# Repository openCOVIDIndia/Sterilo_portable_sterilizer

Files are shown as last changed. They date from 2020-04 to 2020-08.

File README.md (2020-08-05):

# Sterilo - Portable UV-C Steriliser
## Version 2 is here 
### Prototyping and Validation Stage





# Version 1 
## Fully developed and documented

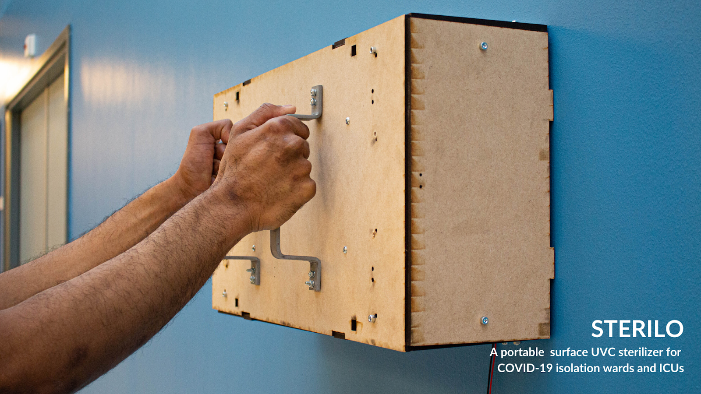
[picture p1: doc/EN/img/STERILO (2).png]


Sterilo is an open-source, low-cost portable UV-C sterilizer for decontaminating common surface touchpoints in isolation wards and ICUs. It is designed to be DIY-friendly, allowing the possibility of decentralised manufacturing using locally  available materials.

## [For more information on UV research and contributors, read our wiki](https://github.com/openCOVIDIndia/Sterilo_portable_sterilizer/wiki)

## Background 

Amidst the raging coronavirus pandemic, sterilization of surfaces and common touch points is the key to prevent cross contamination between patients and healthcare workers and to enhance treatment, within isolation wards and Intensive care units (ICU).

Current surface disinfection methods involve spraying Sodium Hypochlorite solution (NaClO) [1] and alcohol wipes, and rinsing after a waiting time of 30 minutes, repeated 3 times a day. These methods are however not effective [2] against many microbes like bacterial spores [3] and in surfaces with high viral loads. Hence, sterilization is preferred over just disinfection. Even high level disinfectants like 2% glutaraldehyde [4] are ineffective unless exposed for 12 hours. Besides, when the healthcare workers directly come in contact (touch) with these infected surfaces while treating patients, they become carriers of infection, leading to a higher risk of COVID-19 transmission [5] within the isolation ward /ICU.

On the other hand, autoclaves are the gold standard in sterilizing smaller instruments used in ICUs and Isolation wards. Each autoclave cycle takes 30 minutes while the drying process takes an hour to remove steam residue on the instruments.  However, a surge in coronavirus patients in a given hospital might lead to exceeding the capacity of autoclaves.  

There are other disinfection methods such as Fumigation, which uses high level disinfectants like Formaldehyde [7] and Glutaraldehyde [8,9]. This method requires 10 hours of exposure time [10] and another 24 hours for the fumes to be ventilated, after fumigation is carried out in a room. However, currently in many of the Indian government hospitals, the operations resume 30 minutes, that too in poorly ventilated rooms after the fumigation which renders healthcare workers exposed to its harmful fumes. Harmful effects [11,12] include mucous membrane irritation, pulmonary symptoms, Epistaxis, allergic contact dermatitis, asthma.

Ultraviolet radiation is an effective sterilization method, commonly found in Biosafety cabinets. The spectrum between 254nm to 265nm usually called UV-C has the maximum germicidal effect.[13] However, this method is currently not used in hospitals due to its harmful effects to human beings on exposure like skin cancer and eye damage [14].

Existing UVC Sterilizer robots [15] and trolley models [16] that are being introduced in the market to sterilize isolation wards require the people in the ward to vacate the ward while it sterilizes, since it places patients at risk of exposure to UVC radiation. But vacating is not logistically feasible, especially in Indian government hospitals. Hence the main need is to effectively sterilize frequently touched surfaces without causing harmful effects to patients and healthcare workers.

<p float="left">
    
  
   
</p>

## Need
- ### Surfaces:
Effective sterilization methods for fixed touch points (surfaces) within isolation wards and ICUs.

- ### Complement autoclaves
Supplementary sterilization for instruments, in addition to autoclaves, to reduce their overuse.

- ### Need for reuse of Personal protective equipment
Reuse of N-95 respirators for non-medical staff so that it is available to medical staff working in high viral loads like in isolation wards and ICUs.

# Solution

Sterilo, a portable surface sterilizer that uses UV-C radiation to sterilize common touch points within ICUs and isolation wards, even while the patient is present in its proximity and no special shielding is required. Safety features have been incorporated to avoid accidental exposure to UVC radiation, such that only when it's clamped onto the surface, the UV lamps turn ON.

Sterilo can be used in two configurations:
## A) Clamped onto surfaces
It features suction cups that clamp onto any surface. (See picture below). Once turned ON, the sterilization process runs for 20 minutes and turns off automatically with a beep, so that the user can unclamp it and place it on the next surface.

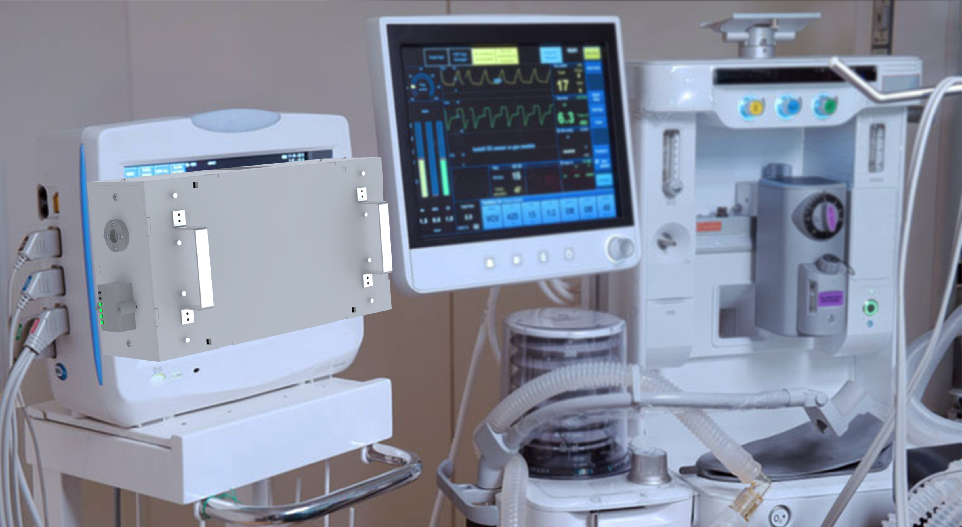
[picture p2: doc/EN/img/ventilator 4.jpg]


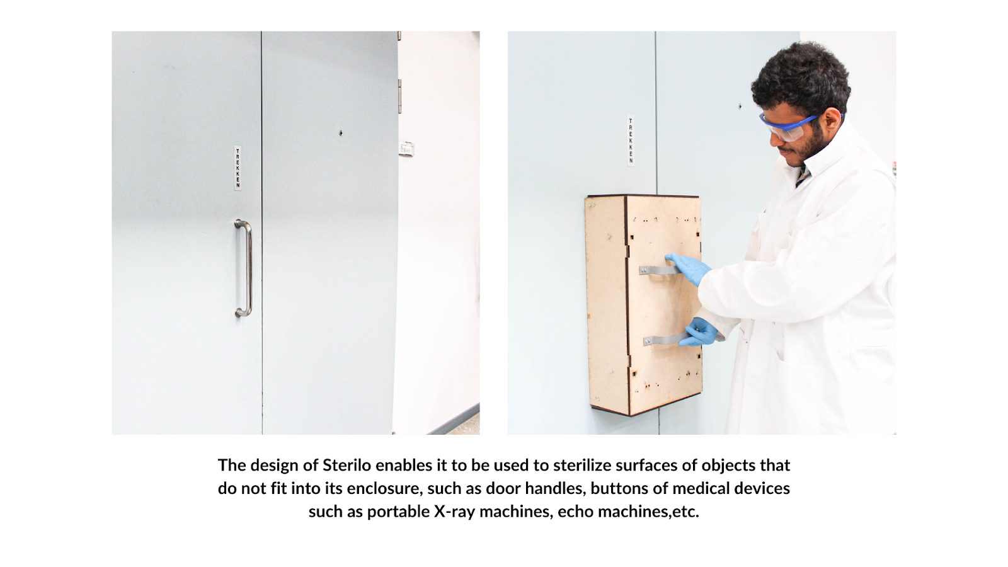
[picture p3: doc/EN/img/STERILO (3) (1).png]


## B) Box type
where a lid with an additional UV-C lamp is placed over configuration A. It is designed to hold most small instruments (for compatibility list see below). A removable mesh holds the instruments in place, while two UV-C lamps below ensures all surfaces of an object are completely exposed.

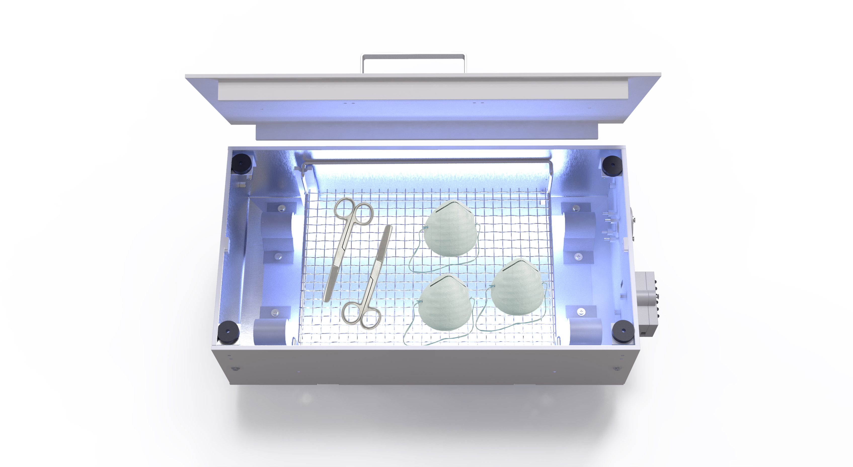
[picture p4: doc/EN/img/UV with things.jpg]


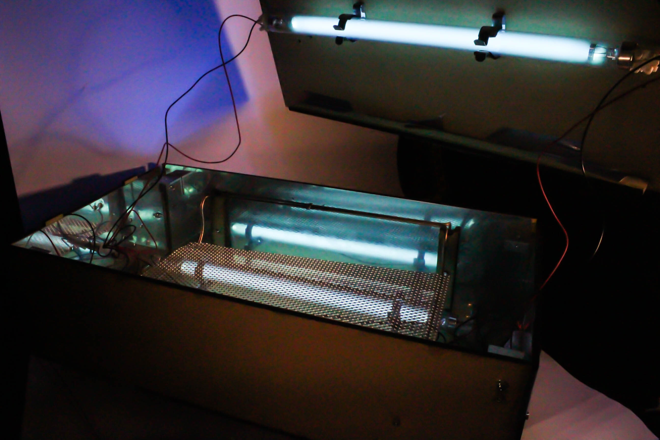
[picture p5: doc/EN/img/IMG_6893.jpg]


It is designed to sterilise most of the common touch points within isolation wards and ICUs in hospitals which includes buttons of vital monitors, ventilators, breathing units, pulse oximeters, contact thermometers, N95 masks, other touchpoints such as door handles, plugs, sockets, buttons of control units such as portable X-ray machines, echo machine controls for cardiac patients etc and even surgical equipments such as scissors, shears and tongs. The product is aimed at hospitals, makeshift wards and testing labs.

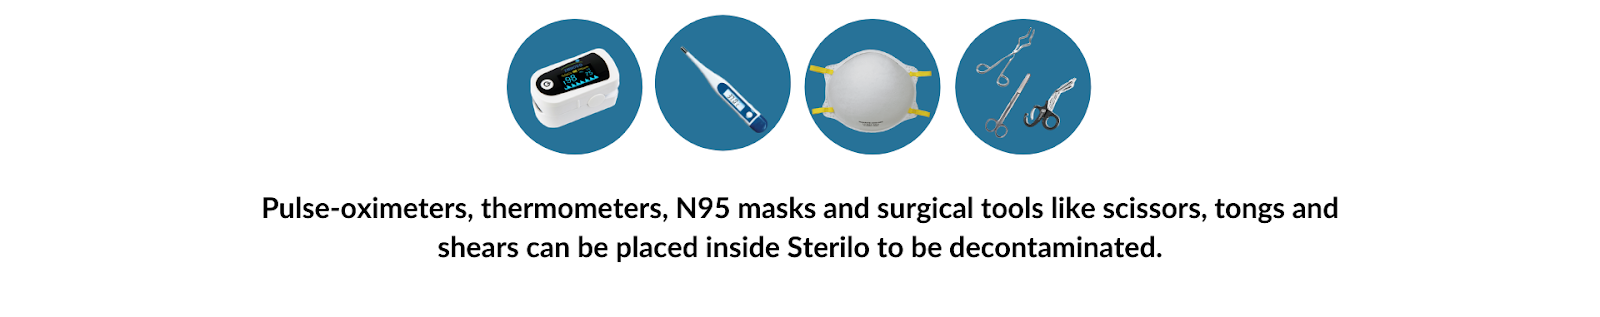
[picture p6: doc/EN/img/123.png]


Helps sterilise the following categories of objects:

- Oximeters: In isolation wards, for severe cases of patients with heart ailments, who also belong to the high risk category of COVID-19, they are monitored with oximeters
- Thermometers: At present, most of the hospitals avoid contactless thermometers because of its inaccuracy, and still rely on normal thermometers which might have more chances of being exposed to a viral load owing to it coming to contact with the COVID-19 patients.
-  N95 Masks: Flow rates drop 1.2 percent every time it is sterilised. However, when there is a shortage of N95 masks, it could be recommended to use the N95 masks after sterilisation. However the life cycle of the N95 masks have to be taken into consideration. (Currently in the hospitals, the doctors go through 6 hour shifts four times a day i.e after every six hour shift, they would need to either reuse the N95 mask or get a new one)
-  Door handles, plugs, sockets (which normally dont fit into an autoclave), surgical equipments such as scissors, clamps, tongs etc
- Buttons of commonly used control units such as portable X-ray machines, breathing unit controls, echo-machine control for cardiac patients and so on.

## Main Features

- DIY- like construction, designed for easy assembly 
- Uses extremely low cost, "off-the-shelf" parts
- Easily replicable using only laser cutting and 3D printing
- Unit mountable onto any surface to sterilize fixed objects
- Unit convertible to an enclosed box: for handheld medical tools
- Innovative design based on adopting UV-C technology in a safe and user-friendly way in a medically accepted standard.
- Shadow elimination- overall illumination by UV-C lamps
- Limit switches avoid UV exposure even in case of mishandling/unintended use cases.
- Durable and Robust Polycarbonate encasing, with sheet metal shielding
- Passive cooling system: avoids fire in case of too much heating
- Miniature Circuit Breaker at power source: to avoid short circuiting, with a 8A fuse next to it, for extra protection
- We invite anyone who is interested to follow this work.

## Experts

Interviews conducted with the following experts during the design process

- Dr. Amar, Field Doctor, Corona Ward, Pune
- Dr. Pravin Deokate, MS Ortho, Sassoon Hospital, Pune
- Dr. Abhiraj Matre, MS Ortho, Sion Hospital, Mumbai
- Dr. Abhinav Gupta, Associate Professor, Jammu University of Internal Medicine
- Dr. Atul Dhakne
- Dr. Mohammed Azhar, Apollo Hospitals, Chennai
- Dr. Sowmya Lakshminarayanan, Post Doctoral Researcher in Microbiology from Padova University, Italy
- Dr. Ram, Manila Hospital
- Dr. Gopalakrishnan.D.R.

## Status of Development

The device is currently under development, a first metal prototype is being realised.

| Date | Event |
| --- | --- |
| 23/03/2020  | Start of the project  |
| 05/04/2020  | Research and Need Assessment  |
| 27/03/2020  | Product Development (First iteration)  |
| 30/03/2020  | Concept Development (Second Iteration) |
| 12/04/2020  | First CAD Release Online |
| 13/04/2020  | Prototyping second iteration |
| 18/04/2020  | Expected Date of Completion of the second iteration |

## How to replicate 
See [Assembly Instructions](doc/EN/assembly_instructions.md)

# References
References:
- [1] Weber, D. J., Barbee, S. L., Sobsey, M. D., & Rutala, W. A. (1999). The effect of blood on the antiviral activity of sodium hypochlorite, a phenolic, and a quaternary ammonium compound. Infection Control & Hospital Epidemiology, 20(12), 821-827.
- [2] Koo, D., Bouvier, B., Wesley, M., Courtright, P., & Reingold, A. (1989). Epidemic keratoconjunctivitis in a university medical center ophthalmology clinic; need for re-evaluation of the design and disinfection of instruments. Infection Control & Hospital Epidemiology, 10(12), 547-552
- [3, 4] Rutala, W. A., & Weber, D. J. (2008). Guideline for disinfection and sterilization in healthcare facilities, 2008.
- [5] Rheinbaben, F. V., Schünemann, S., Gross, T., & Wolff, M. H. (2000). Transmission of viruses via contact in ahousehold setting: experiments using bacteriophage φX174 as a model virus. Journal of Hospital Infection, 46(1), 61-66.
- [7] Klein, M. (1963). The inavtivation of viruses by germicides. Proc Annu Meet Chem Spec Manuf Assoc, 116-118.
- [8] Gorman, S. P., SCOTT, E. M., & Russell, A. D. (1980). Antimicrobial activity, uses and mechanism of action of glutaraldehyde. Journal of Applied Bacteriology, 48(2), 161-190.
- [9] Scott EM, Gorman SP. Glutaraldehyde. In: Block SS, ed. Disinfection, sterilization, and preservation. Philadelphia: Lippincott Williams & Wilkins, 2001:361-81.
- [10] Zaidi, M., Angulo, M., & Sifuentes-Osornio, J. (1995). Disinfection and sterilization practices in Mexico. Journal of hospital infection, 31(1), 25-32.
- [11] Schnuch, A., Uter, W., Geier, J., Frosch, P. J., & Rustemeyer, T. H. (1998). Contact allergies in healthcare workers. Results from the IVDK. Acta dermato-venereologica, 78(5).
- [12] Wiggins, P., McCurdy, S. A., & Zeidenberg, W. (1989). Epistaxis due to glutaraldehyde exposure. Journal of occupational medicine.: official publication of the Industrial Medical Association, 31(10), 854-856.
- [13] Russell AD. Ultraviolet radiation. In: Russell AD, Hugo WB, Ayliffe GAJ, eds. Principles and practices of disinfection, preservation and sterilization. Oxford: Blackwell Science, 1999:688-702.
- [14] Sensakovic, J. W., & Smith, L. G. (1982). Nosocomial ultraviolet keratoconjunctivitis. Infection Control & Hospital Epidemiology, 3(6), 475-477.
- [15] “Autonomous Robots Are Helping Kill Coronavirus in Hospitals” IEEE Spectrum: Technology, Engineering, and Science News, spectrum.ieee.org/automaton/robotics/medical-robots/autonomous-robots-are-helping-kill-coronavirus-in-hospitals
- [16] “Flight of the GermFalcon: How a Potential Coronavirus-Killing Airplane Sterilizer Was Born,” IEEE Spectrum: Technology, Engineering, and Science News. [Online]. Available: https://spectrum.ieee.org/tech-talk/aerospace/aviation/germfalcon-coronavirus-airplane-ultraviolet-sterilizer-news.

<!-- # Steps to start documenting the equipment/design you found and chose 
[See this documentation example](https://github.com/CombatCovid/medical-shields-for-3d-printing). You can also download it to see the final result.
1. Download or clone this template to start documenting easily
2. Fill in the source files like STLS, CAD, etc inside

3. Use this one template to create new designs documentation
- Inside docs write down a simple README in language of choice.
- Put in the README.md the reference whre you got the source from to follow up.
- Write down steps to replicate if necessesary as well as guides in sequence.
If this part becomes difficult ask for help here in the [`#how-to-document-designs` channel ]()
 -->

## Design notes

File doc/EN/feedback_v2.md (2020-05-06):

# Feedback for prototype V2.0

| Reference | Feedback | How are we addressing?  |
| --- |:---| :-----|
| Mrs. Deepa | UV-C has the potential to cause cancer. Has her team addressed it? Can she elaborate on that in the Github write up? She says no shields are required | See [FAQ](https://github.com/openCOVIDIndia/Sterilo_portable_sterilizer/blob/master/doc/EN/FAQ.md)|
| Keshav Swarup | Plastics-not to be used in UVC sterilizer.  | See [material_research](https://github.com/openCOVIDIndia/Sterilo_portable_sterilizer/blob/master/doc/EN/material_research.md) |
| Dr.Balachandran | Good idea. There is some discussion of UV sterilisation of FFP2 / FFP3 masks throughout the world but still not yet established. Was there any test done on mask pre and post UV radiations? |  To be looked into |
| Dr.Maria | So firstly. This comes across as a machine to decontaminate things that are touched or used on or by the patient. My point of view is any decontamination is good at this point. However, objects that may have body fluids such as thongs, scissors etc would need the main type of  surgical cleaning. IMO. This is good for pulse oximeter,  blood pressure cuff, pens, stethoscope, clipboards...stationery items etc  |  FIXME|

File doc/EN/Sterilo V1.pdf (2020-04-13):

## github: opencovidindia

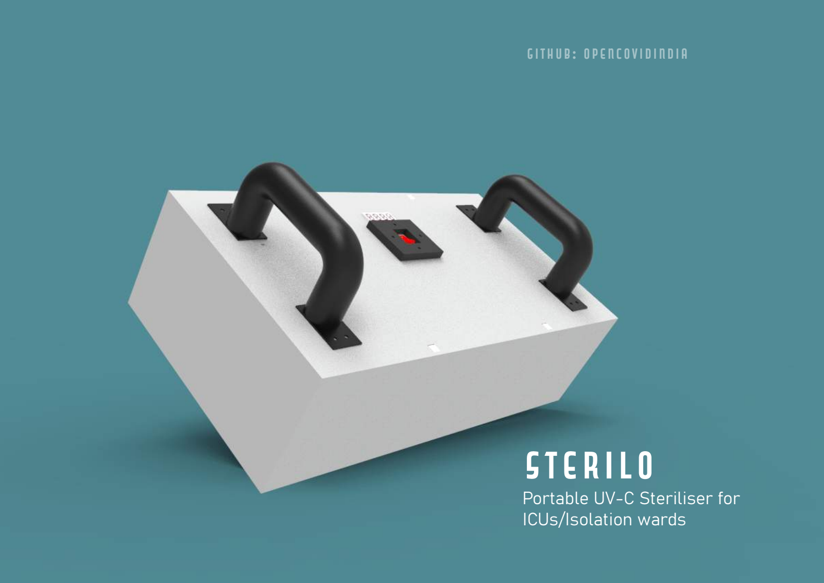
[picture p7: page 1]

# Sterilo

## Portable UV-C Steriliser for ICUs/Isolation wards

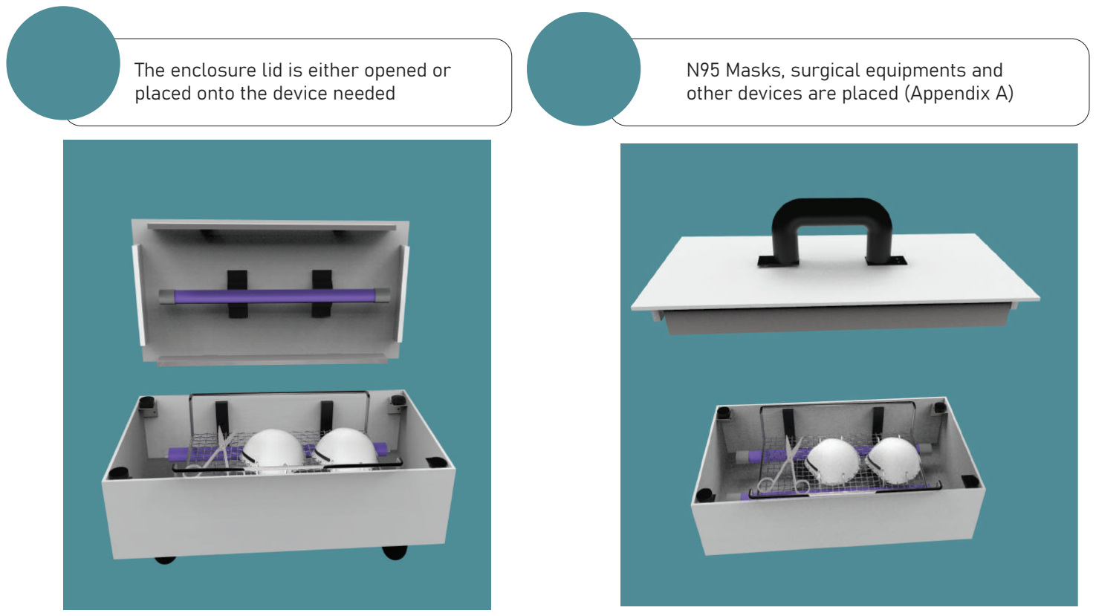
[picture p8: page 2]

The enclosure lid is either opened or placed onto the device needed

N95 Masks, surgical equipments and other devices are placed (Appendix A)

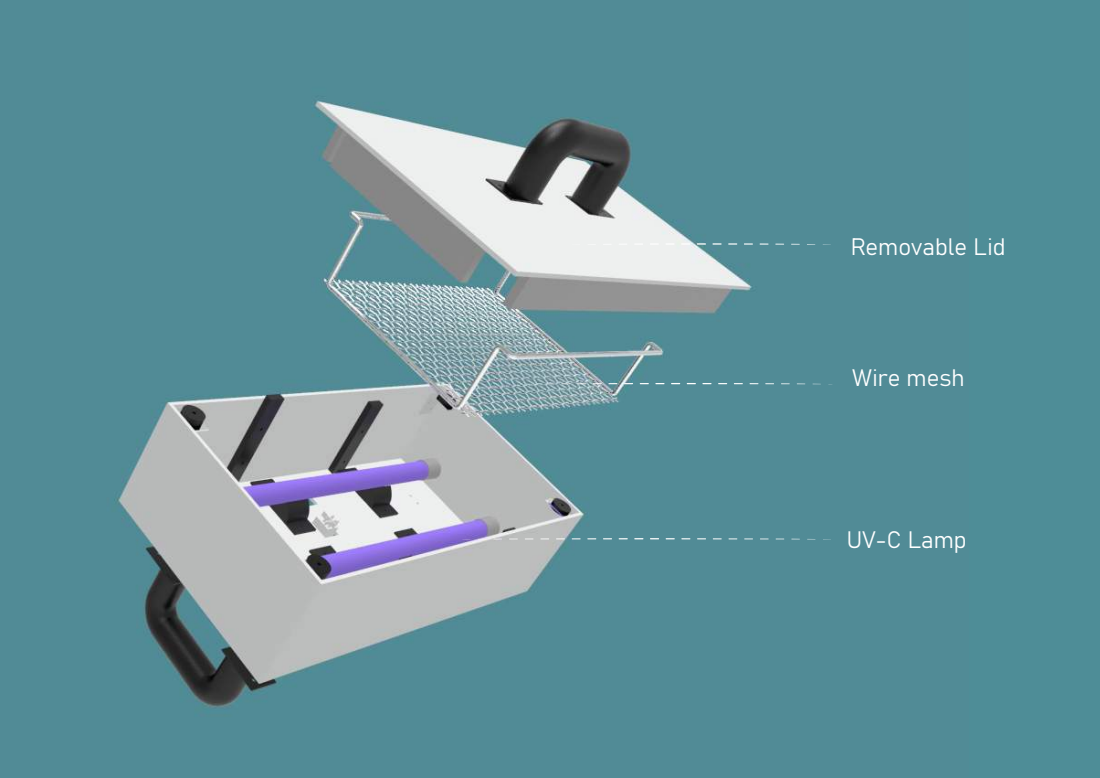
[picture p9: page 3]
Removable Lid; Wire mesh; UV-C Lamp

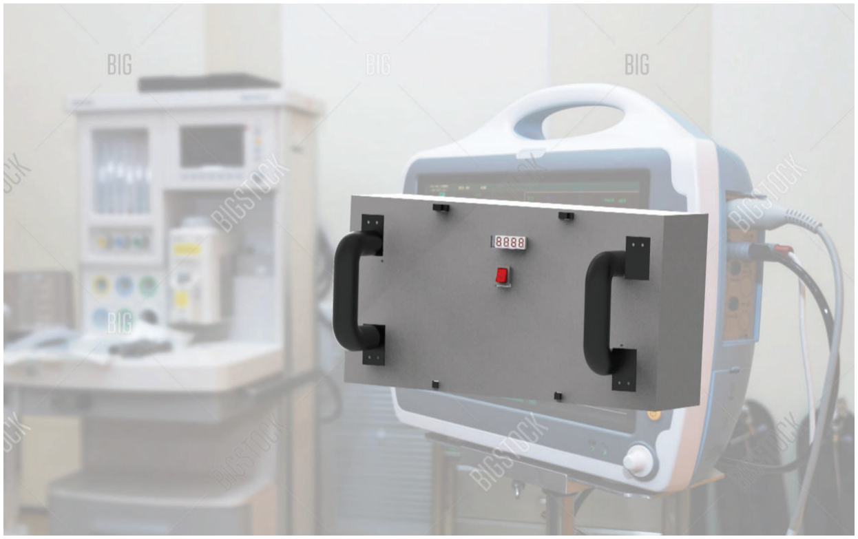
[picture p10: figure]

# Appendix a

## Helps sterilise the following categories of objects

Oximeters: In isolation wards, these are commonly used for saturated blood pressure monitoring of patients coming under the high risk category of COVID-19

Thermometers: At present, most of the hospitals avoid contactless thermometers because of its inaccuracy, and still rely on normal thermometers which might have more chances of being exposed to a viral load owing to it coming to contact with the COVID-19 patients.

N95 Masks: Flow rates drop 1.2 percent every time it is sterilised. However, when there is a shortage of N95 masks, it could be recommended to use the N95 masks after sterilisation. However the life cycle of the N95 masks have to be taken into consideration. (Currently in the hospitals, the doctors go through 6 hour shifts four times a day i.e after every six hour shift, they would need to either reuse the N95 mask or get a new one)

Door handles, plugs, sockets (which normally dont fit into an autoclave)

Surgical equipments such as scissors, clamps, tongs etc

Buttons of commonly used control units such as portable X-ray machines, breathing unit controls, echo-machine control for cardiac patients and so on.

## References

Moore, G., Ali, S., Cloutman-Green, E. A., Bradley, C. R., Wilkinson, M. A., Hartley, J. C., ... & Wilson, A. P. R. (2012). Use of UV-C radiation to disinfect non-critical patient care items: a laboratory assessment of the Nanoclave Cabinet. BMC infectious diseases, 12(1), 174.

Lindblad, M., Tano, E., Lindahl, C., & Huss, F. (2019). Ultraviolet-C decontamination of a hospital room: Amount of UV light needed. Burns.

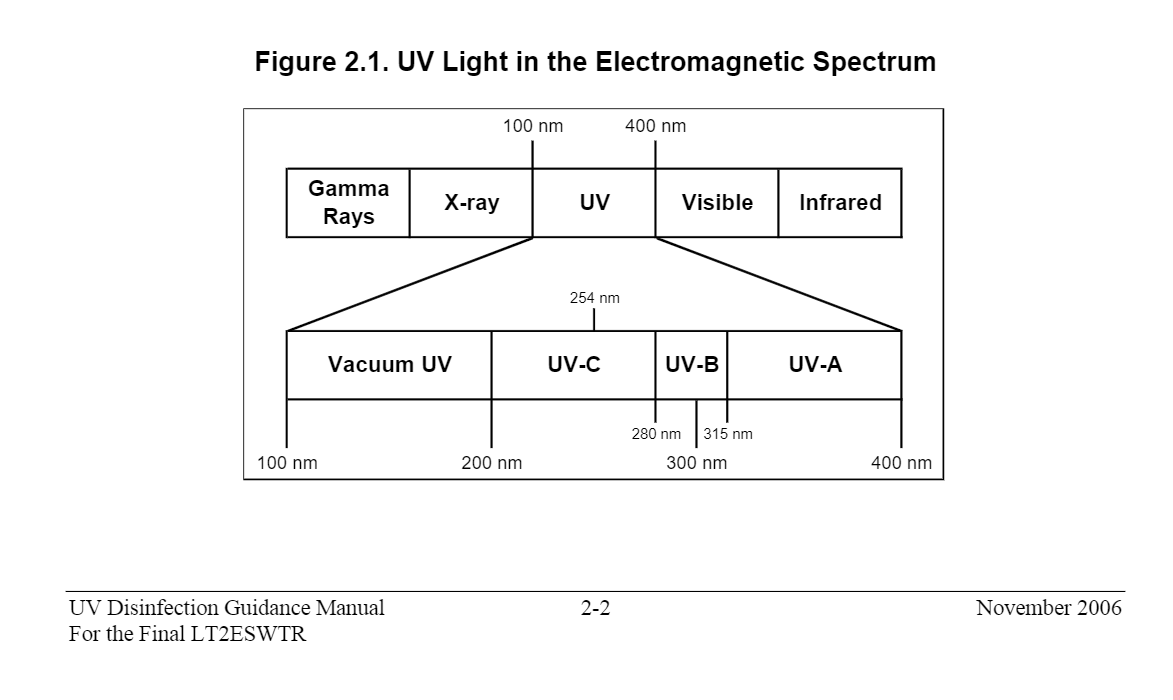
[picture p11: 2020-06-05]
doc/EN/img/research/EM_Spectrum.jpg

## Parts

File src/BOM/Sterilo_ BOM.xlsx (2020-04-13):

S No | Component | Specification | Dimensions | Qty | Part Reference | Links | Buffer parts | Place | Per unit Price | Total price
1 | Polycarbonate Sheet | UV Resistant | Thickness: 5mm 1200 x 800mm | 1 |  |  | Plus 1 sheet | Laserbeest
2 | Stainless Steel rod | SS304 grade | Diameter: 6mm Length: 1600mm | 1 | Grill |  |  | Hornbach
3 | Aluminium Angle | Anodized | 40x40x2mm | 4 | Magnet support | https://www.hornbach.nl/shop/KAISERTHAL-Hoekprofiel-40x40x2-mm-aluminium-zilver-100-cm/6069586/artikel.html |  | Hornbach
4 | Stainless steel Bolts | M6 | Length: 50mm | 4 | Magnet target on top lid |  |  | Hornbach
5 | Stainless steel nuts | M6 | - | 8 | " |  |  | Hornbach
6 | Stainless steel washers | for M6 | - | 4 | " |  |  | Hornbach
7 | Arduino Nano | With headers |  | 1 |  | https://www.kiwi-electronics.nl/arduino-nano-every?search=nano&description=true |  | Kiwi
8 | Nano cable | - |  | 1 |  |  |  | Kiwi
9 | Aluminium foil roll | - | - | 1
10 | Plastic Epoxy adhesive | (check if PMB has it for PC) |  | 1 |  |  |  | PMB Lab
11 | Protoboard | - | 40x60mm | 1 |  | https://www.kiwi-electronics.nl/kw-2249?search=proto%20board&description=true |  | Kiwi electronics
12 | Philips TUV 25W | 1SL/25 model | Length: 437mm | 3 |  |  |  |  | 44.87
13 | Philips Ballast | IUV2S60 M4LD model |  | 3
14 | Limit Switch | OMRON SS-5GL |  | 2 |  | https://www.kiwi-electronics.nl/index.php?product_id=3776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 |  | Kiwi
15 | Rocker switch | Sparkfun COM-11155 model |  | 1 |  | https://www.kiwi-electronics.nl/sf-com-11155?search=rocker%20switch&description=true |  | Kiwi
16 | Sheet metal | 25 Guage | Thickness: 0.531mm | 1 | plastic casing inner side
17 | Metal mesh | Loosely woven; 10mm hole diameter | 1.6mm wire diameter 400 x 300mm | 1 | Mesh for grill |  |  | Hornbach
18 | M4 machine screws | Preferably stainless steel | Length: 20mm | 48 |  |  | Buffer + 20 | Hornbach
19 | M4 Penny washer | Preferably stainless steel |  | 10 |  |  | Buffer + 5 | Hornbach
20 | M4 Spring washers | Preferably stainless steel |  | 48 |  |  | - | Hornbach
21 | M4 nuts | Preferably stainless steel |  | 48 |  |  | Buffer + 10 | Hornbach
22 | M2 bolt | Preferably stainless steel |  | 4 |  |  | Buffer + 3 | Hornbach
23 | M2 Nuts | Preferably stainless steel |  | 4 |  |  | Buffer + 3 | Hornbach
24 | M6 machine screw | Preferably stainless steel |  | 12 |  |  |  | Hornbach
25 | M6 nuts | Preferably stainless steel |  | 24 |  |  |  | Hornbach

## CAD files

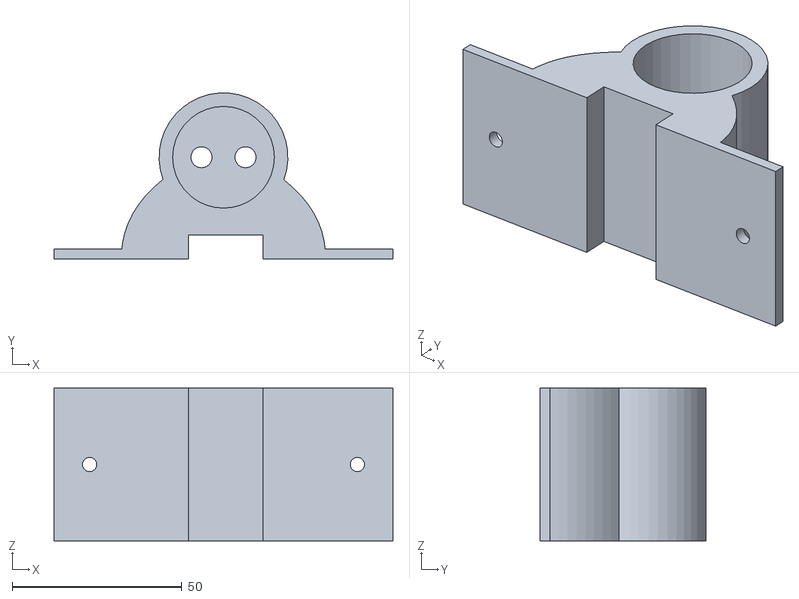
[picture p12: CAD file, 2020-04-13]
src/3D PRINTING/UV holder_whole.STL
100.0 x 48.9 x 45.0

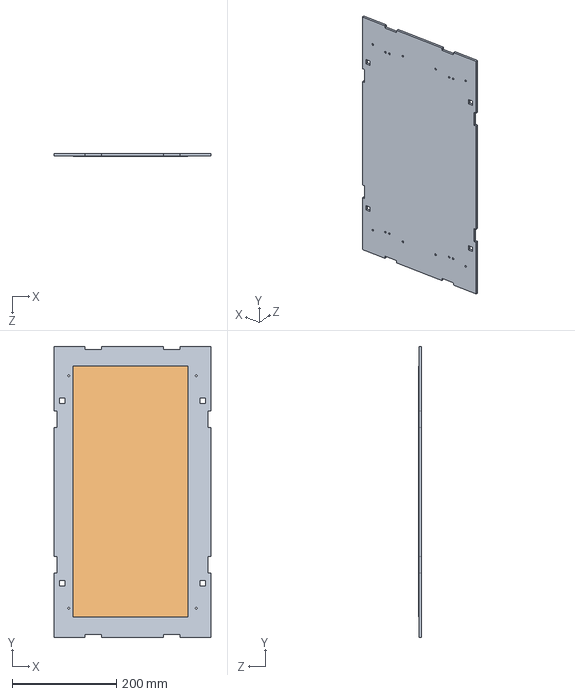
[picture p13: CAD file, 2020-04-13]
src/ASSEMBLY/SOLIDWORKS Files/Box_base_subassembly.SLDASM
300.0 x 557.0 x 5.53 mm
Dimensioned box
Sheet metal base

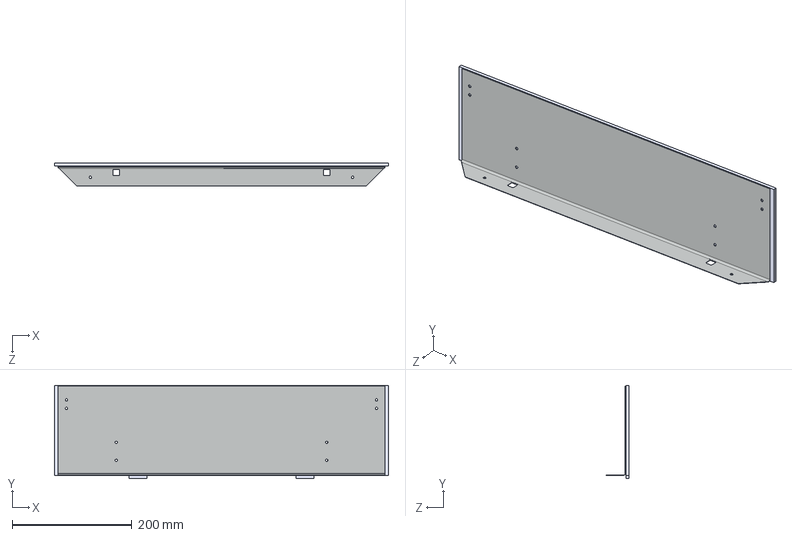
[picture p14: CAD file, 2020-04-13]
src/ASSEMBLY/STEP Files/Box_longer side subassembly.STEP
557.0 x 155.2 x 38.2 mm
Box_longer side
Sheet metal longer side

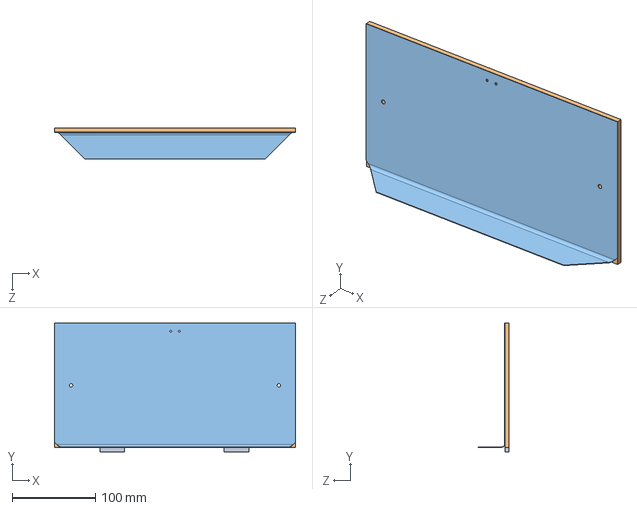
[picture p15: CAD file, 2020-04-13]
src/ASSEMBLY/STEP Files/Box_shorter side subassembly_V2_2.STEP
290.0 x 155.1 x 37.5 mm
Dimensioned Box_shorter side_2
Sheet metal shorter side_2

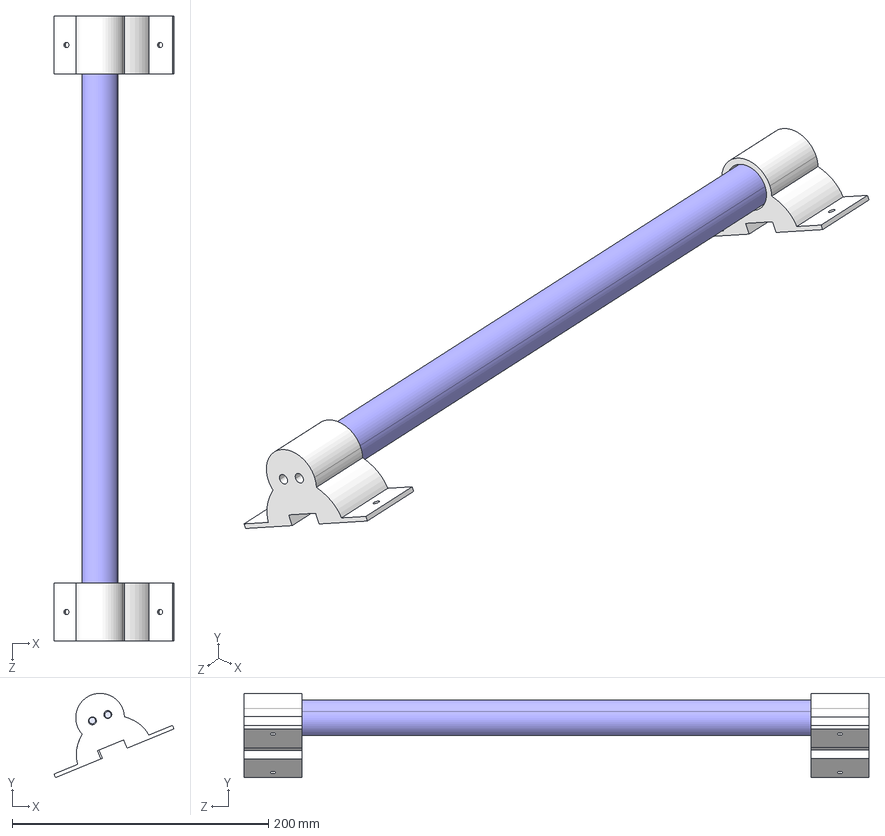
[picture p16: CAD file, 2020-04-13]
src/ASSEMBLY/STEP Files/UVC light subassembly.STEP
93.6 x 65.8 x 487.4 mm
TUV 25W 1SL_25 UV Lamp
UV holder_whole x 2

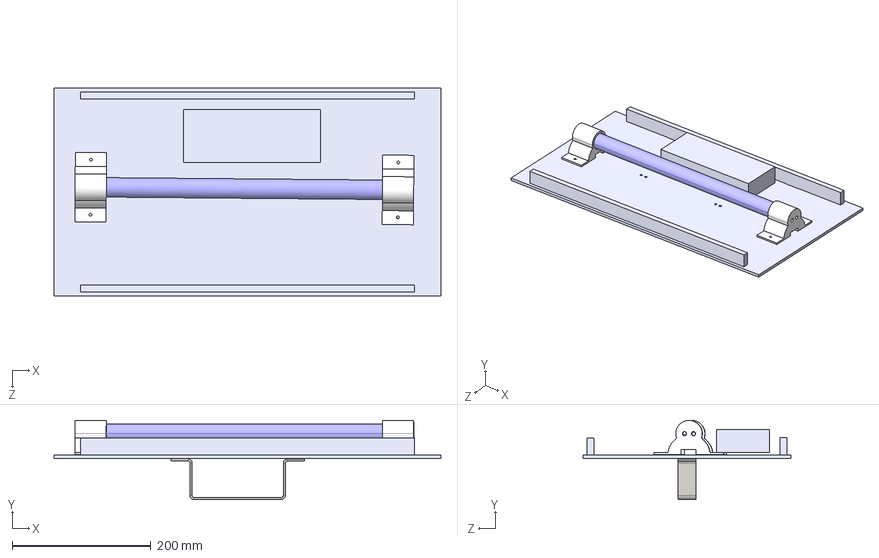
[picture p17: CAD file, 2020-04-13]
src/ASSEMBLY/STEP Files/Box_lid subassembly.STEP
557.0 x 114.0 x 300.0 mm
slider block_final x 2
PC Sheet_Lid
Metal handle
TUV 25W 1SL_25 UV Lamp
UV holder_whole x 2
IUV_2S60 Ballast

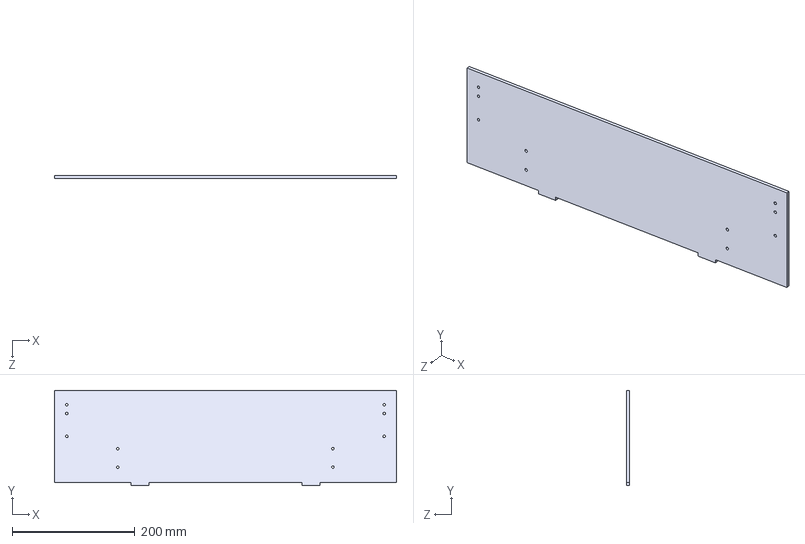
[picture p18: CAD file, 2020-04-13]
src/PARTS/STEP Files/PC Sheet_longer side.STEP
557.0 x 155.2 x 5.00 mm

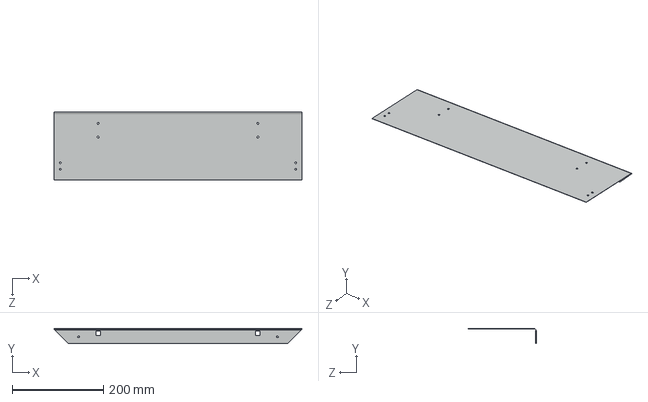
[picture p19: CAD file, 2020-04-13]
src/PARTS/STEP Files/Sheet metal longer side.STEP
545.0 x 32.5 x 149.5 mm

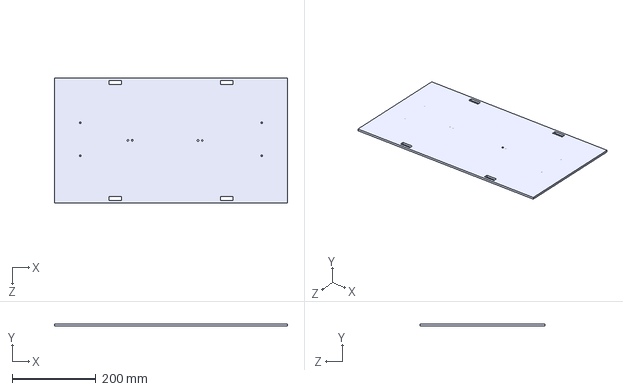
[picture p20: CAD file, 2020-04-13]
src/PARTS/STEP Files/PC Sheet_Lid.STEP
557.0 x 5.00 x 300.0 mm

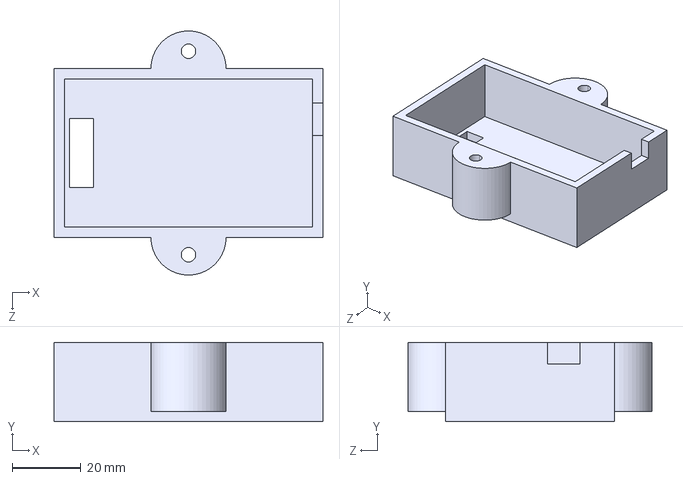
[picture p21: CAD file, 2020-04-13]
src/PARTS/STEP Files/Electronics casing bottom.STEP
78.0 x 23.0 x 70.8 mm

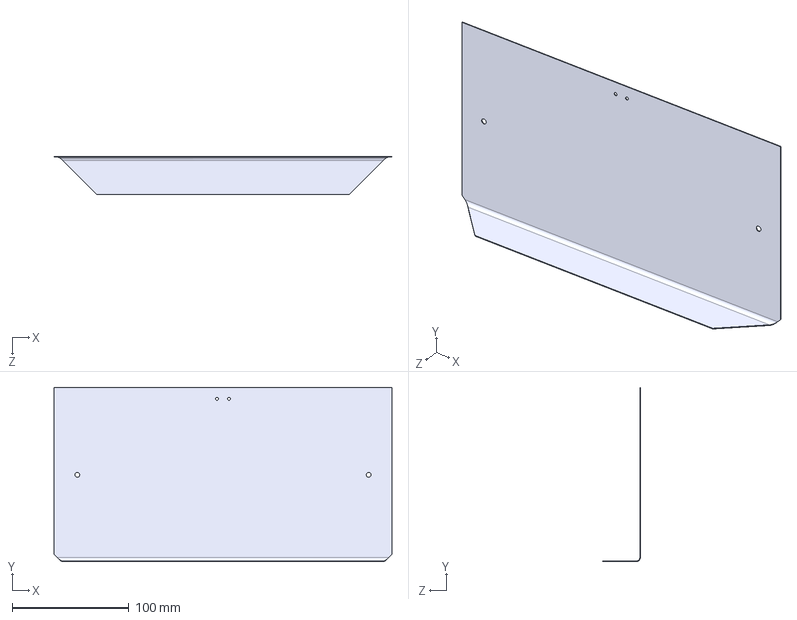
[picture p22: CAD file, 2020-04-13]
src/PARTS/STEP Files/Sheet metal shorter side_2.STEP
290.0 x 149.5 x 32.5 mm

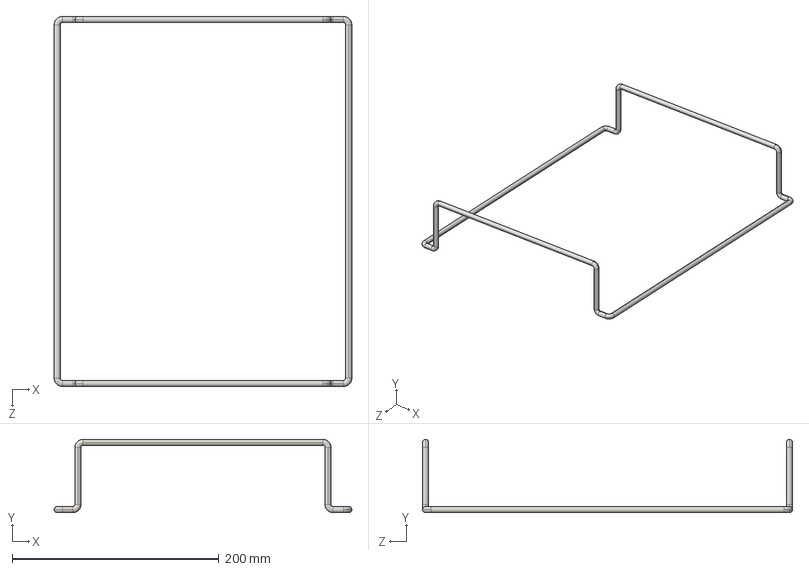
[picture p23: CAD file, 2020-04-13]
src/PARTS/STEP Files/Grill Frame.STEP
288.0 x 71.0 x 358.0 mm

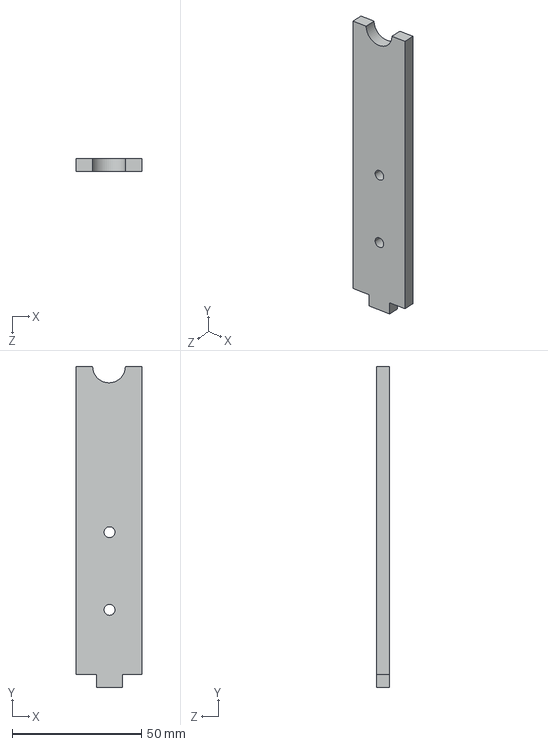
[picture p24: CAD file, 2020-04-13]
src/PARTS/STEP Files/Grill Support_Long.STEP
25.4 x 124.0 x 5.00 mm

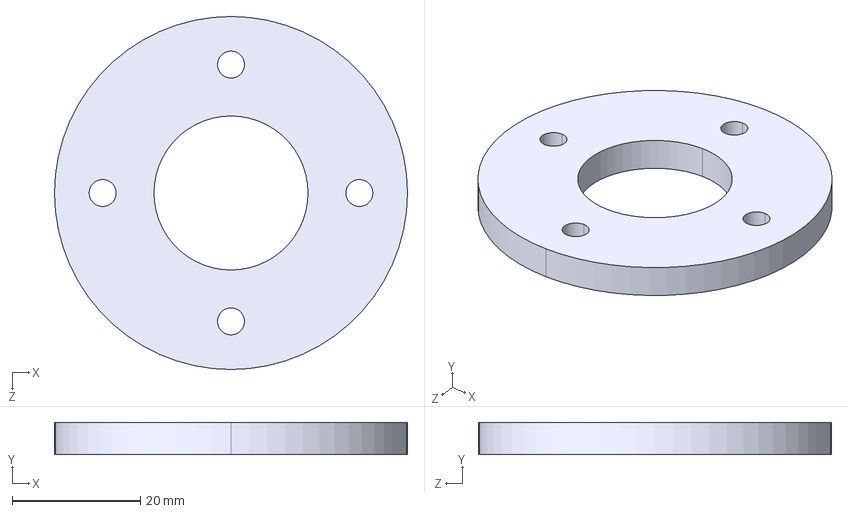
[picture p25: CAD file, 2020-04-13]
src/PARTS/STEP Files/Switch guard.STEP
55.0 x 5.00 x 55.0 mm

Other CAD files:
src/PARTS/STEP Files/Sheet metal shorter side.STEP
src/PARTS/STEP Files/PC Sheet_base.STEP
src/PARTS/STEP Files/PC Sheet_shorter side_2.STEP
src/PARTS/STEP Files/Sheet Metal_Base.STEP
src/3D PRINTING/Electronics casing bottom.STL
src/3D PRINTING/Electronics casing top.STL
src/ASSEMBLY/SOLIDWORKS Files/Box_lid subassembly.SLDASM
src/ASSEMBLY/SOLIDWORKS Files/Box_longer side subassembly.SLDASM
src/ASSEMBLY/SOLIDWORKS Files/Box_shorter side subassembly_V2_2.SLDASM
src/ASSEMBLY/SOLIDWORKS Files/Box_shorter side subassembly_v2.SLDASM
src/ASSEMBLY/SOLIDWORKS Files/UVC light subassembly.SLDASM
src/ASSEMBLY/STEP Files/Box_shorter side subassembly_v2.STEP
src/PARTS/SOLIDWORKS Files/Aluminium_Magnet holder.SLDPRT
src/PARTS/SOLIDWORKS Files/Electronics casing bottom.SLDPRT
src/PARTS/SOLIDWORKS Files/Electronics casing top.SLDPRT
src/PARTS/SOLIDWORKS Files/Grill Frame.SLDPRT
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

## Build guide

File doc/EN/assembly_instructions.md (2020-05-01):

# Assembly Instructions

## Tools Required:
1. Laser cutter
2. Sheet metal cutter (hand-lever / cutting machine)
3. Mitre saw/ Angle grinder
4. Vernier calliper
5. Ruler
6. Machine vice
7. Try square

## Preparatory:
1. Laser cut the [files](https://github.com/openCOVIDIndia/Sterilo_portable_sterilizer/tree/master/src/lasercut_files) using either MDF or Polycarbonate. Polycarbonate (PC) is much stronger than MDF, but due to unavailability due to lockdown, here MDF was used. You can find the illustrator files 

2. Cut the [sheet metal](https://github.com/openCOVIDIndia/Sterilo_portable_sterilizer/tree/master/src/drawing)'s outer boundaries using either a metal laser cutter or a sheet metal cutter/ hand lever).

3. Keep all components in the [Bill of materials](https://github.com/openCOVIDIndia/Sterilo_portable_sterilizer/blob/master/src/BOM/Sterilo_%20BOM.xlsx) handy. 

## Parts:

3. Cut the [angle_profiles](https://github.com/openCOVIDIndia/Sterilo_portable_sterilizer/blob/master/src/drawing/Aluminium_Magnet%20holder.PDF) and drill holes onto them. They act as the supports for the magnets. 

4. Mark the bending lines, slot and hole positions in the sheet metal according to drawing files. You should be getting six parts from this. 

5. Bend 4 mm aluminium/ stainless steel rod. If you dont have access to these, you can also use welding rods according to the diagram for making the [grill frame](https://github.com/openCOVIDIndia/Sterilo_portable_sterilizer/blob/master/src/PARTS/STEP%20Files/Grill%20Frame.STEP). If you do not have enough length, weld pieces together.

## Assembly
Put together the following sub-assemblies (MDF/PC with sheet metal facing inside)
- base
- longer side walls x 2
- shorter side wall (plain) x 1
- shorter side wall (with switch and controls) x 1

### Base subassembly
<p float="left">
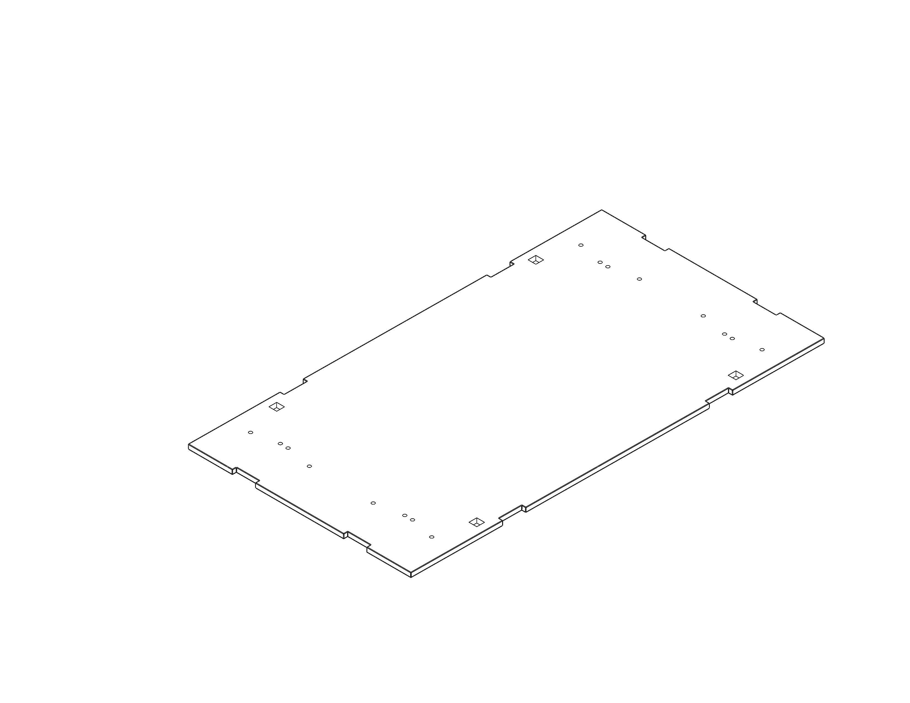
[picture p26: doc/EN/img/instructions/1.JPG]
    
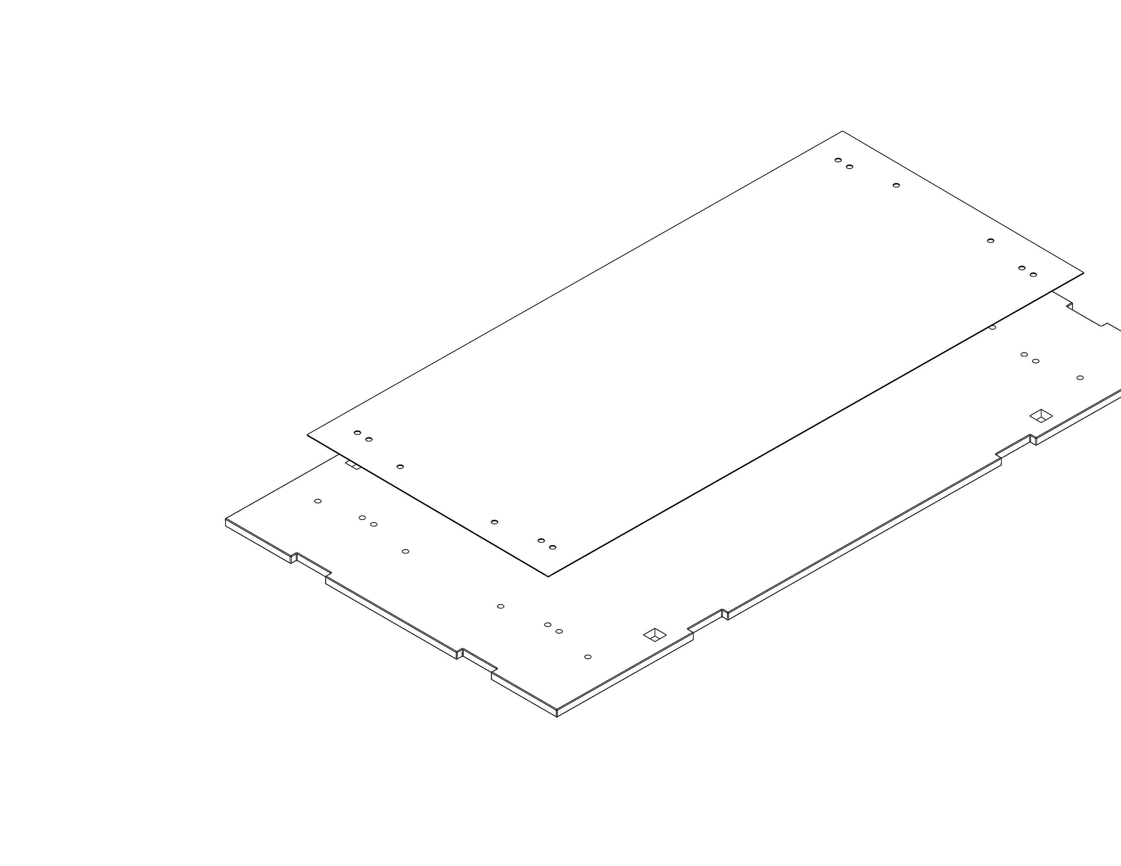
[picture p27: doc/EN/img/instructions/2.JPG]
  
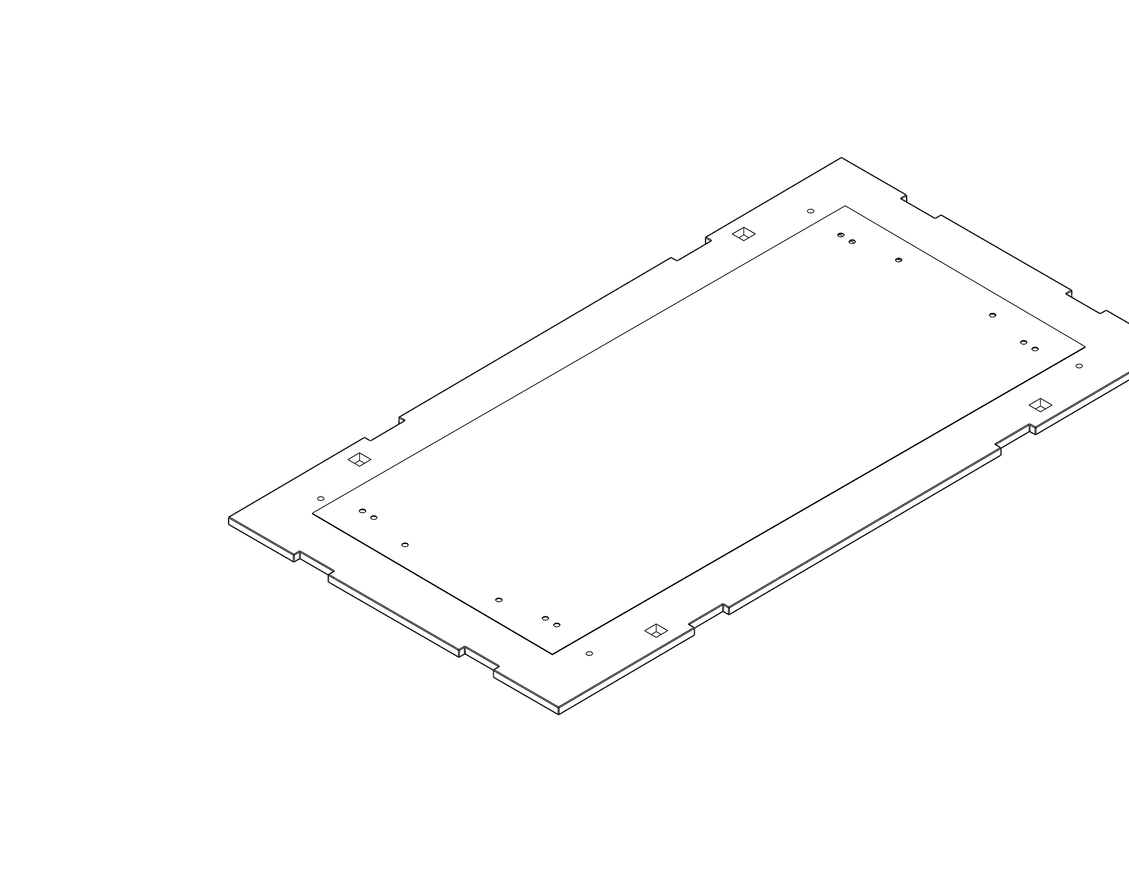
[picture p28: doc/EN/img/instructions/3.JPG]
   
</p>

### Make one of the shorter side walls (with switch and controls) subassembly
<p float="left">
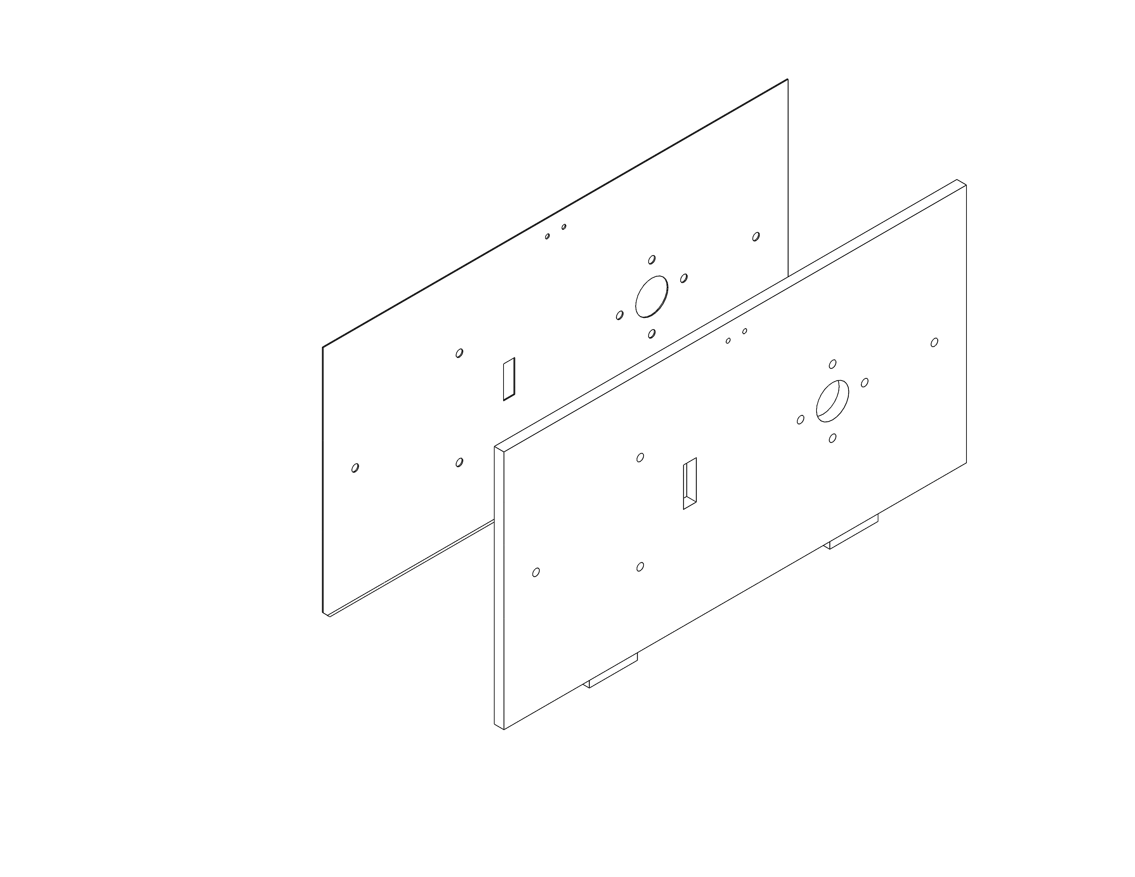
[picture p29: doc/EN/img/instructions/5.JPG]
    
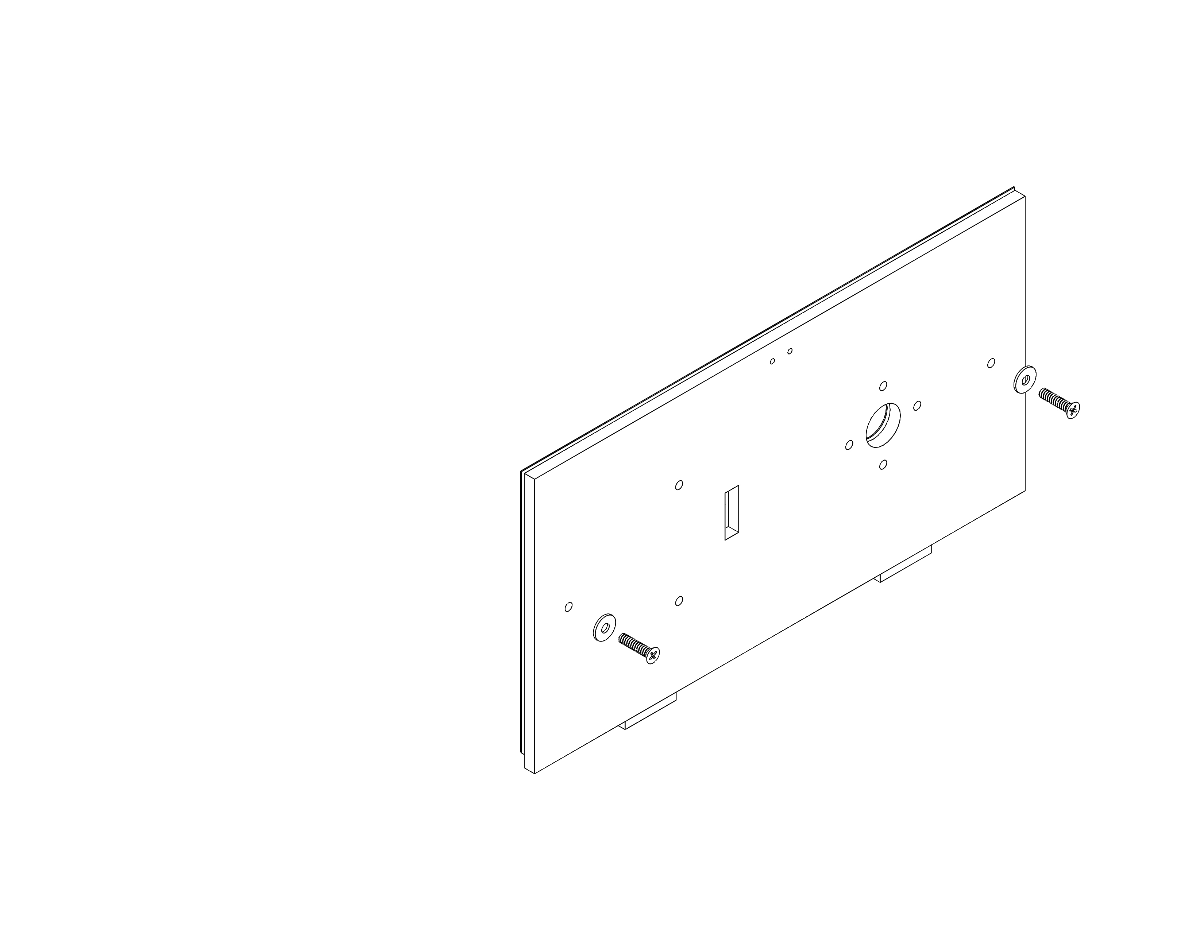
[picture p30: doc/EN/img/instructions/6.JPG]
  
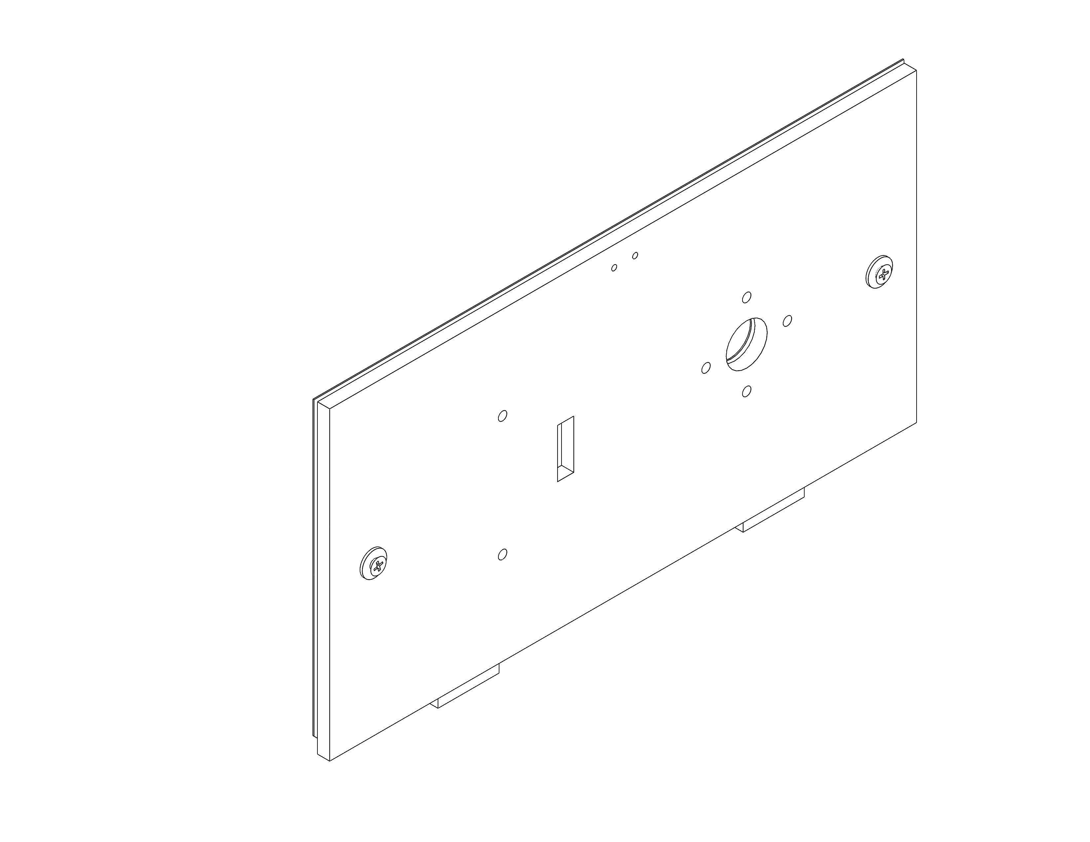
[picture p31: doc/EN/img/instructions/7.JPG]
   
</p>

### Fix electronics housing and rocker switch on the above mentioned side wall
<p float="left">
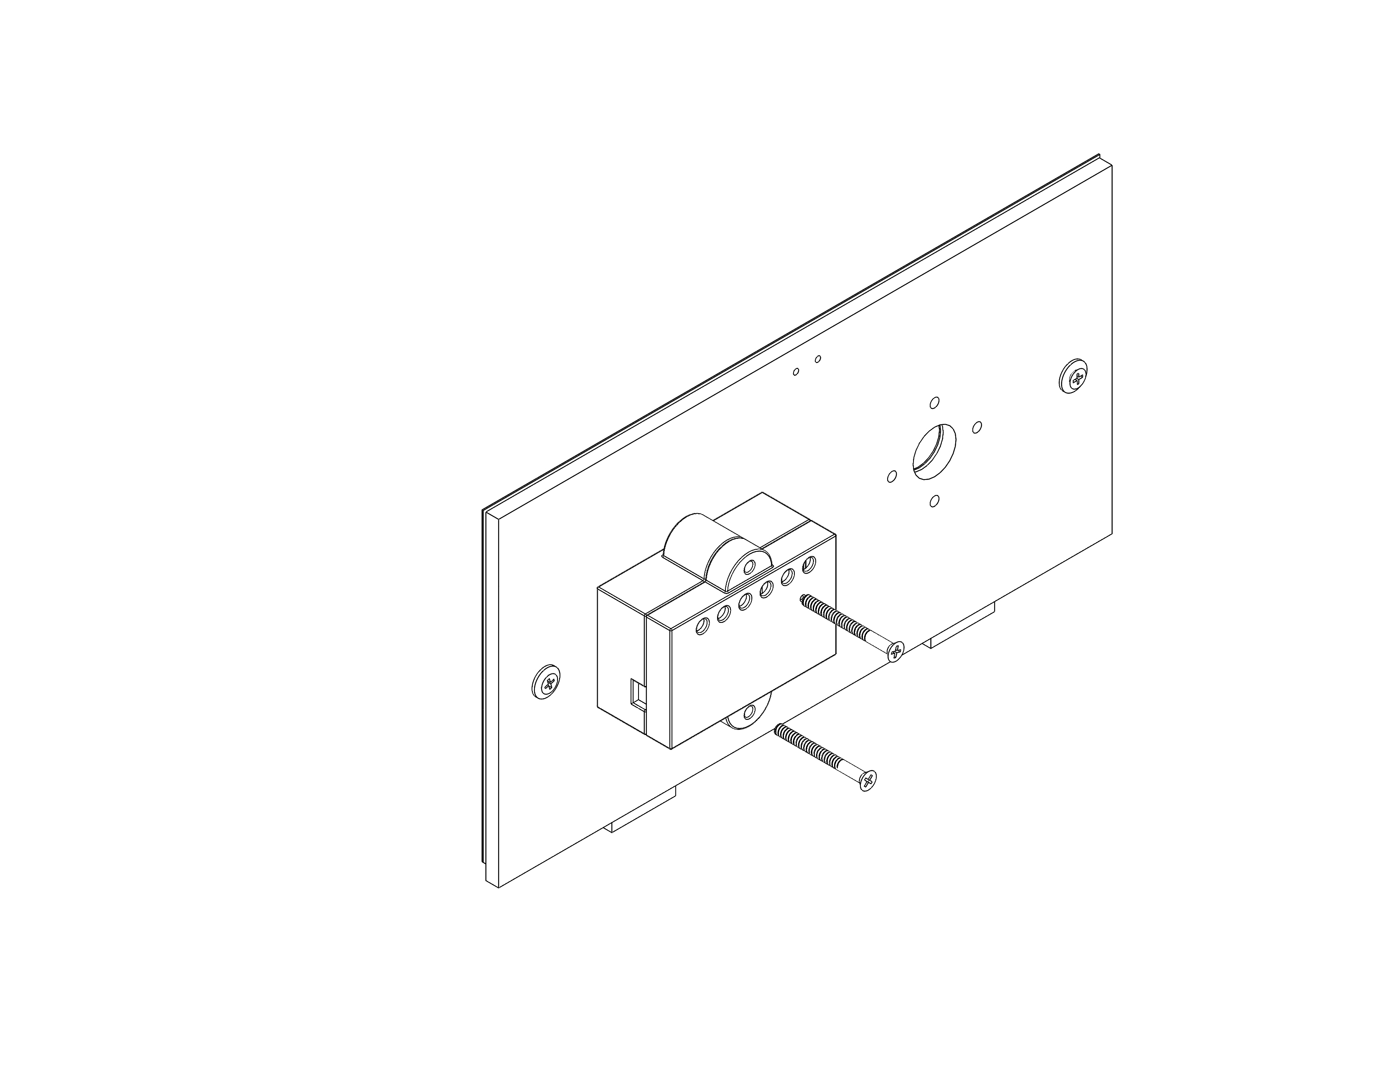
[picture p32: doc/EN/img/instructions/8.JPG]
    
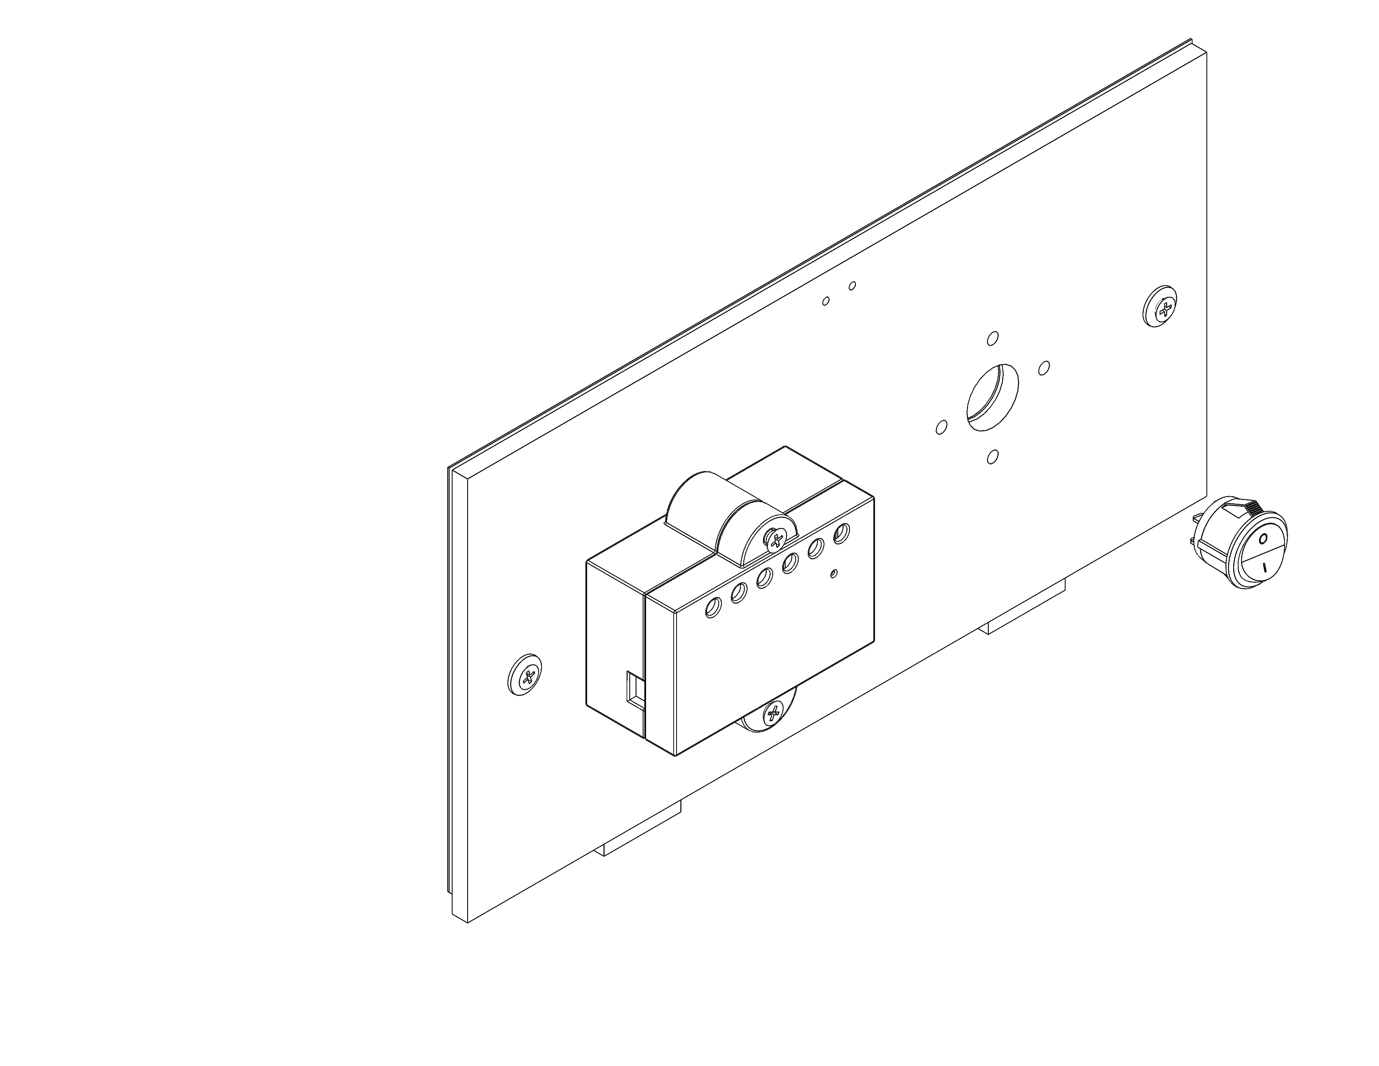
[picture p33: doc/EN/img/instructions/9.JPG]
  
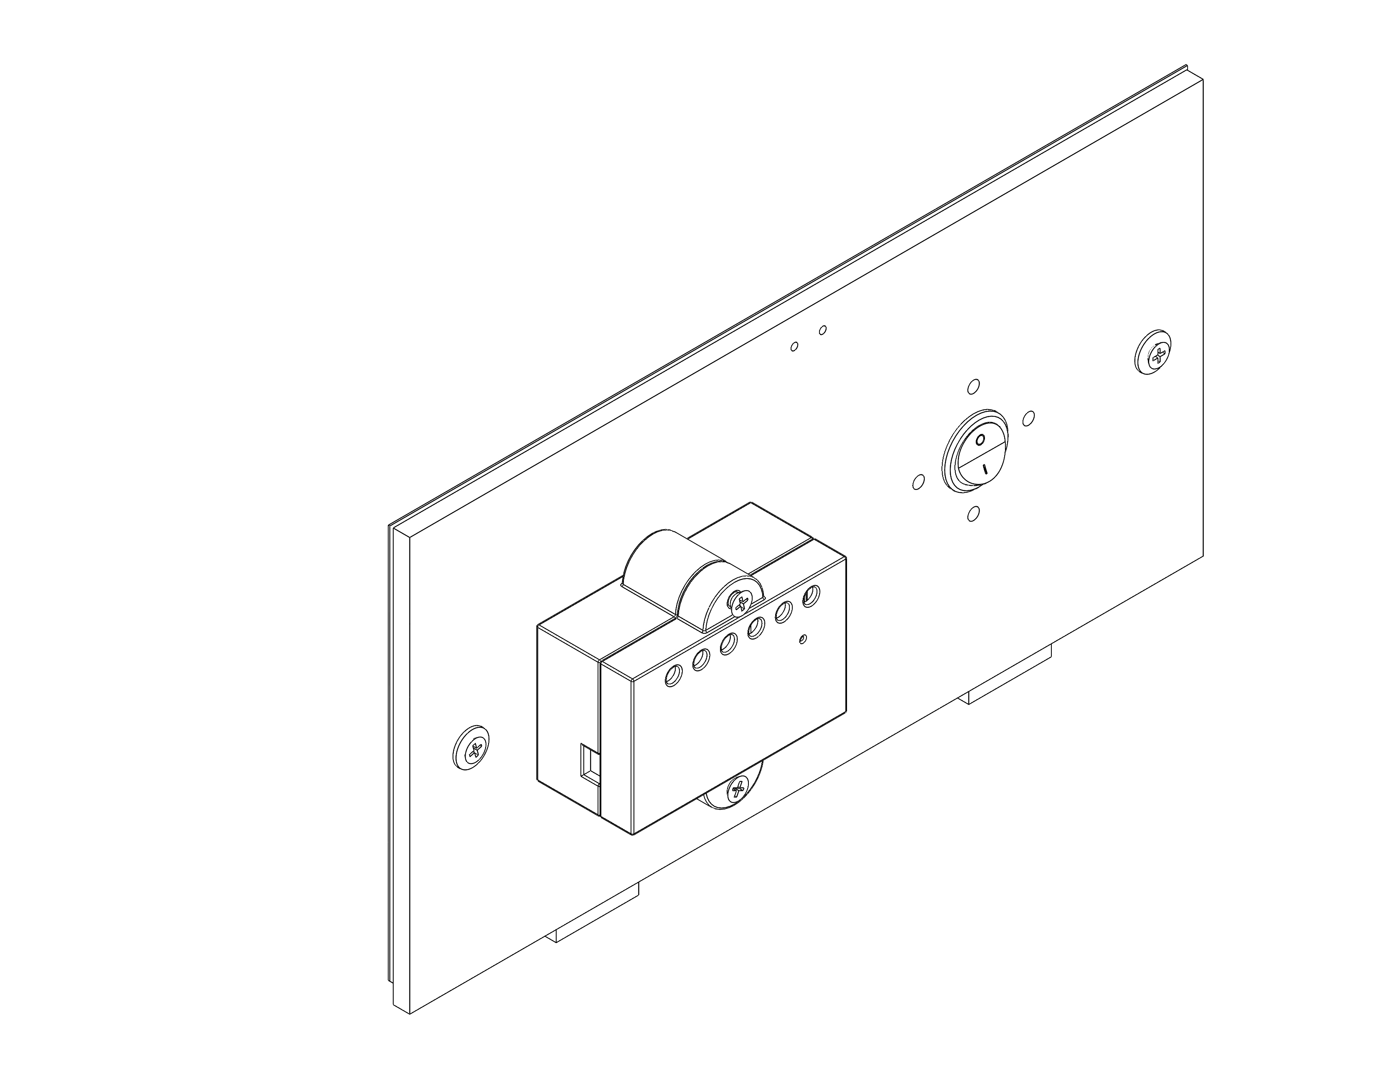
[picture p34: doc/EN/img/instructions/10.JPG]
   
</p>

### Fix the switch guard on the above mentioned side wall
<p float="left">
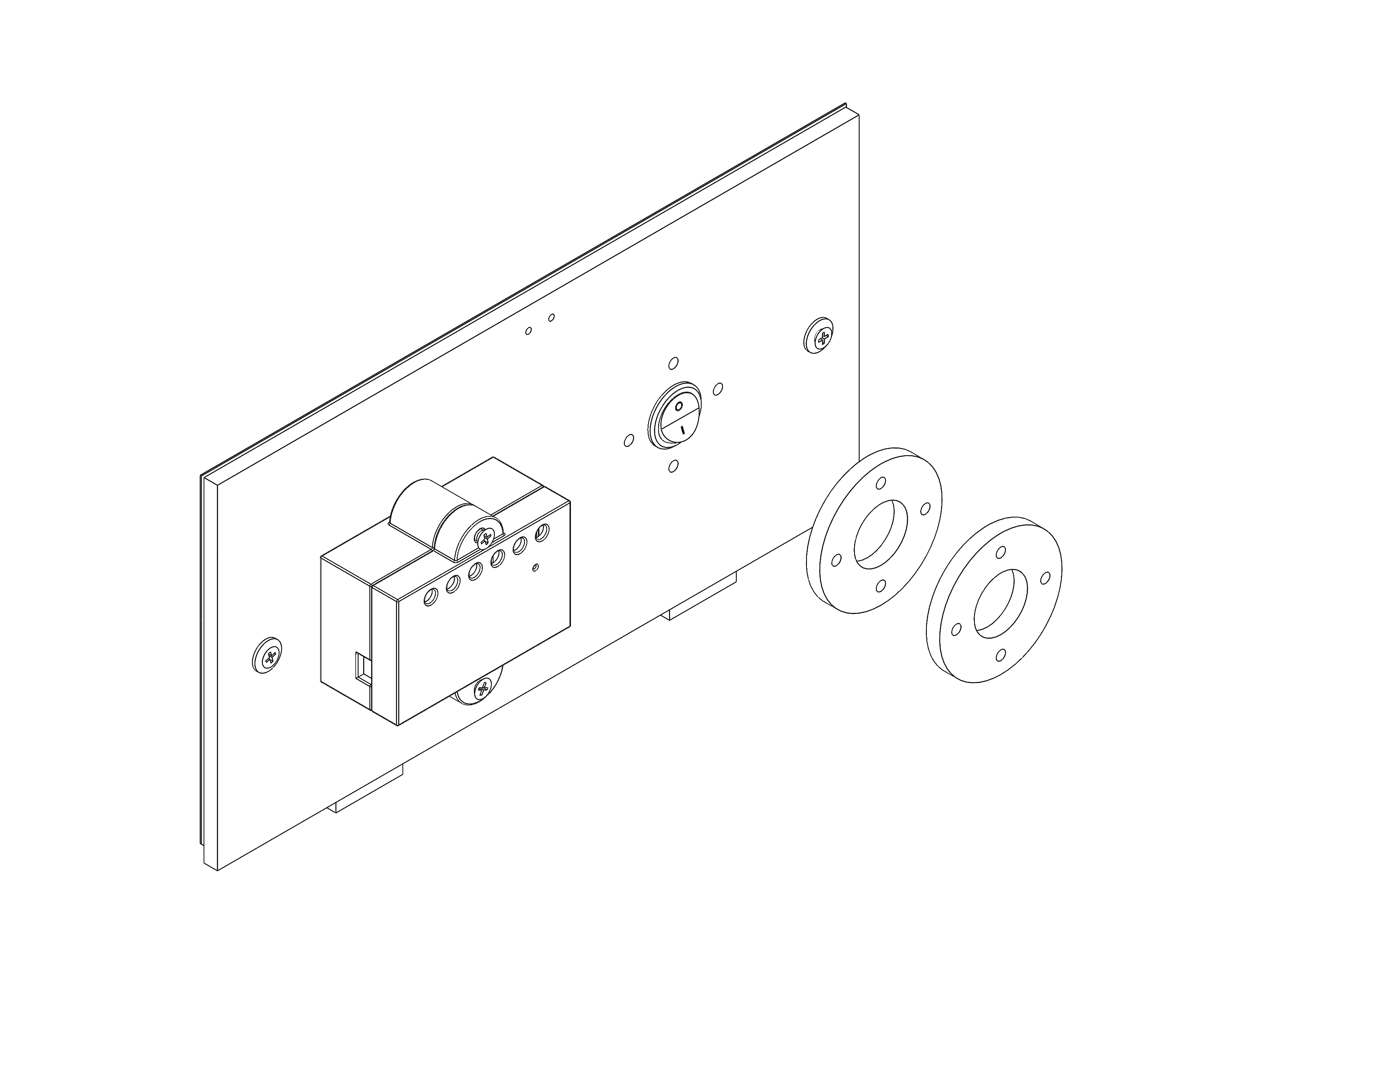
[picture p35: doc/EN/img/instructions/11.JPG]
    
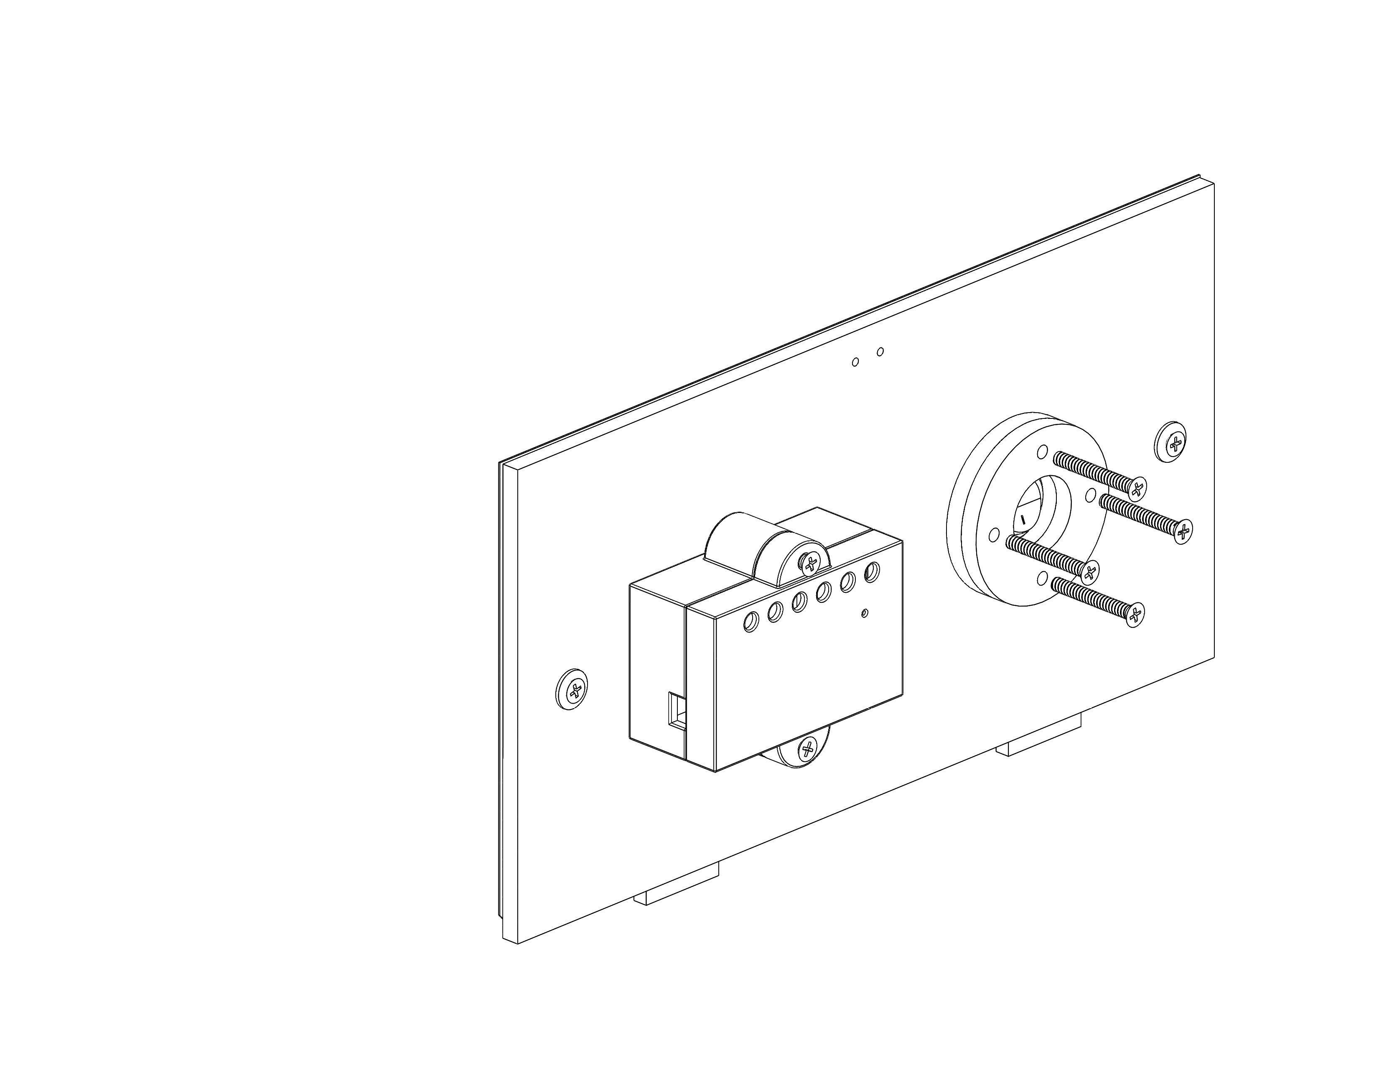
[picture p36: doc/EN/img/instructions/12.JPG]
  
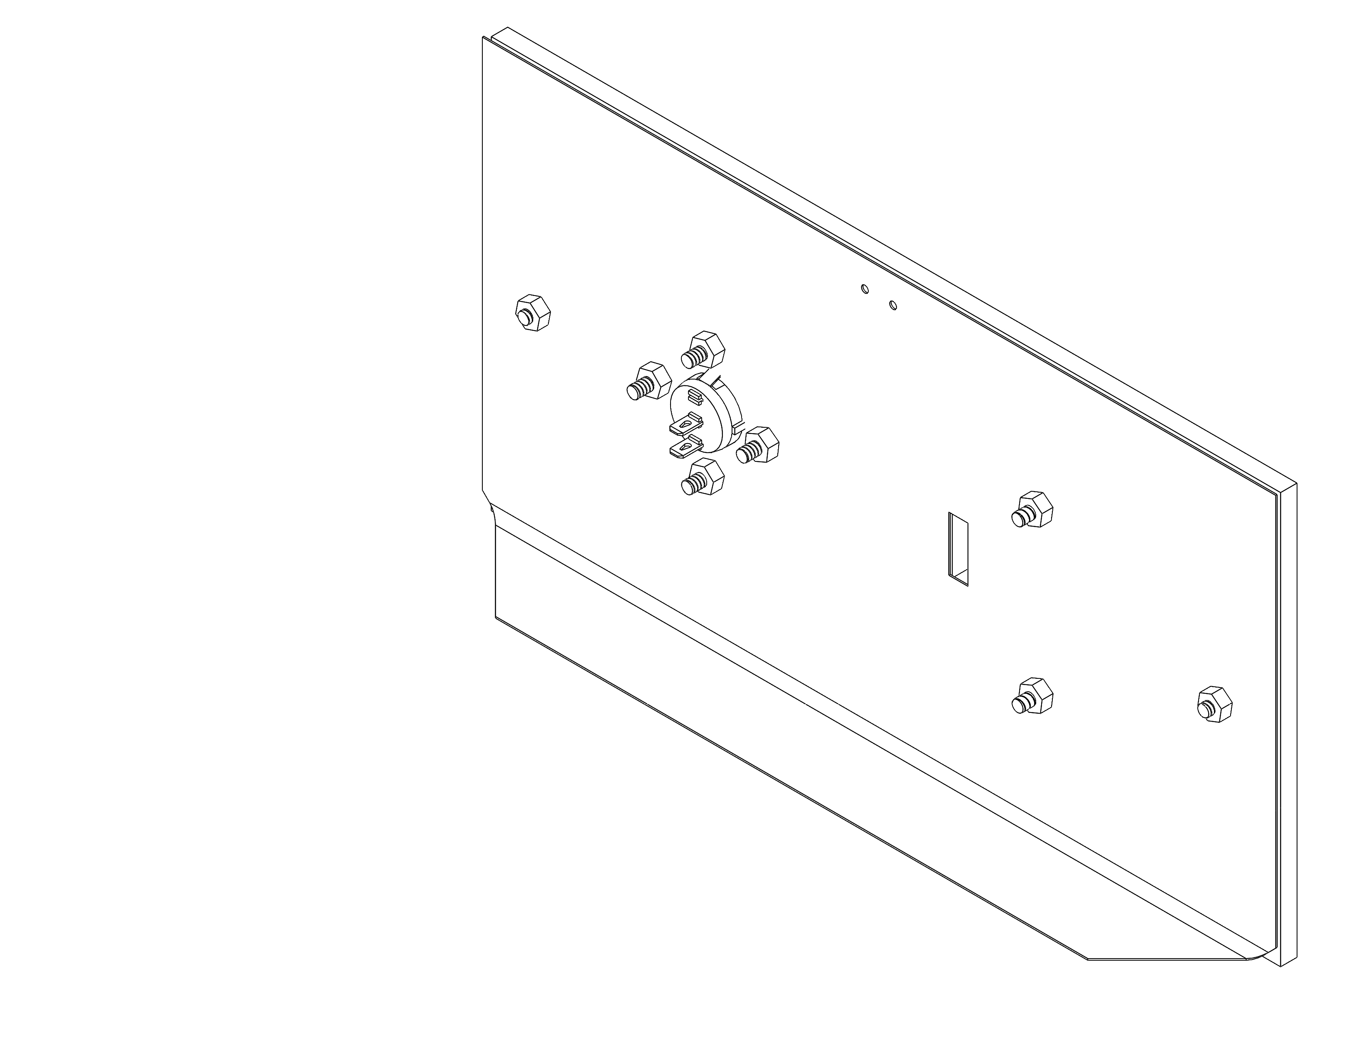
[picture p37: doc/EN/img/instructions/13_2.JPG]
   
</p>

### Make the other shorter side wall (plain) subassembly
<p float="left">
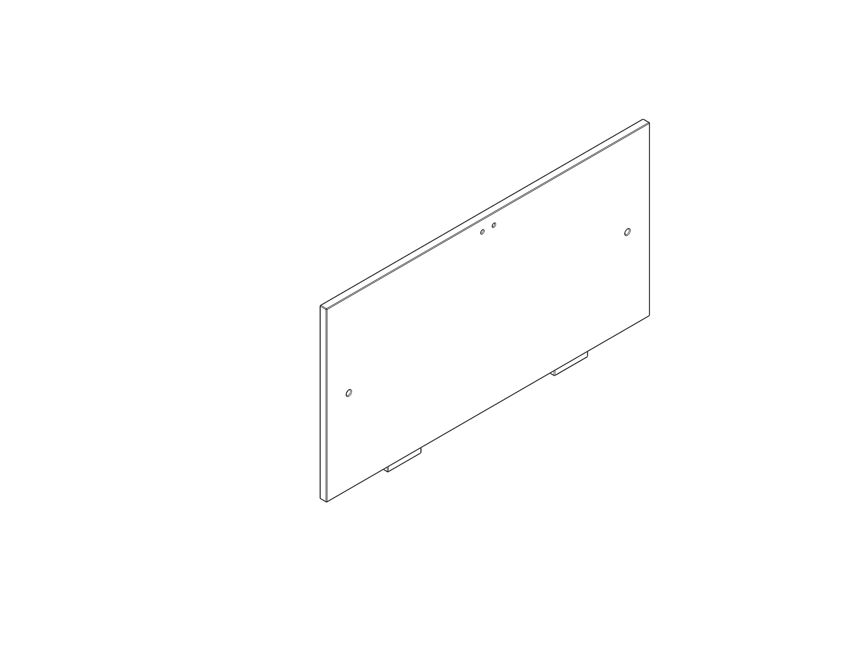
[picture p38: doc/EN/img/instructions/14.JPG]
    
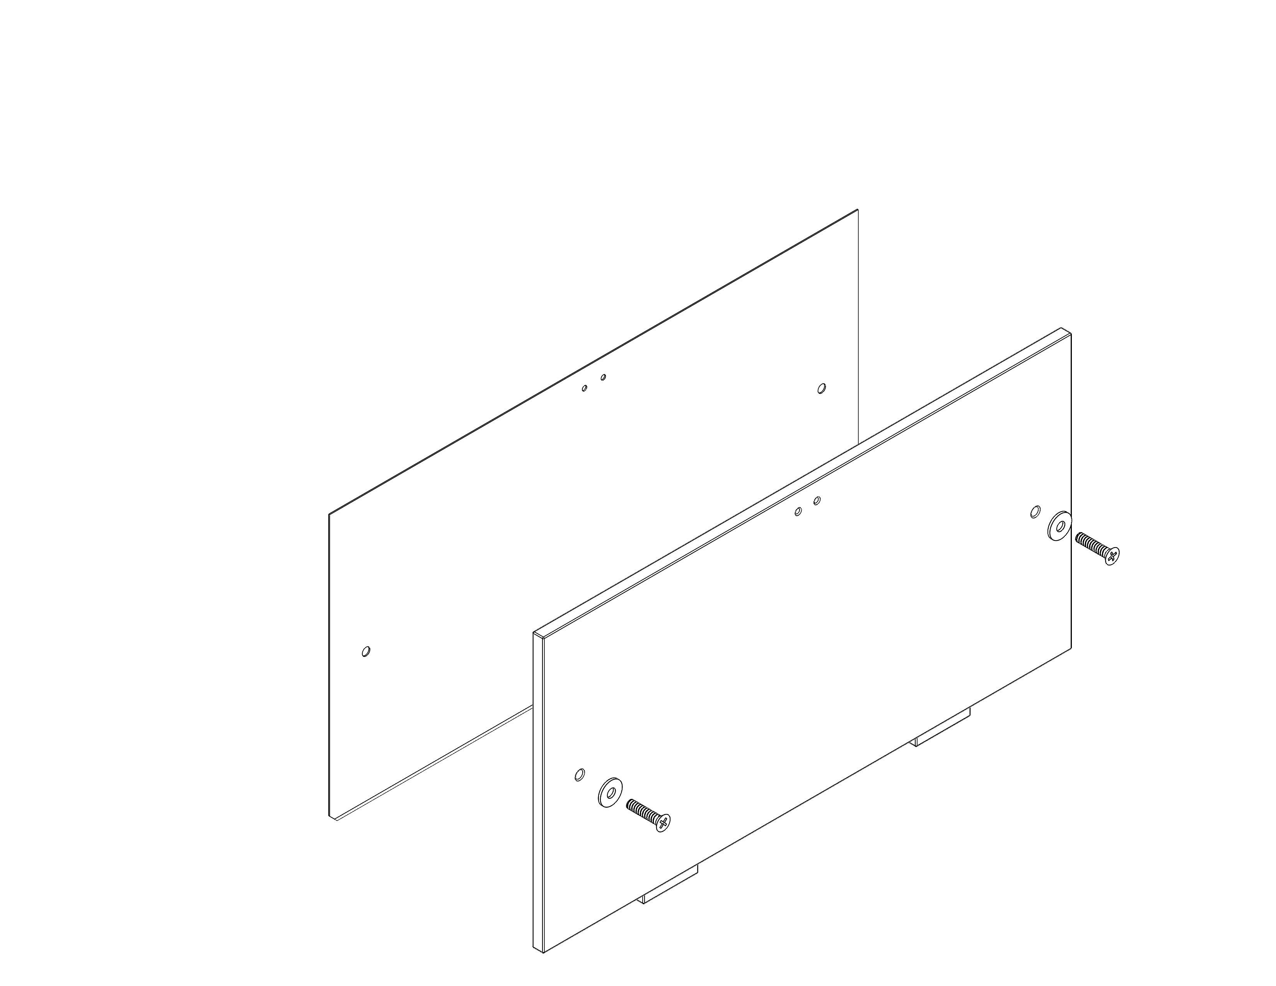
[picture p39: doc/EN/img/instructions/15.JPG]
  
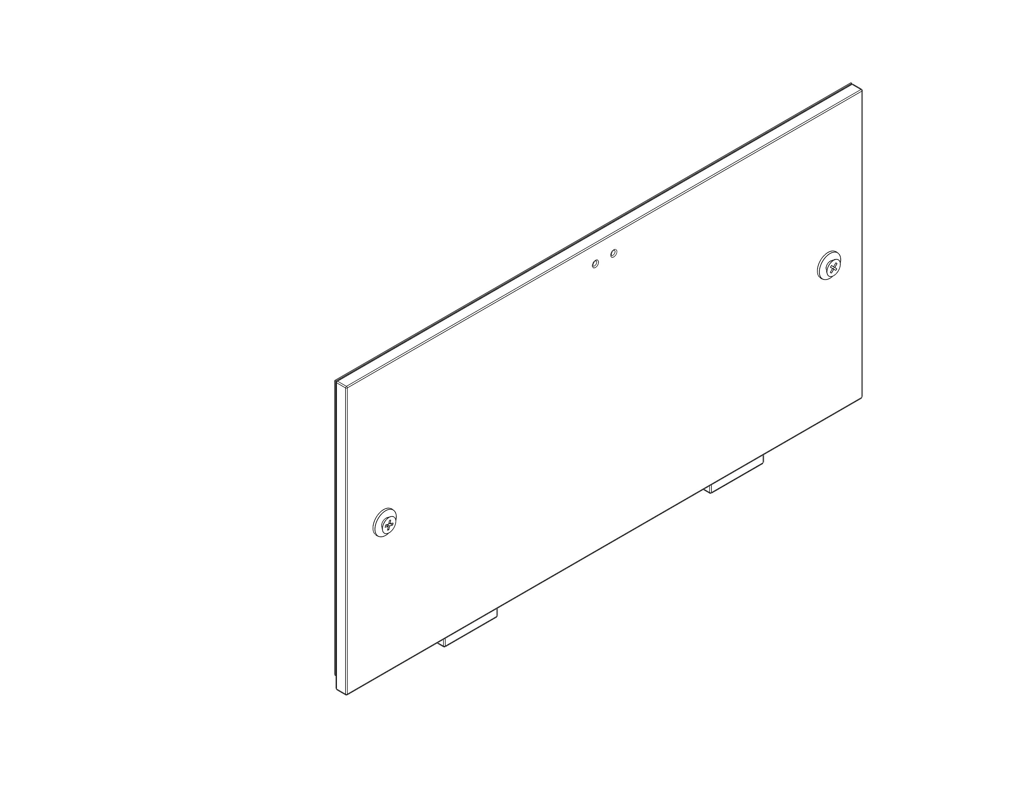
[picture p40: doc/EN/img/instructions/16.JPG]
   
</p>

### Make the longer wall subassembly
<p float="left">
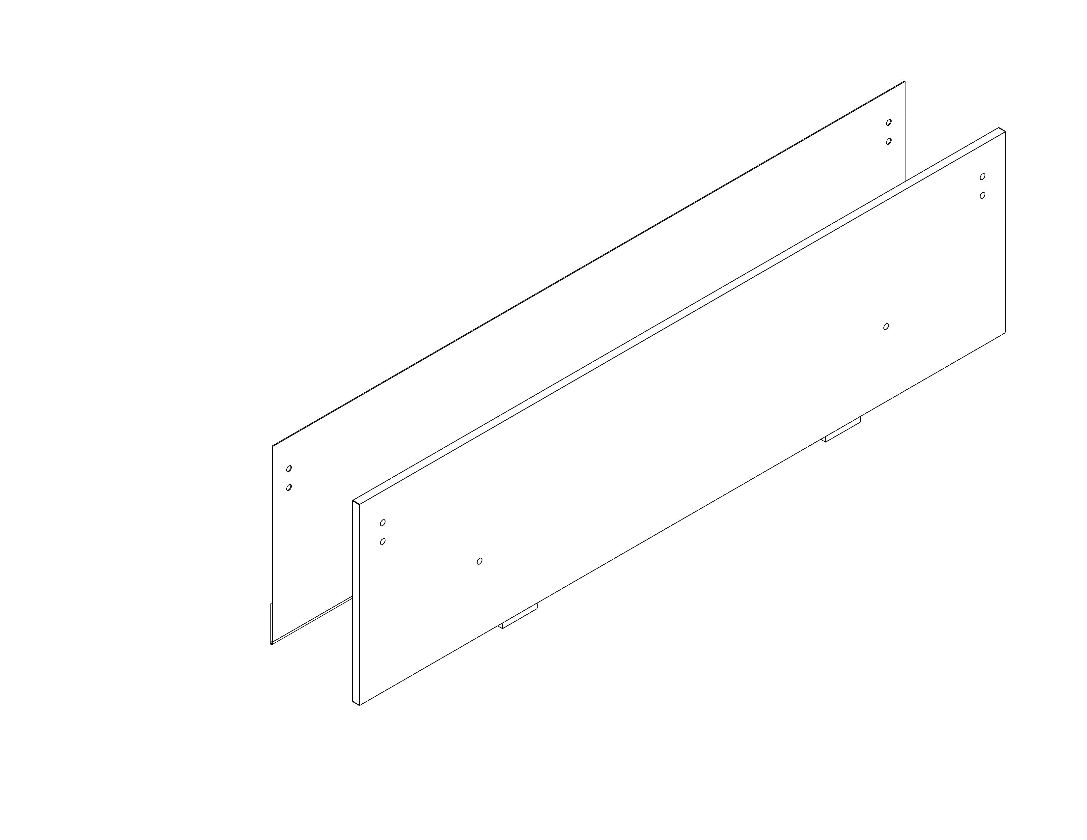
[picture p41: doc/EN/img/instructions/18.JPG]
    
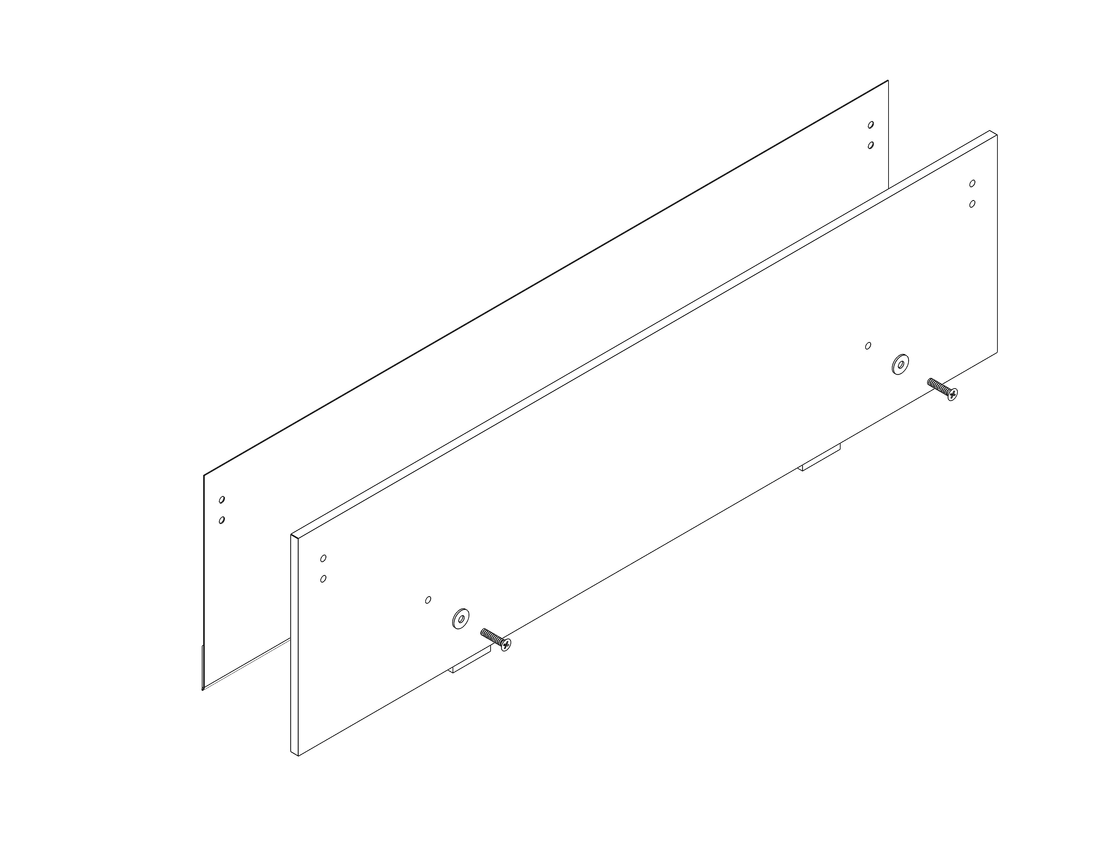
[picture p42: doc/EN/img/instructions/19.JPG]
  
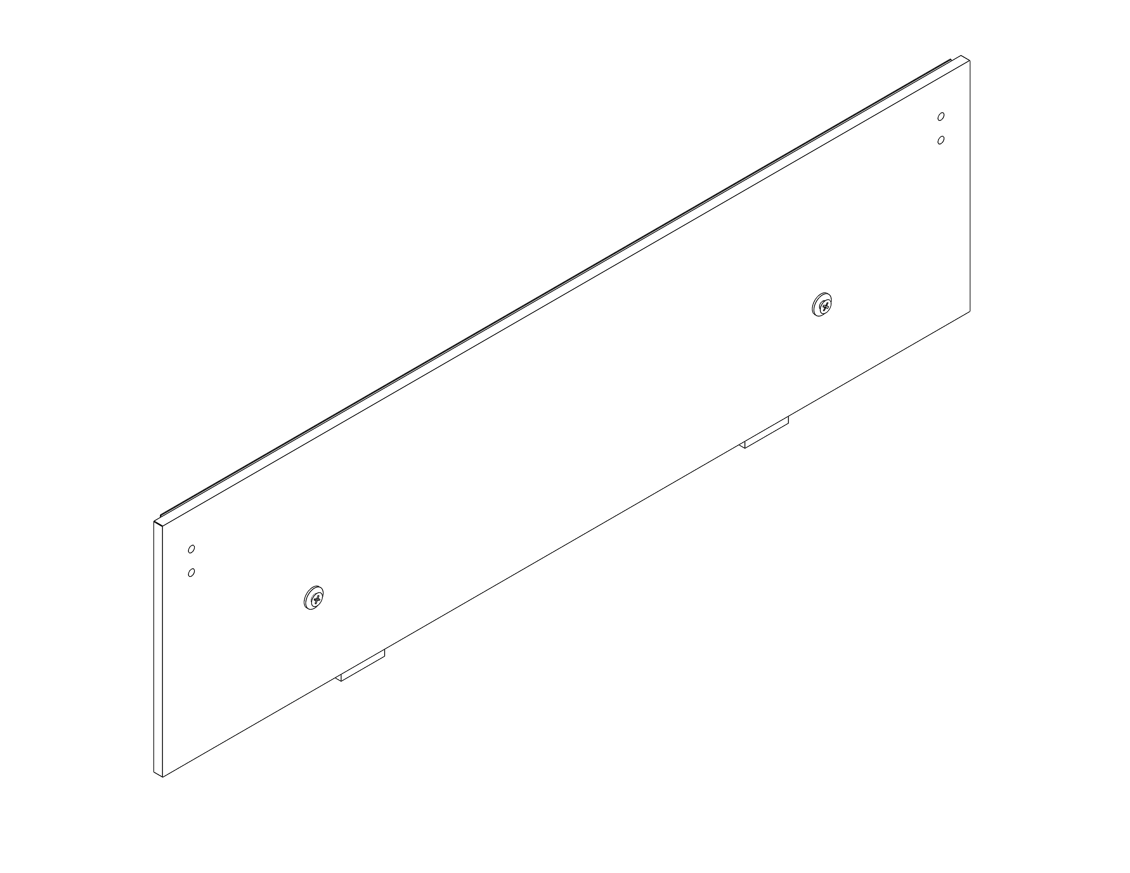
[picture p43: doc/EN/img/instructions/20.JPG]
   
</p>

### Insert grill supports 
<p float="left">
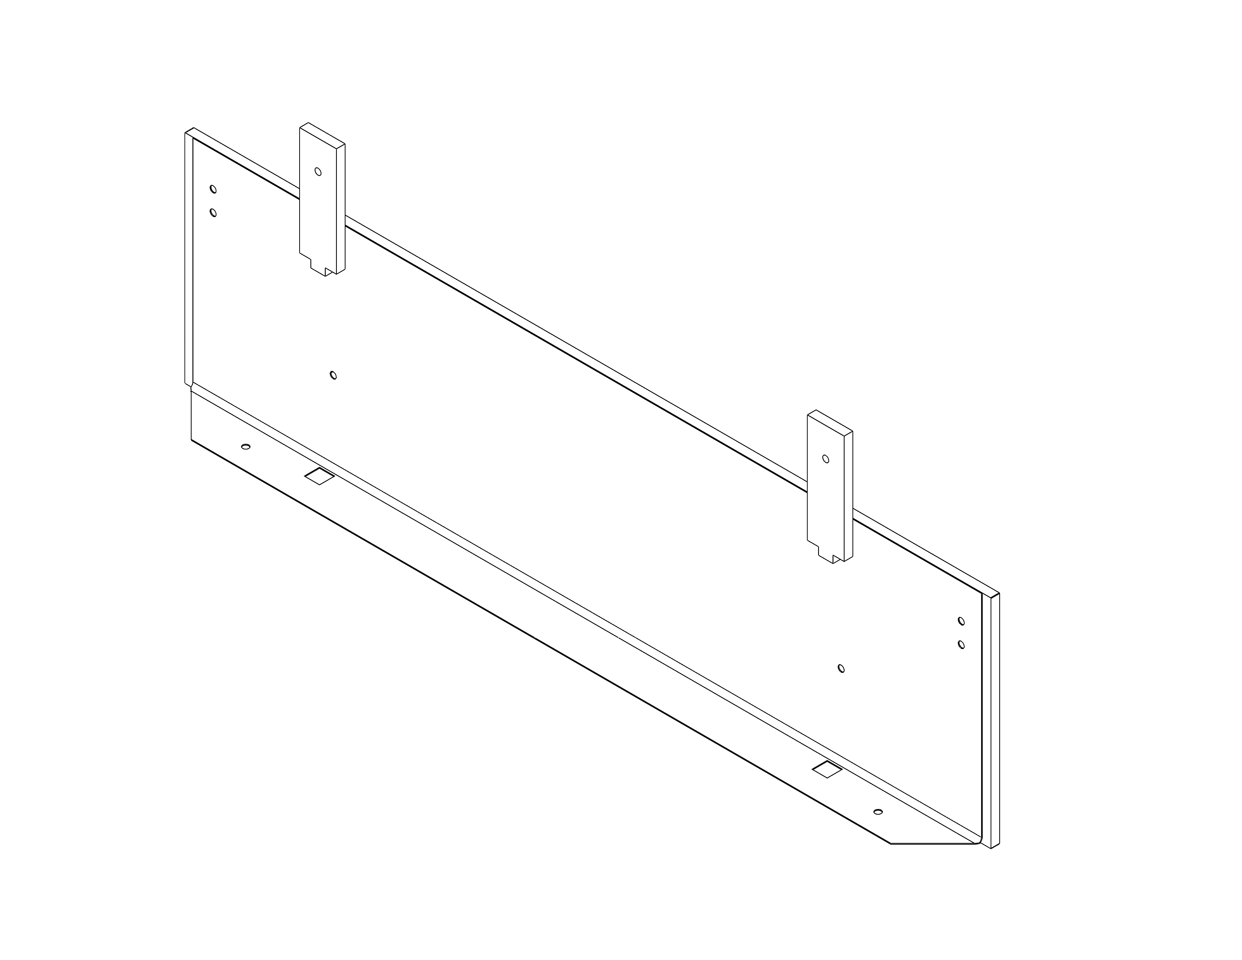
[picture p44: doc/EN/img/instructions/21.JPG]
    
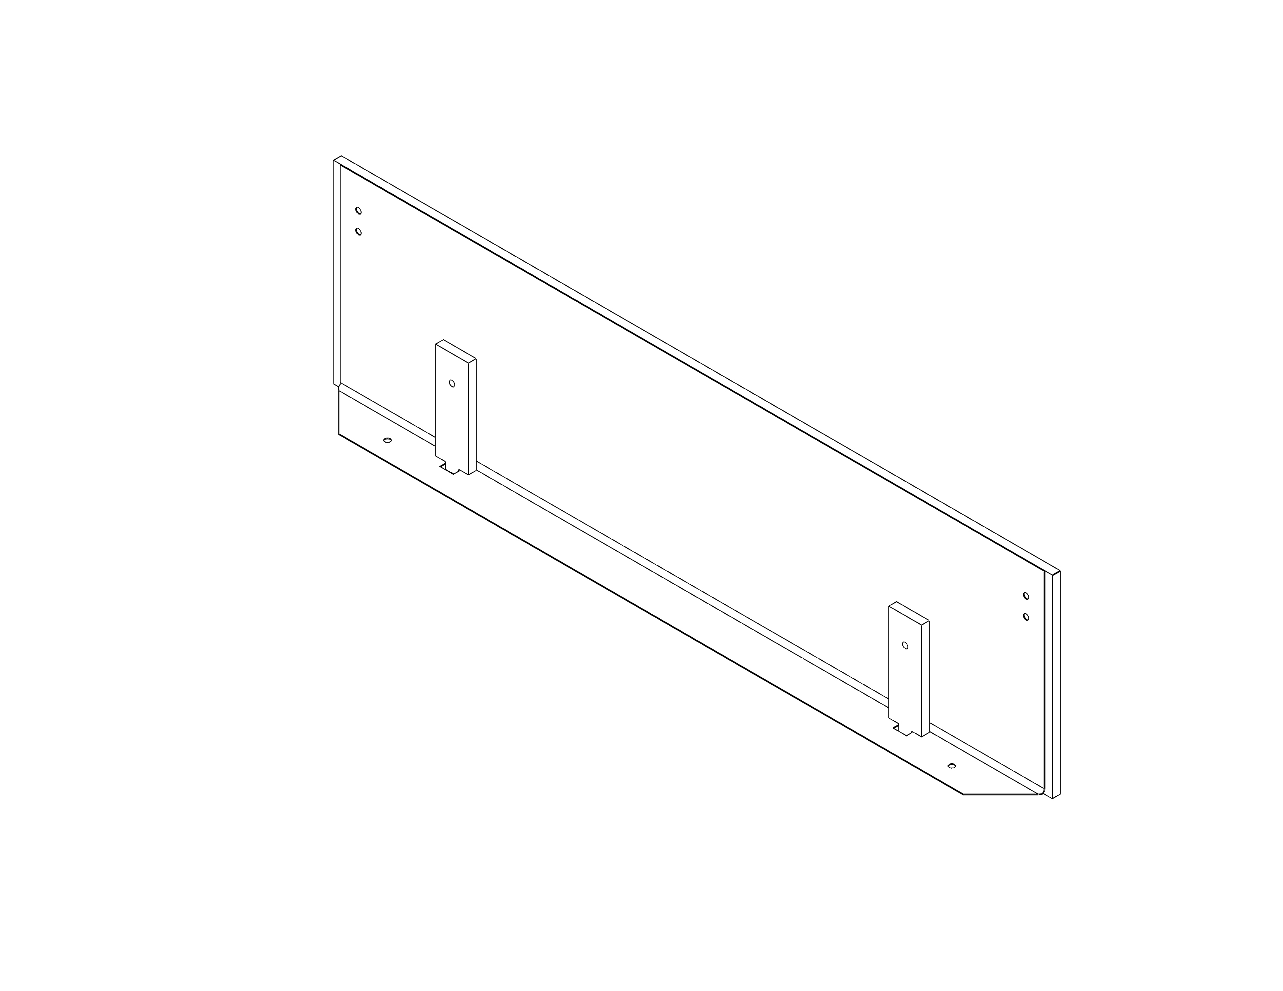
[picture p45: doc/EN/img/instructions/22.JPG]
  
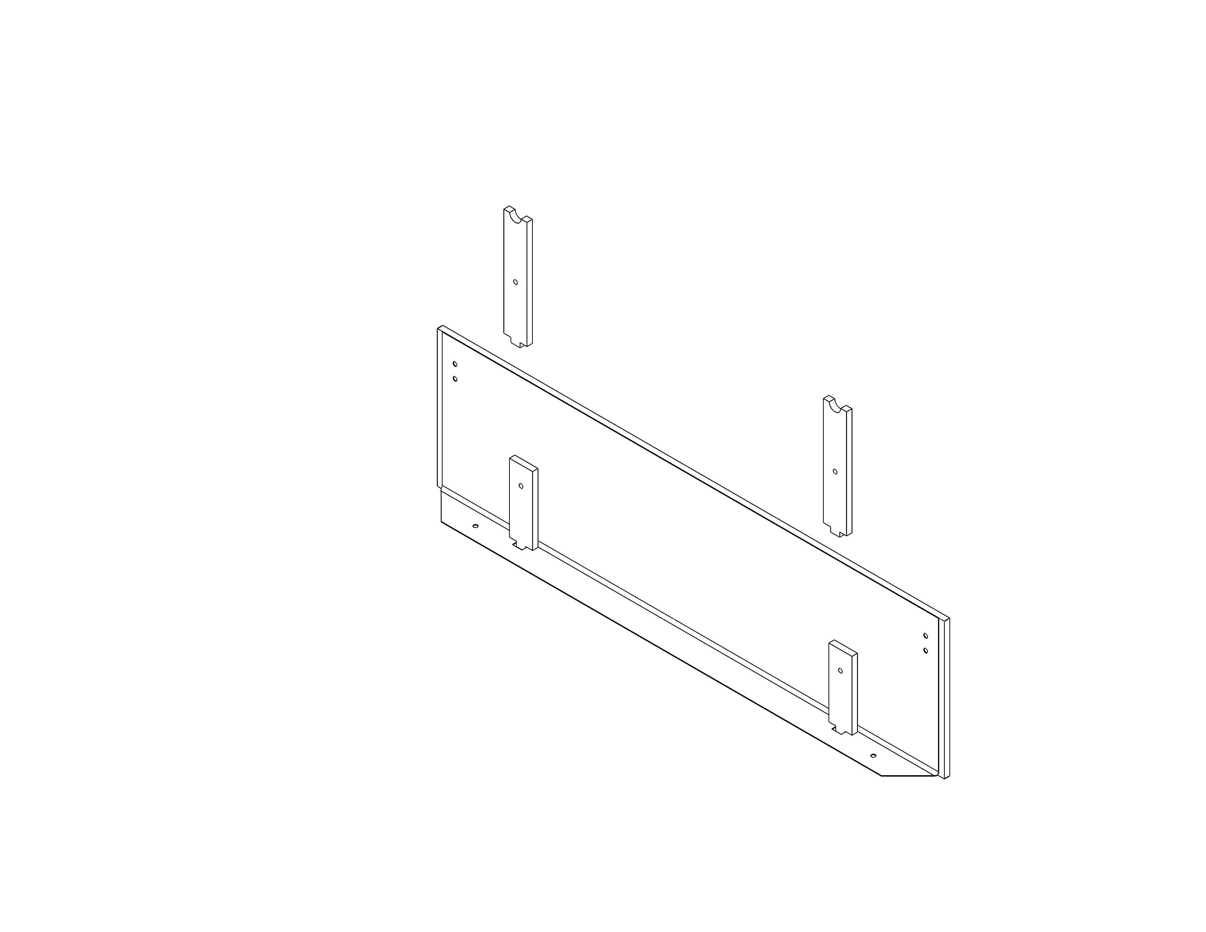
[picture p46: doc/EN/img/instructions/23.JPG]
   
</p>

### Fasten grill supports in place
<p float="left">
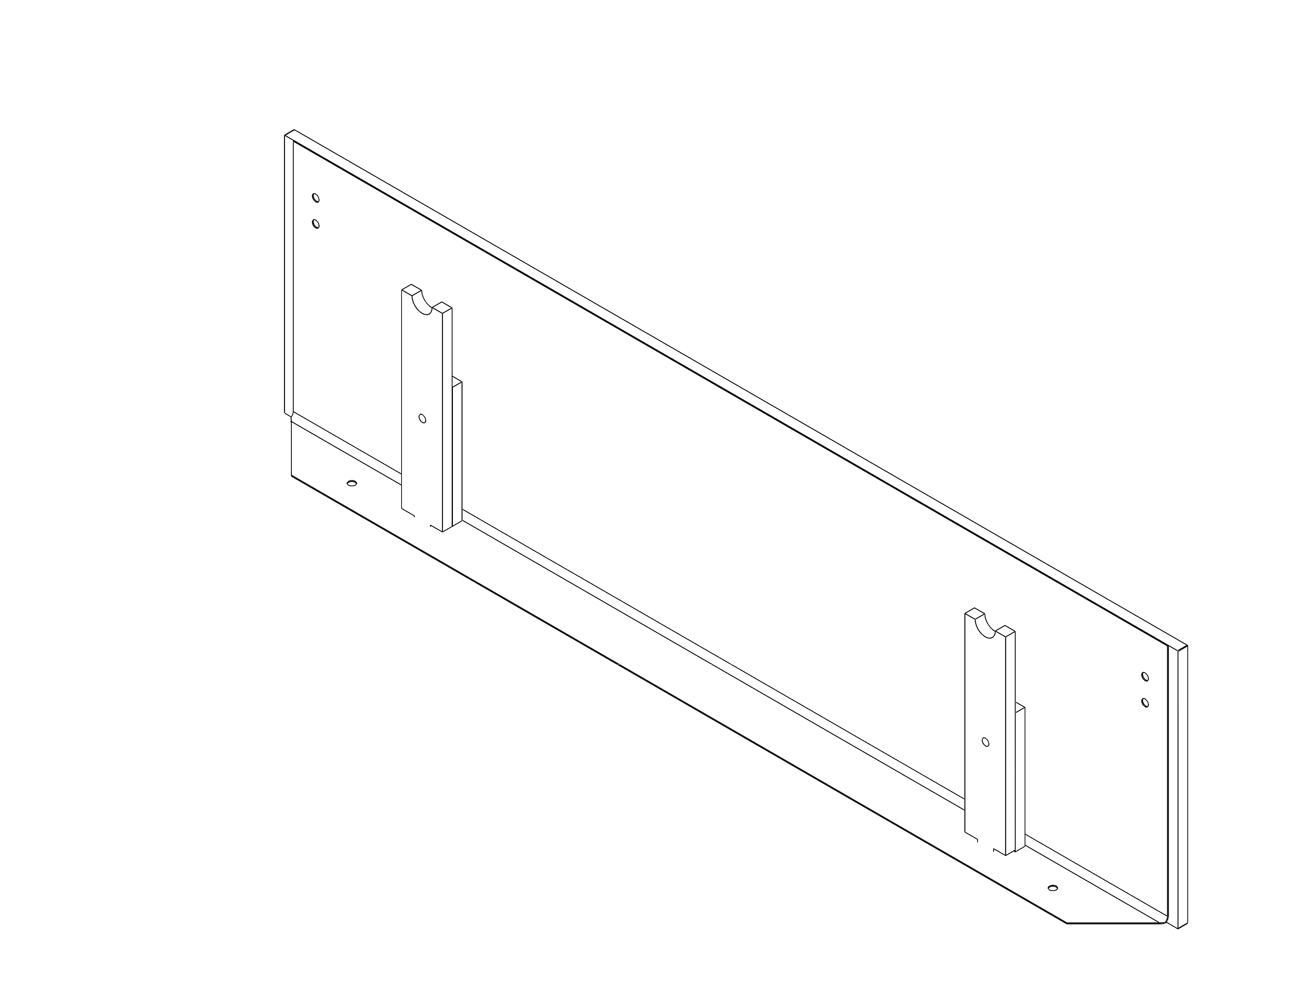
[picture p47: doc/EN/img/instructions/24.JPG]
    
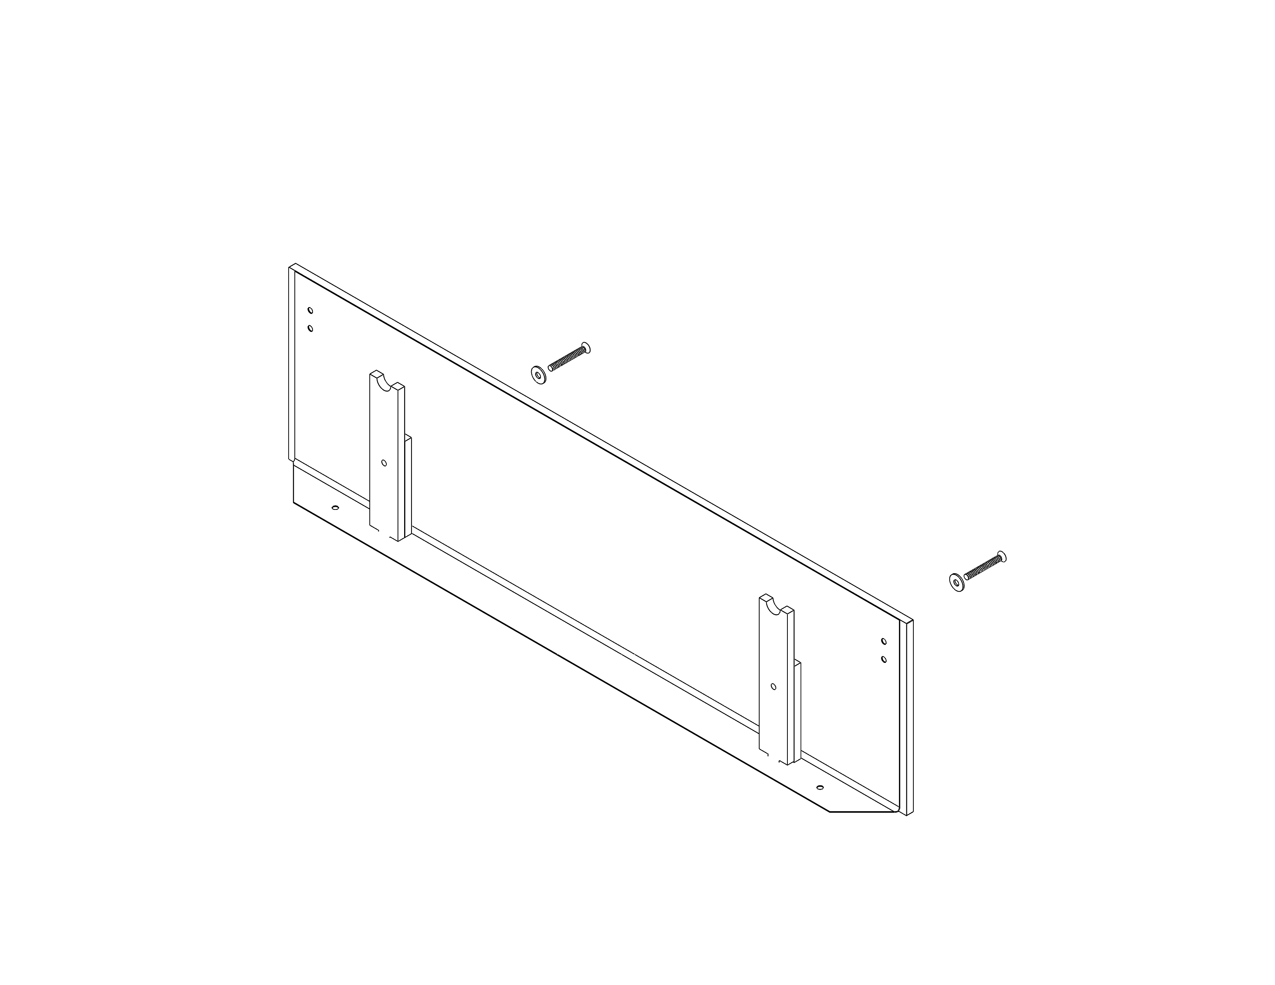
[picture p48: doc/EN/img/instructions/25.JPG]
  
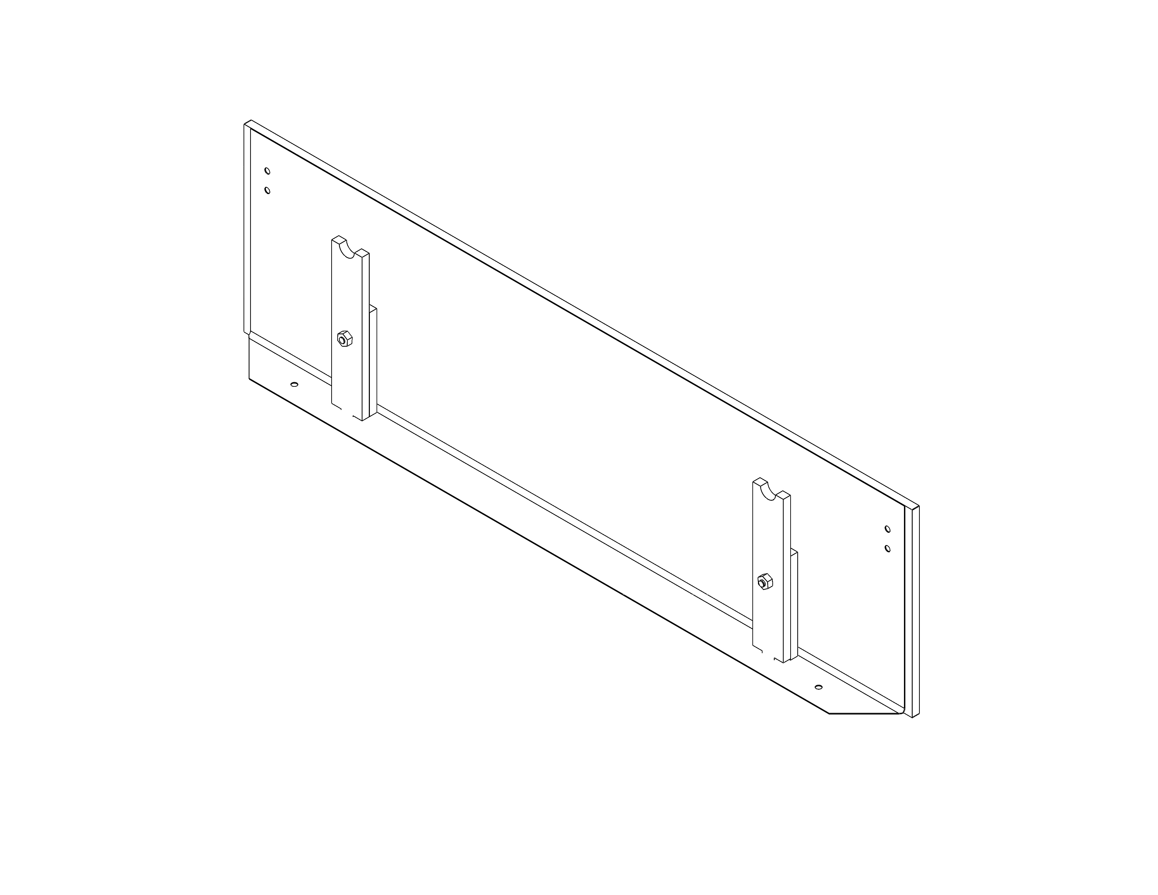
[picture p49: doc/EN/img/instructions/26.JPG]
   
</p>

### Assemble together the base and longer side subassemblies along the provides slots and tabs
<p float="left">
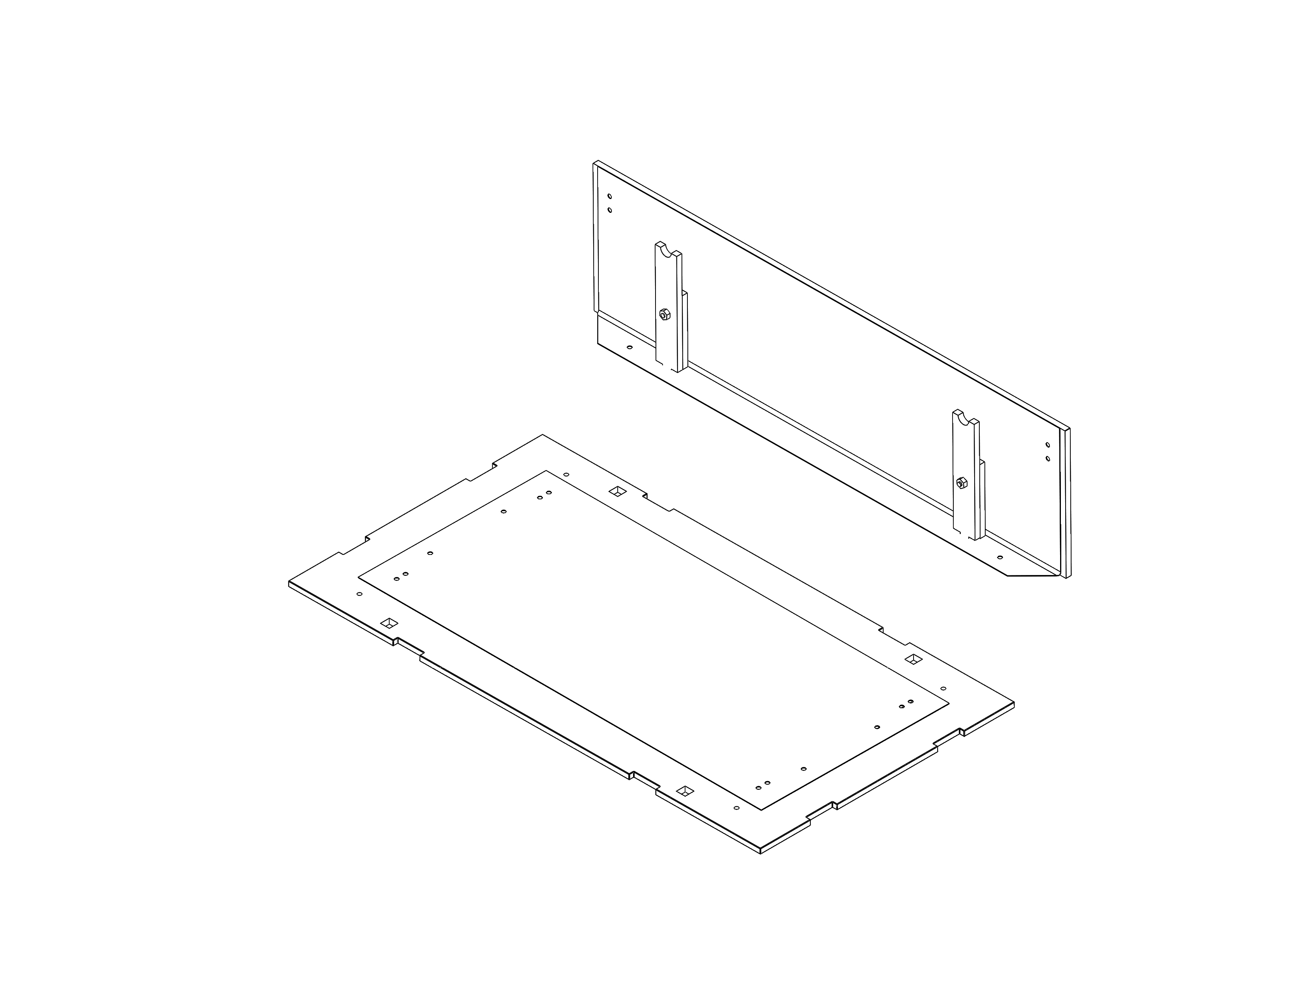
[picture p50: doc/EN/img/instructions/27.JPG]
    
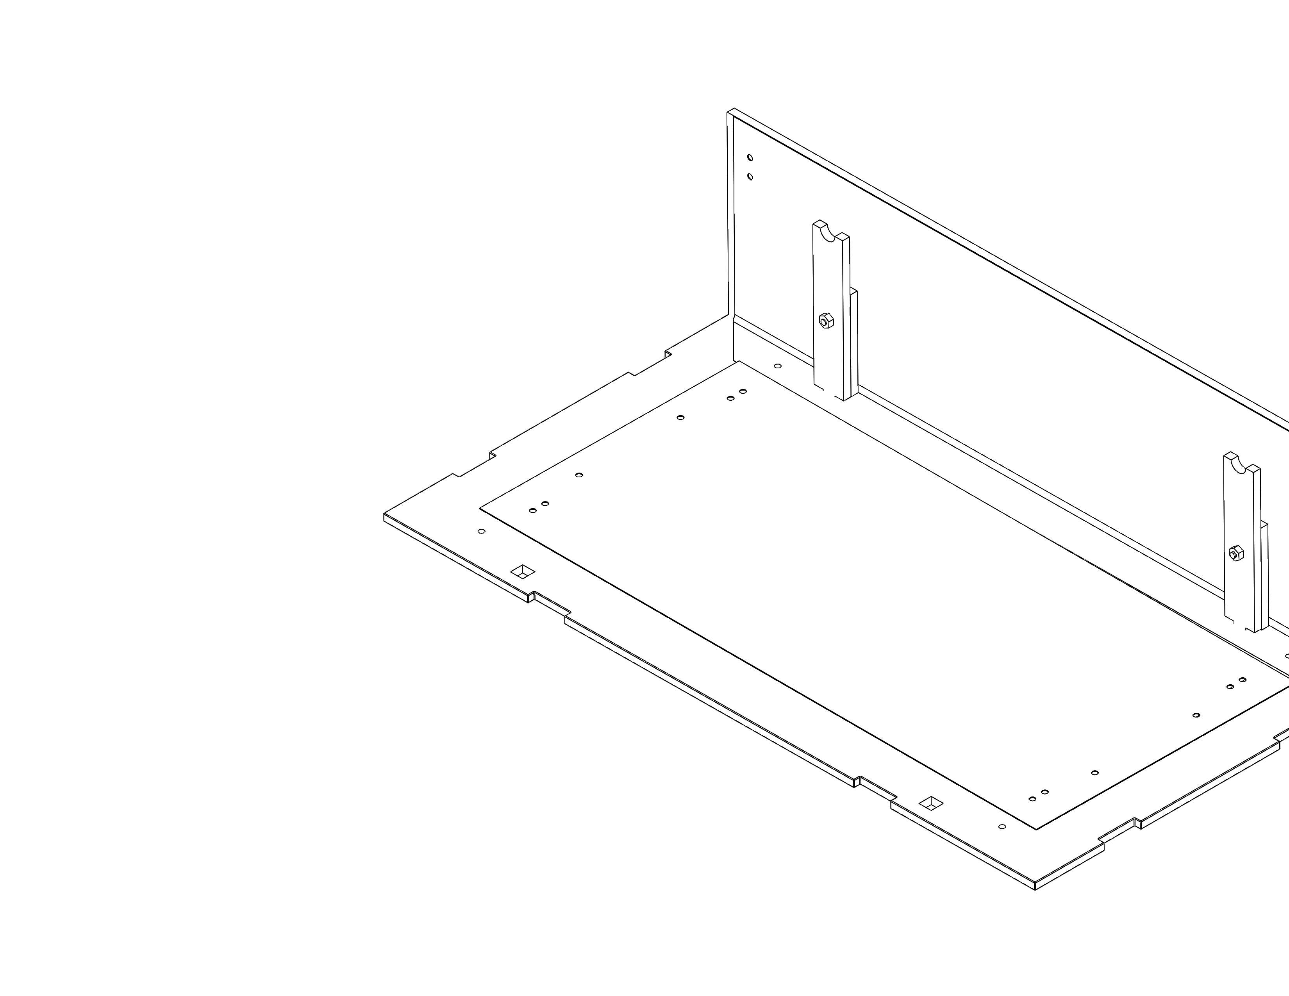
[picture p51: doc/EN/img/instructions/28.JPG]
  
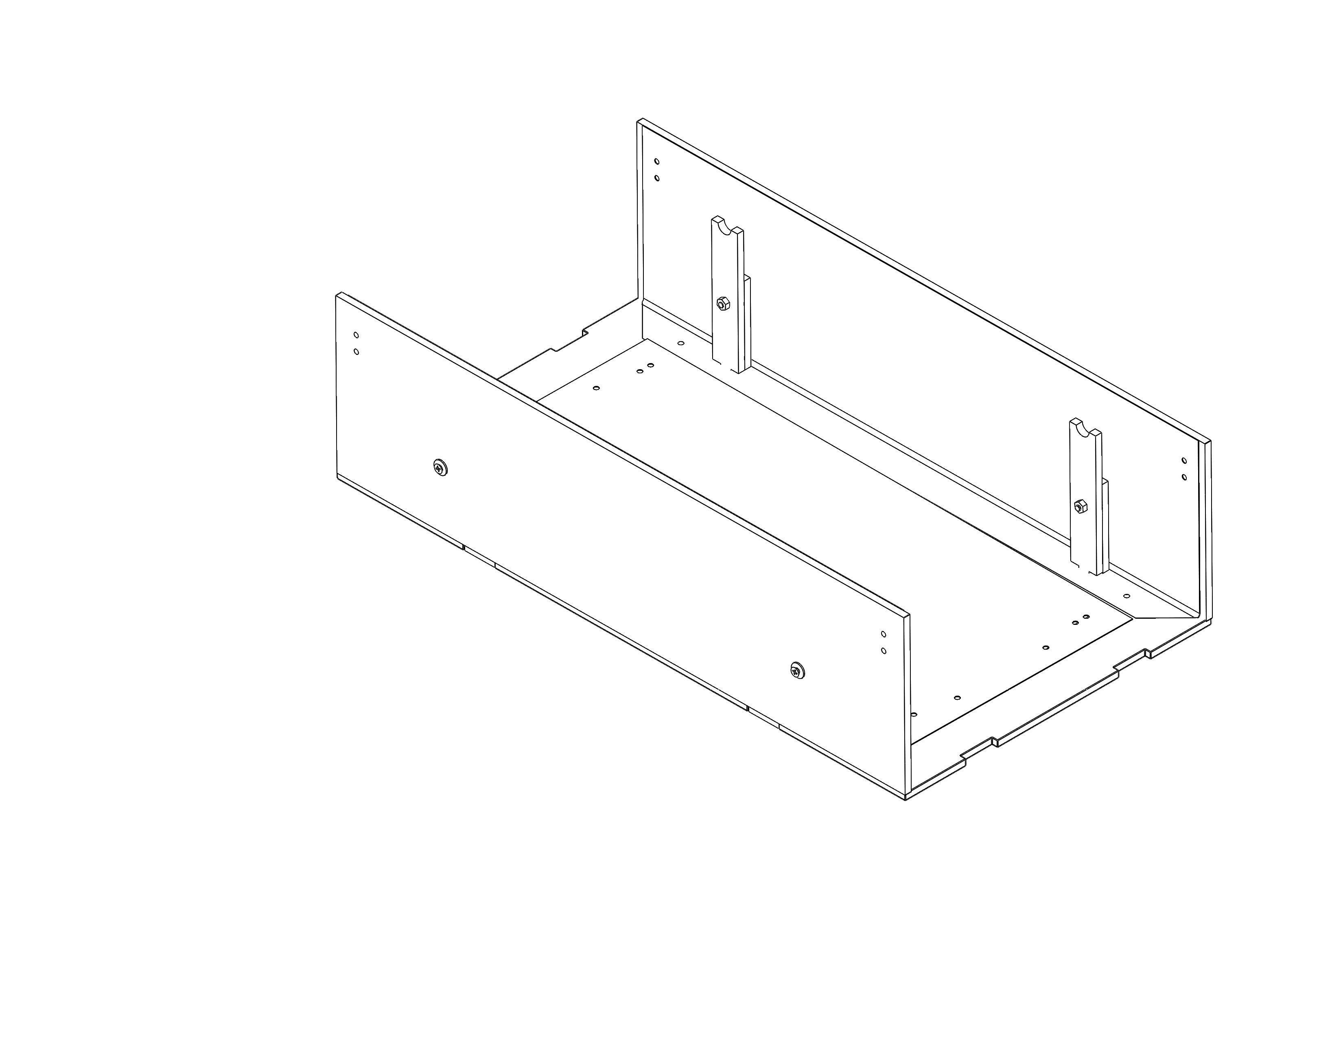
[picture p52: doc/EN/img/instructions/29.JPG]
   
</p>

### Assemble together the base and shorter sides along the provides slots and tabs
<p float="left">
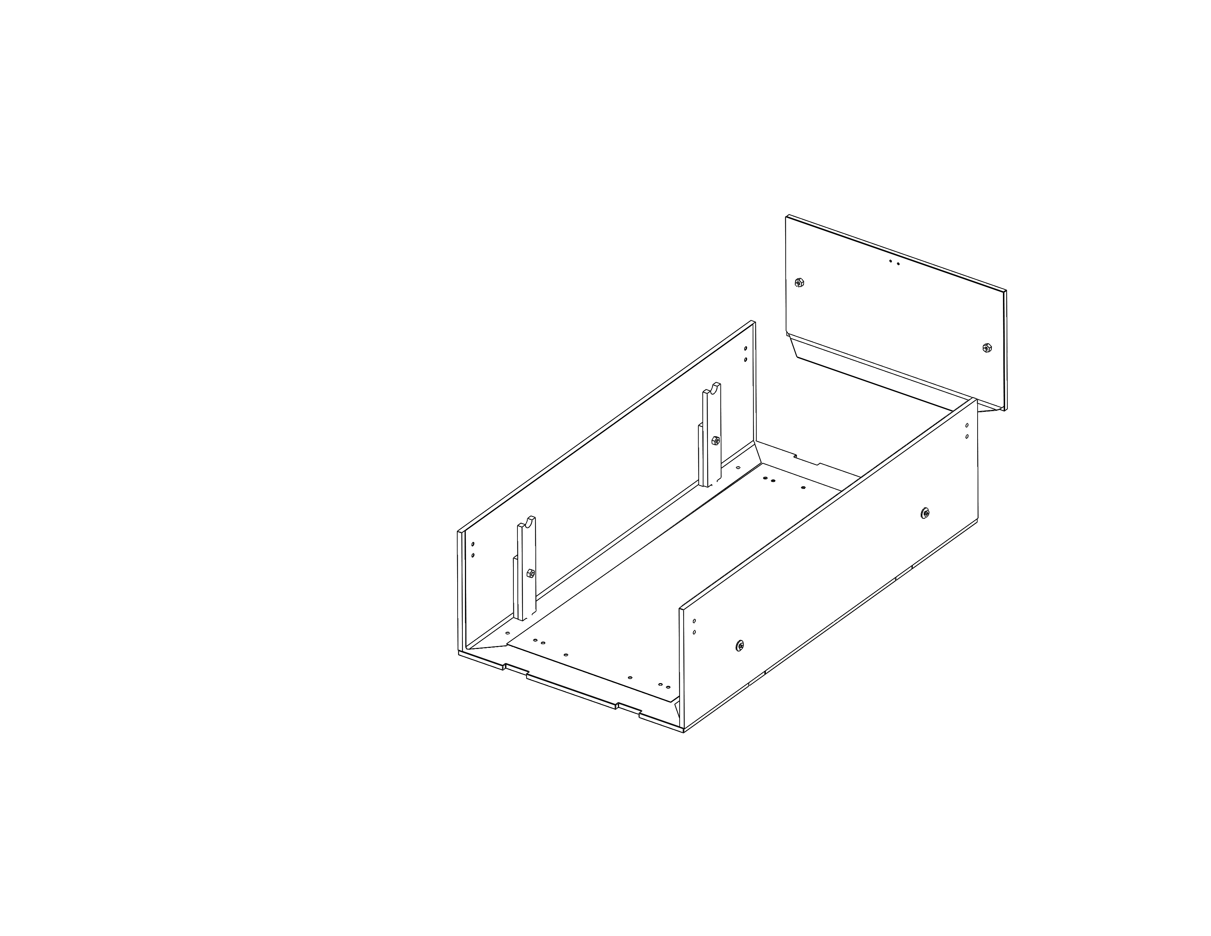
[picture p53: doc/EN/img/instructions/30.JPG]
    
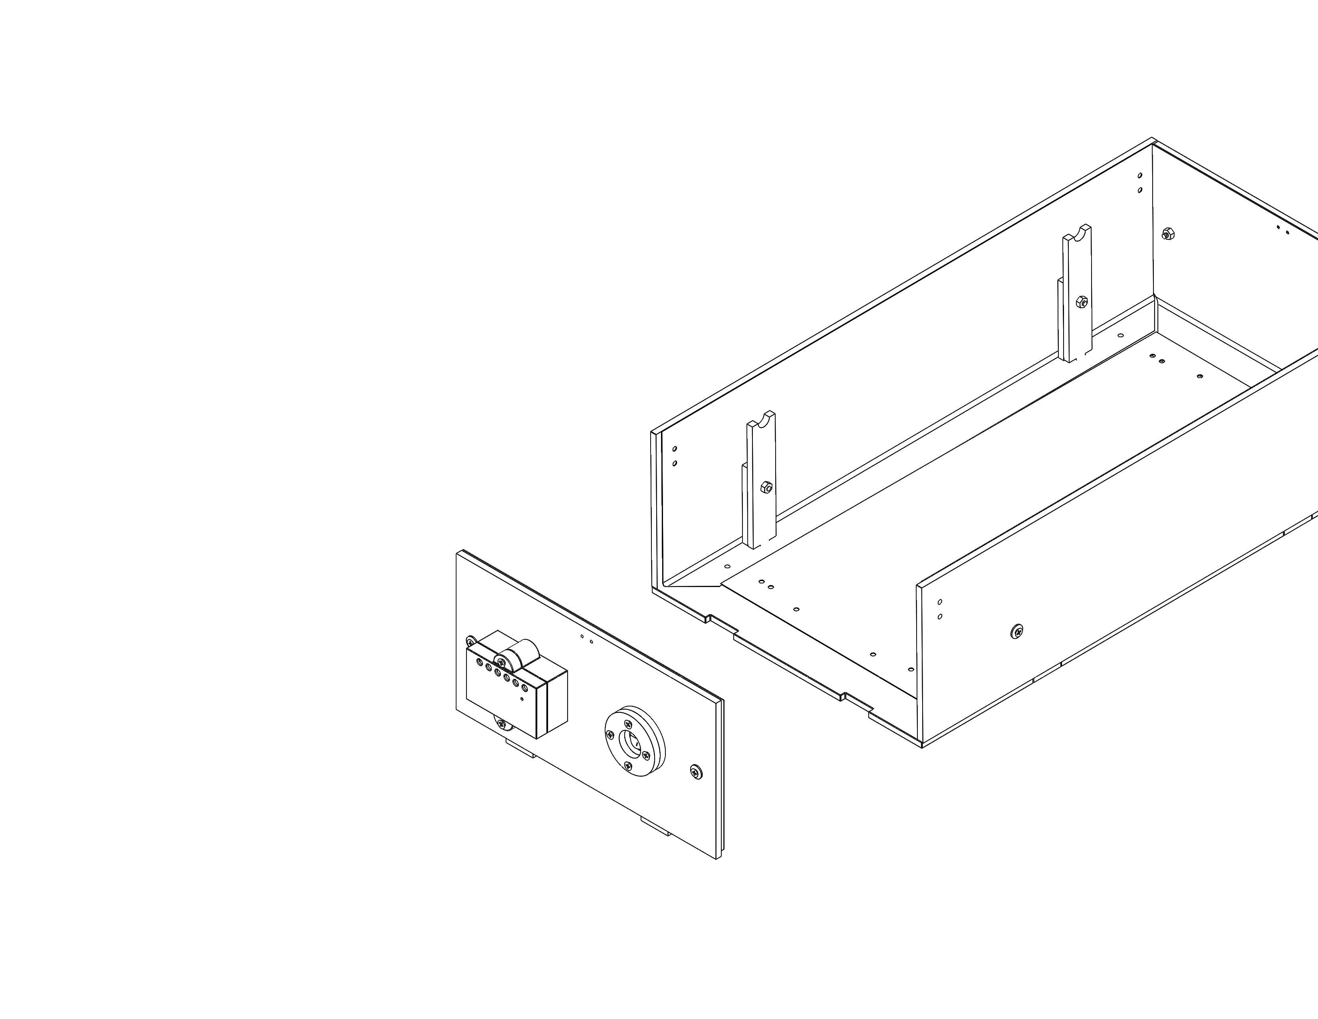
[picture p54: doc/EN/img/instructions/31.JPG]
  
</p>

### Place grill and mesh within the casing, onto the grill supports
<p float="left">
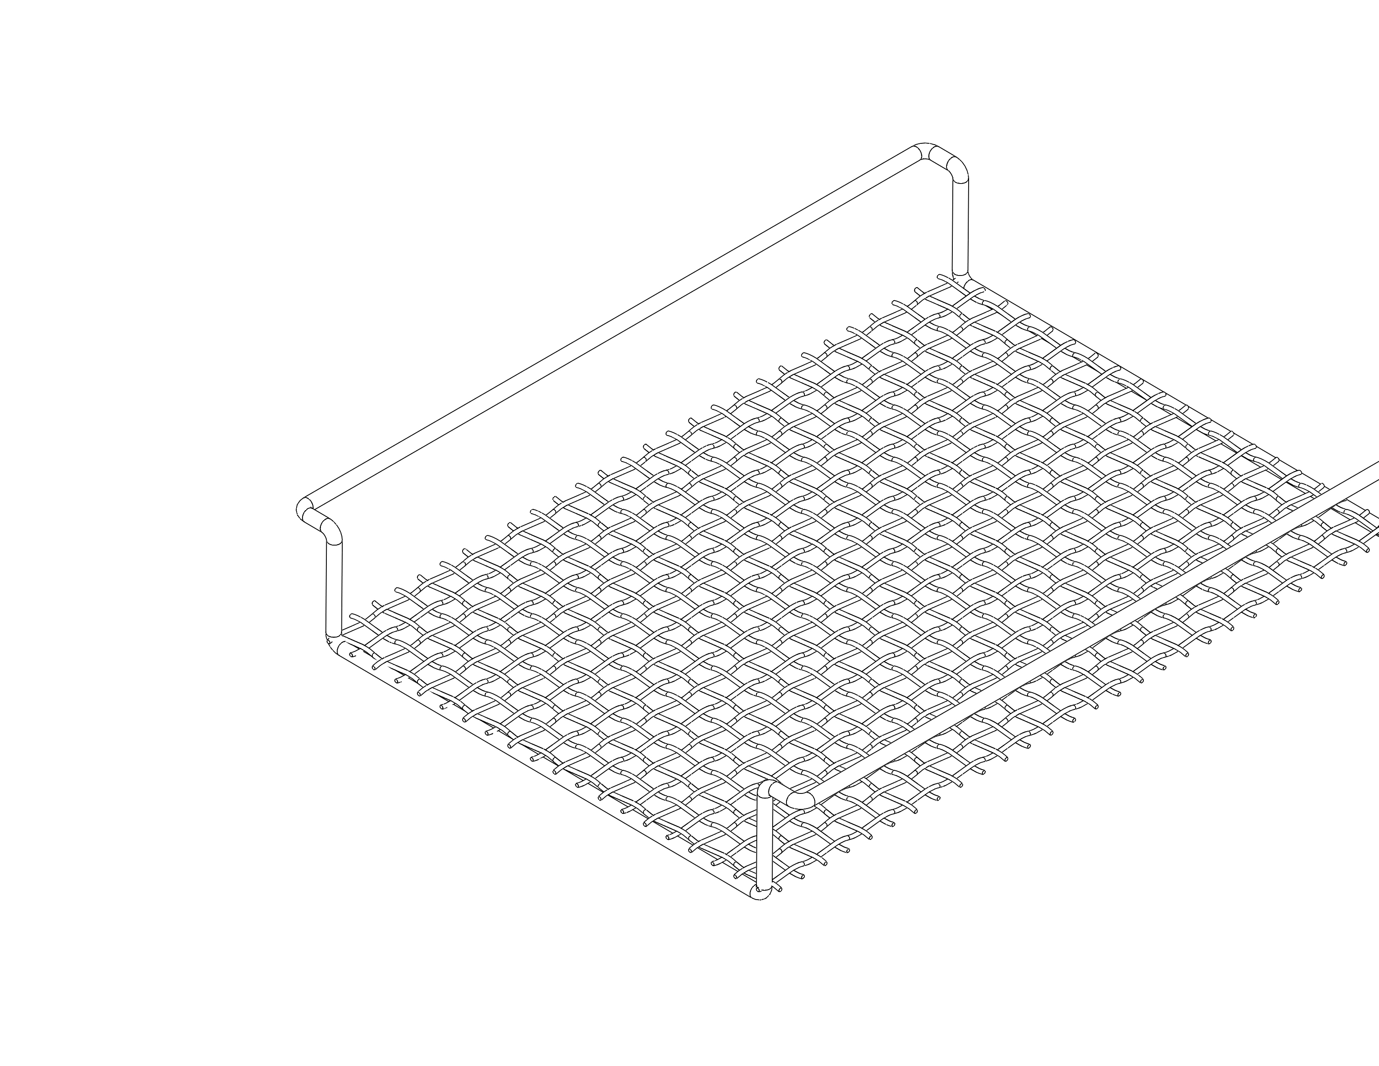
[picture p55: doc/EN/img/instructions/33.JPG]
    
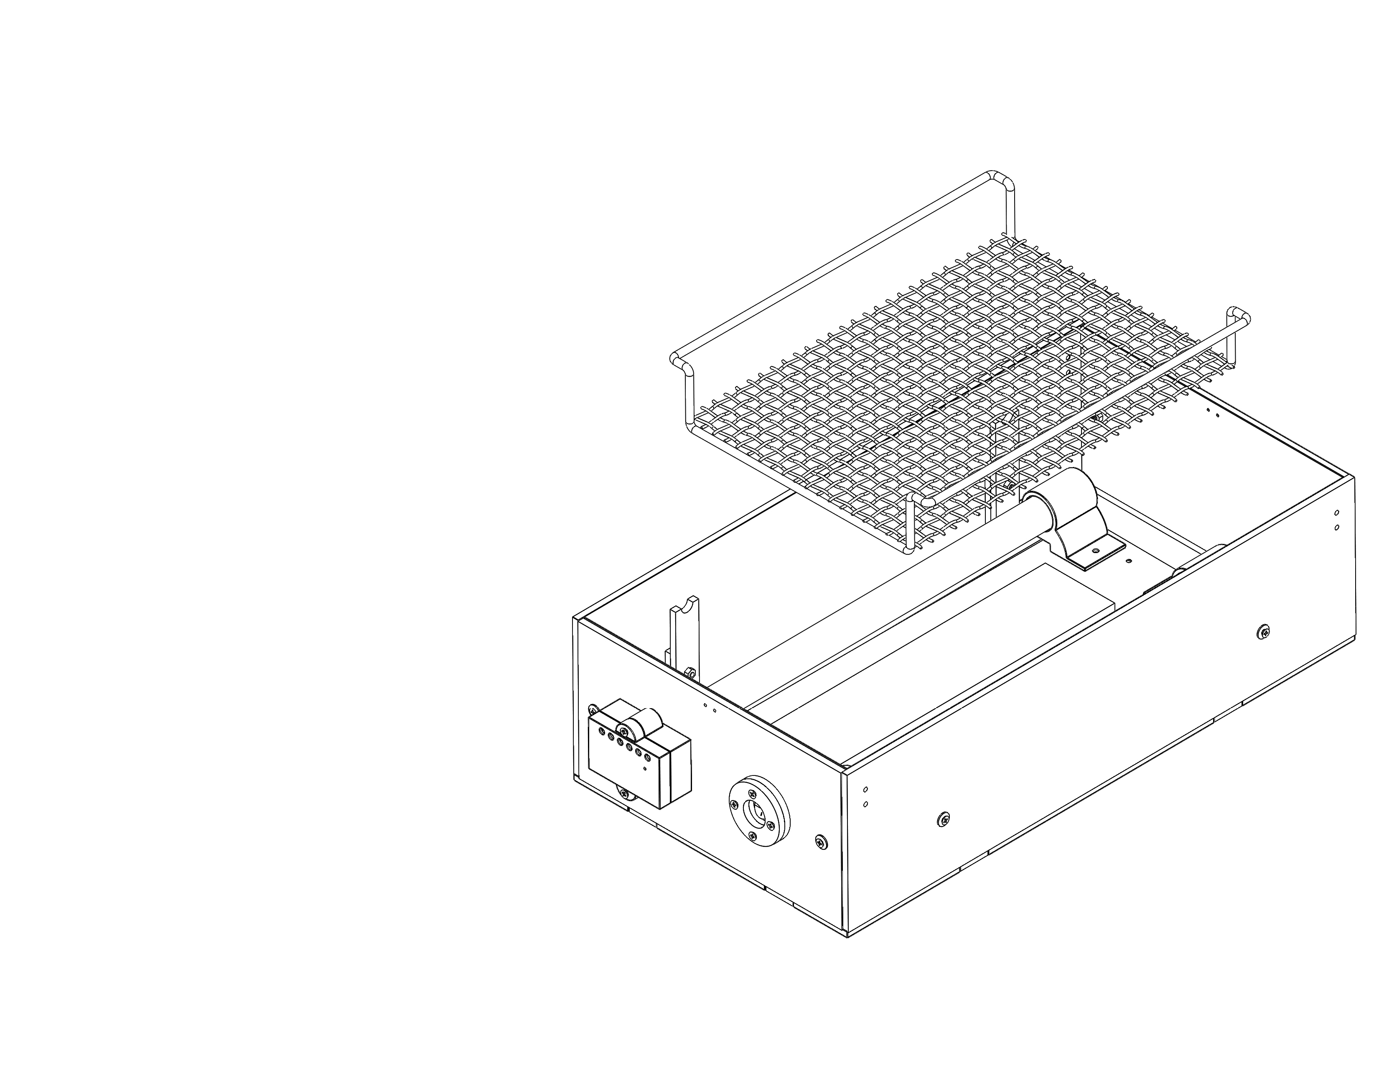
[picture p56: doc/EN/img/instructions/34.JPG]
  
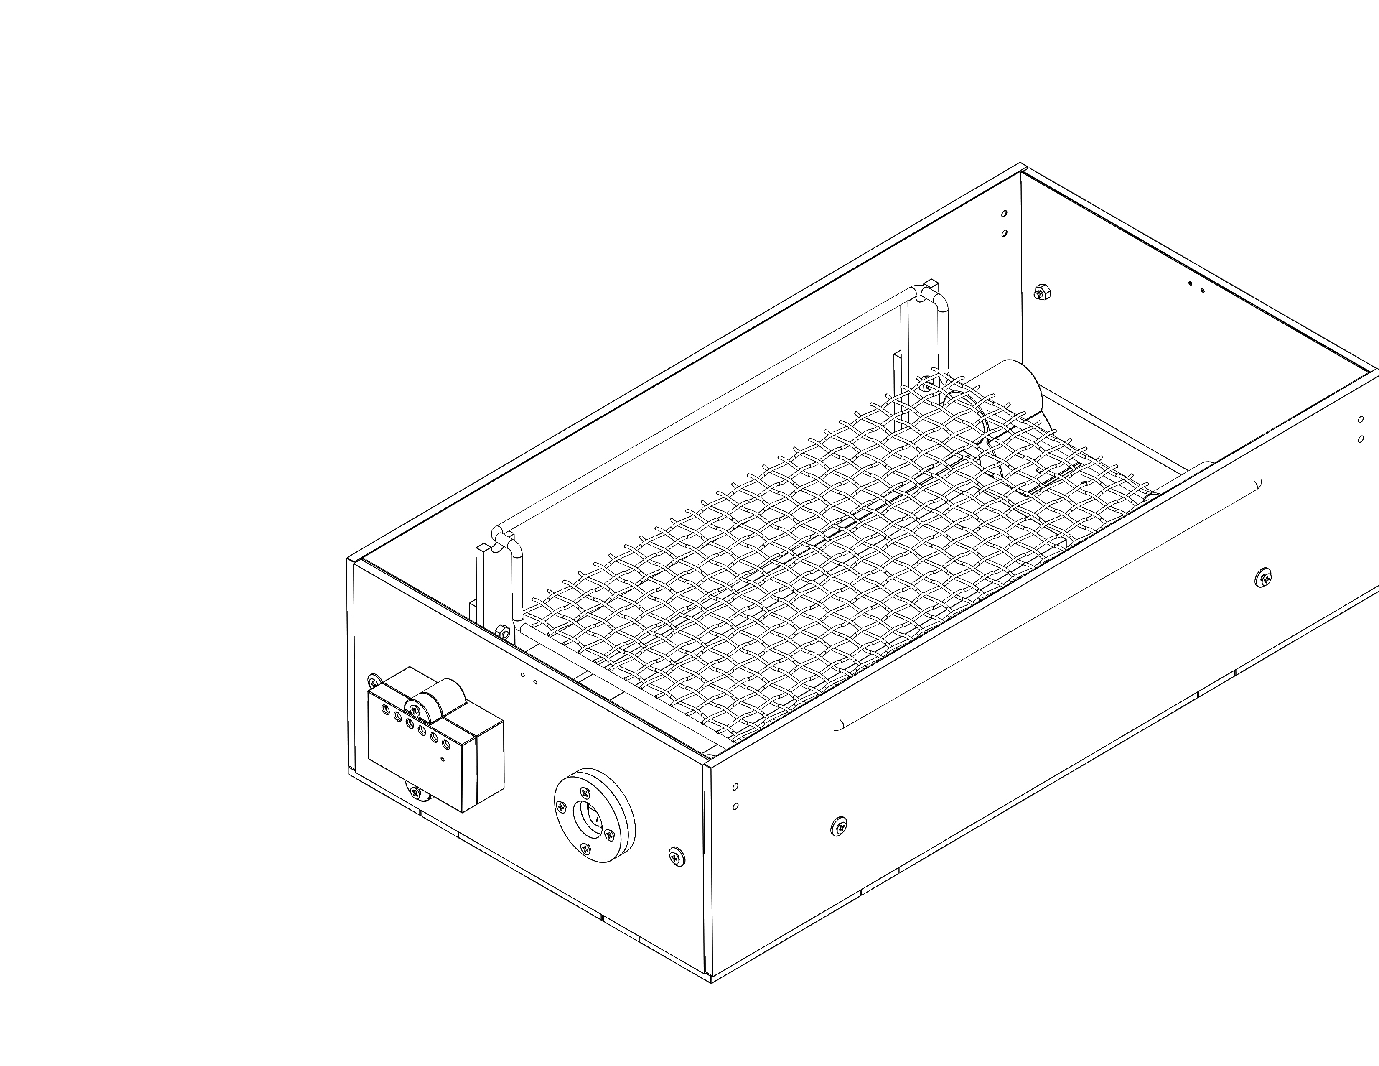
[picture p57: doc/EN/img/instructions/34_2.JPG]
   
</p>

### Put together cover plate and stopper blocks together (sub assembly)
<p float="left">
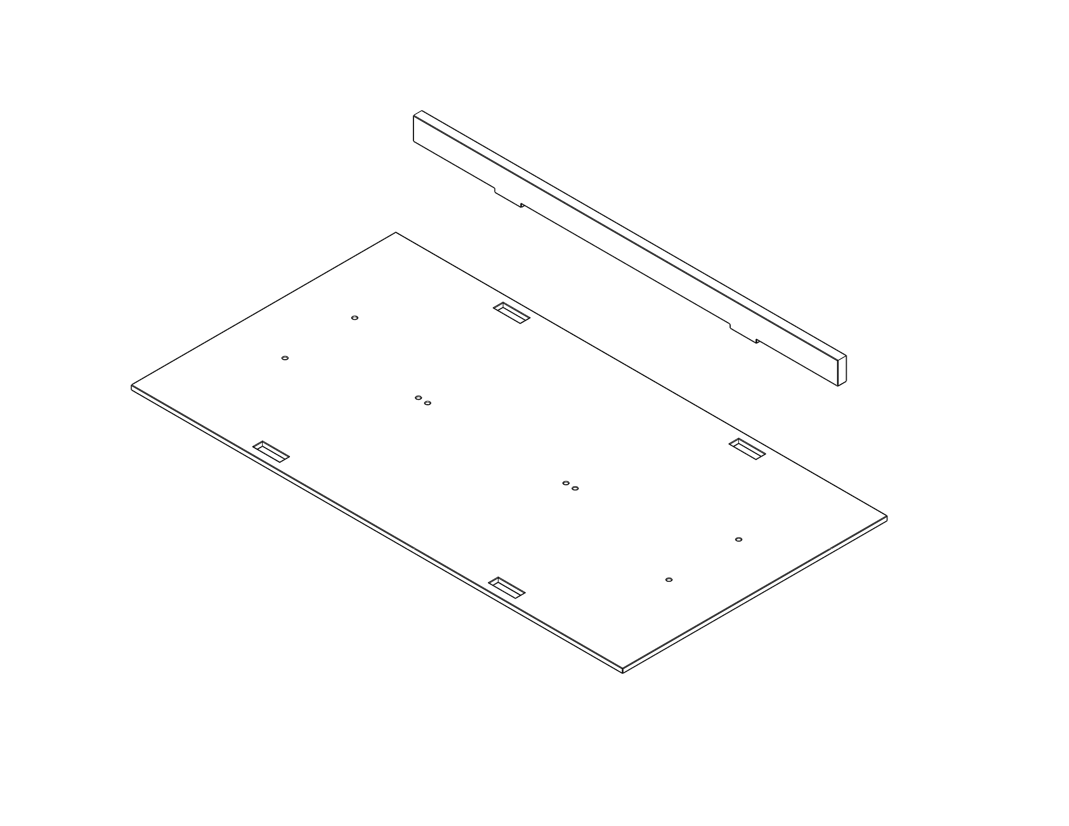
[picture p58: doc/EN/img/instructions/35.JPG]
    
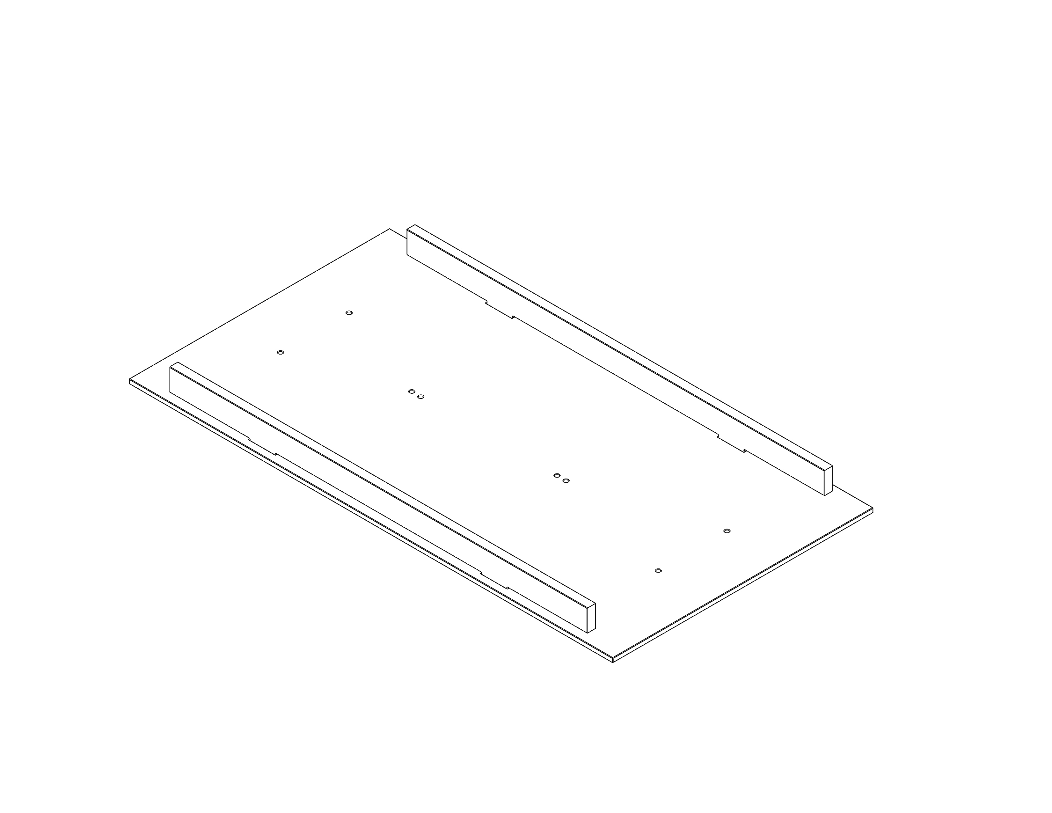
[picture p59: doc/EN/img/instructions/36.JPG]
  
</p>

### Fasten the metal handle in place in the cover plate
<p float="left">
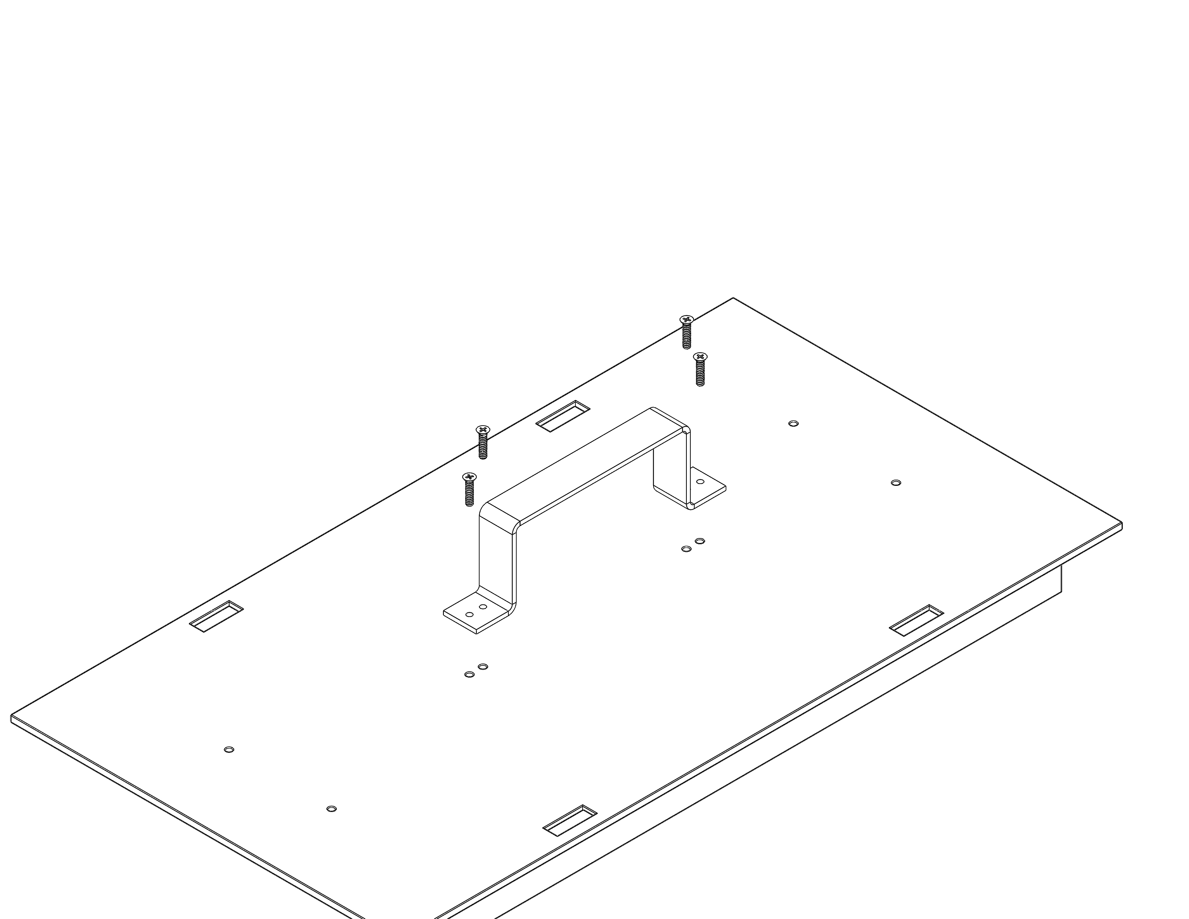
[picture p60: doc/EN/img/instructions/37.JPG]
    
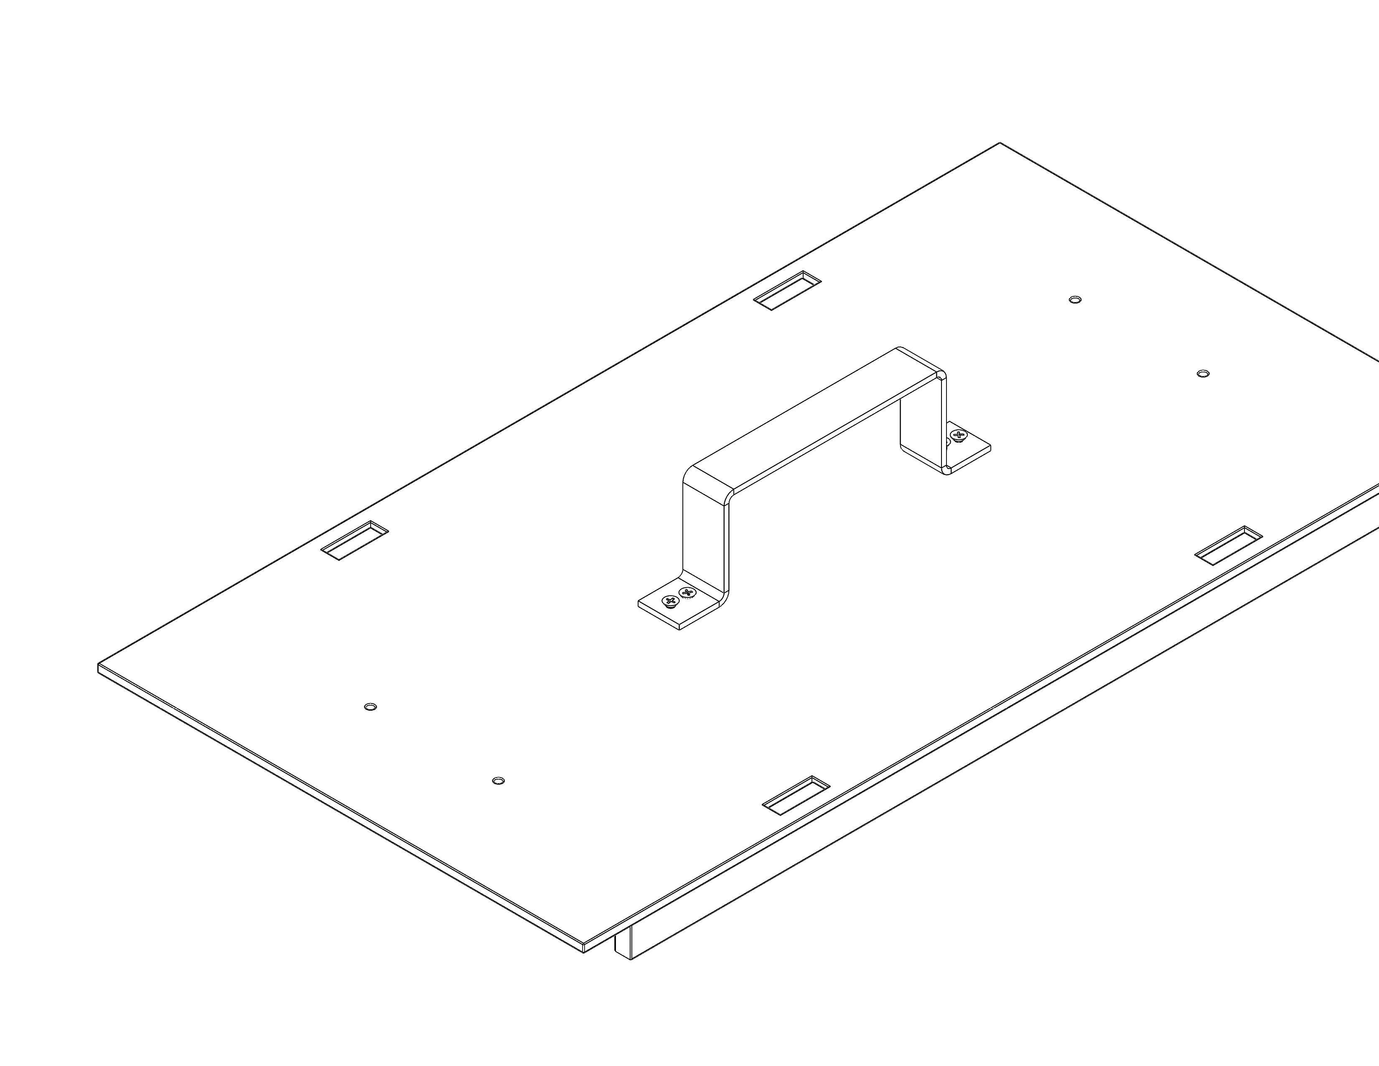
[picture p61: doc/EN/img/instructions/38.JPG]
  
</p>

### Fasten the UV lamp subassembly onto the cover plate
<p float="left">
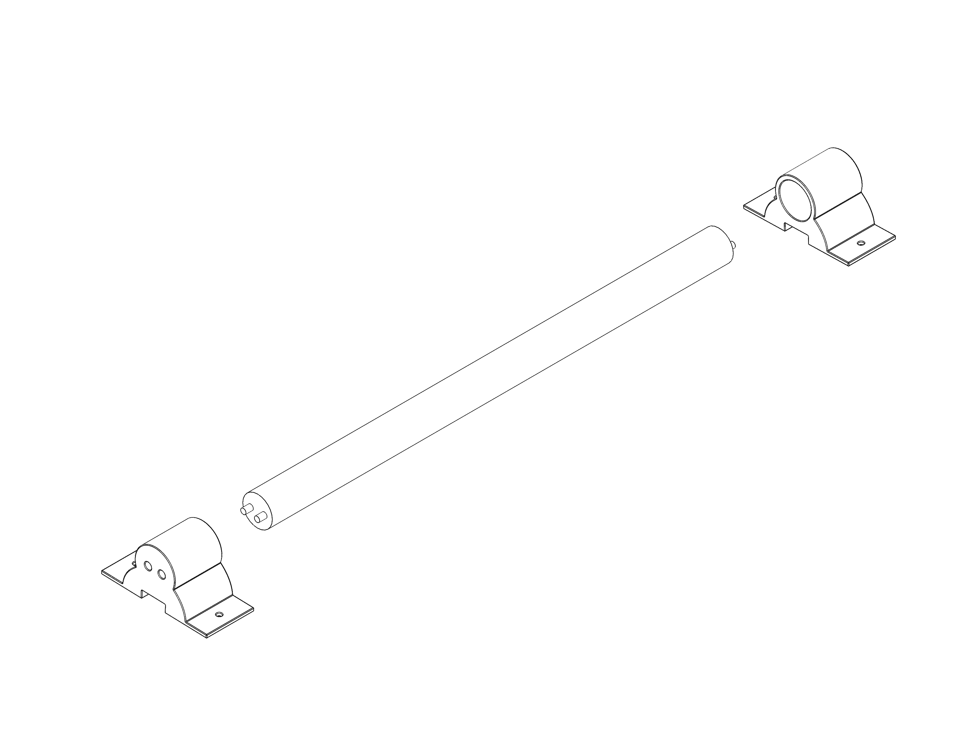
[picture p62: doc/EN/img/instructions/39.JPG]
    
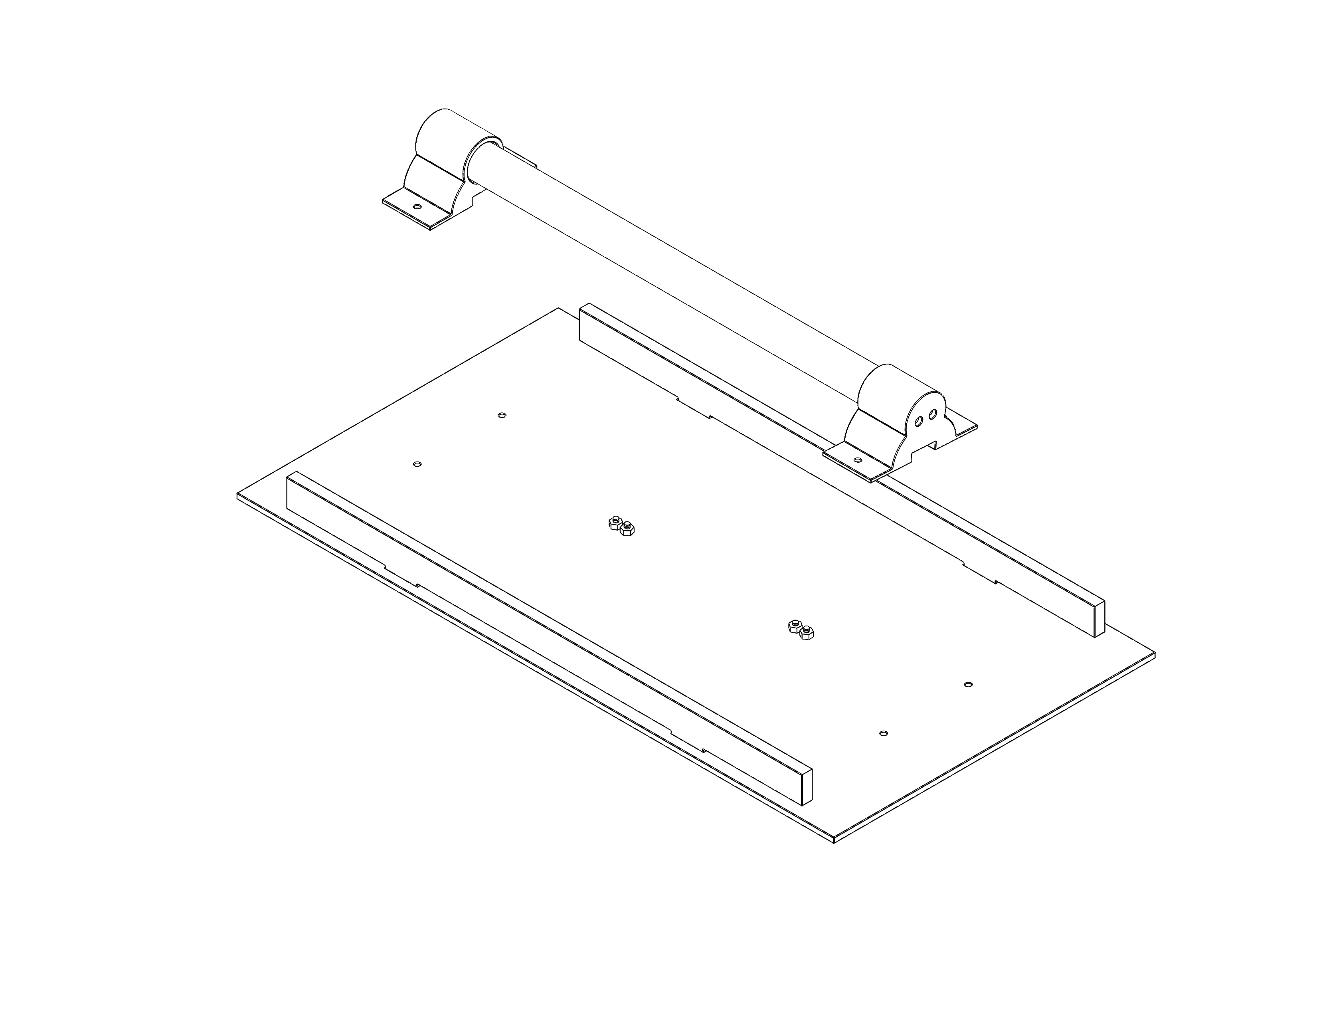
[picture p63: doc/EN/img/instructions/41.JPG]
  
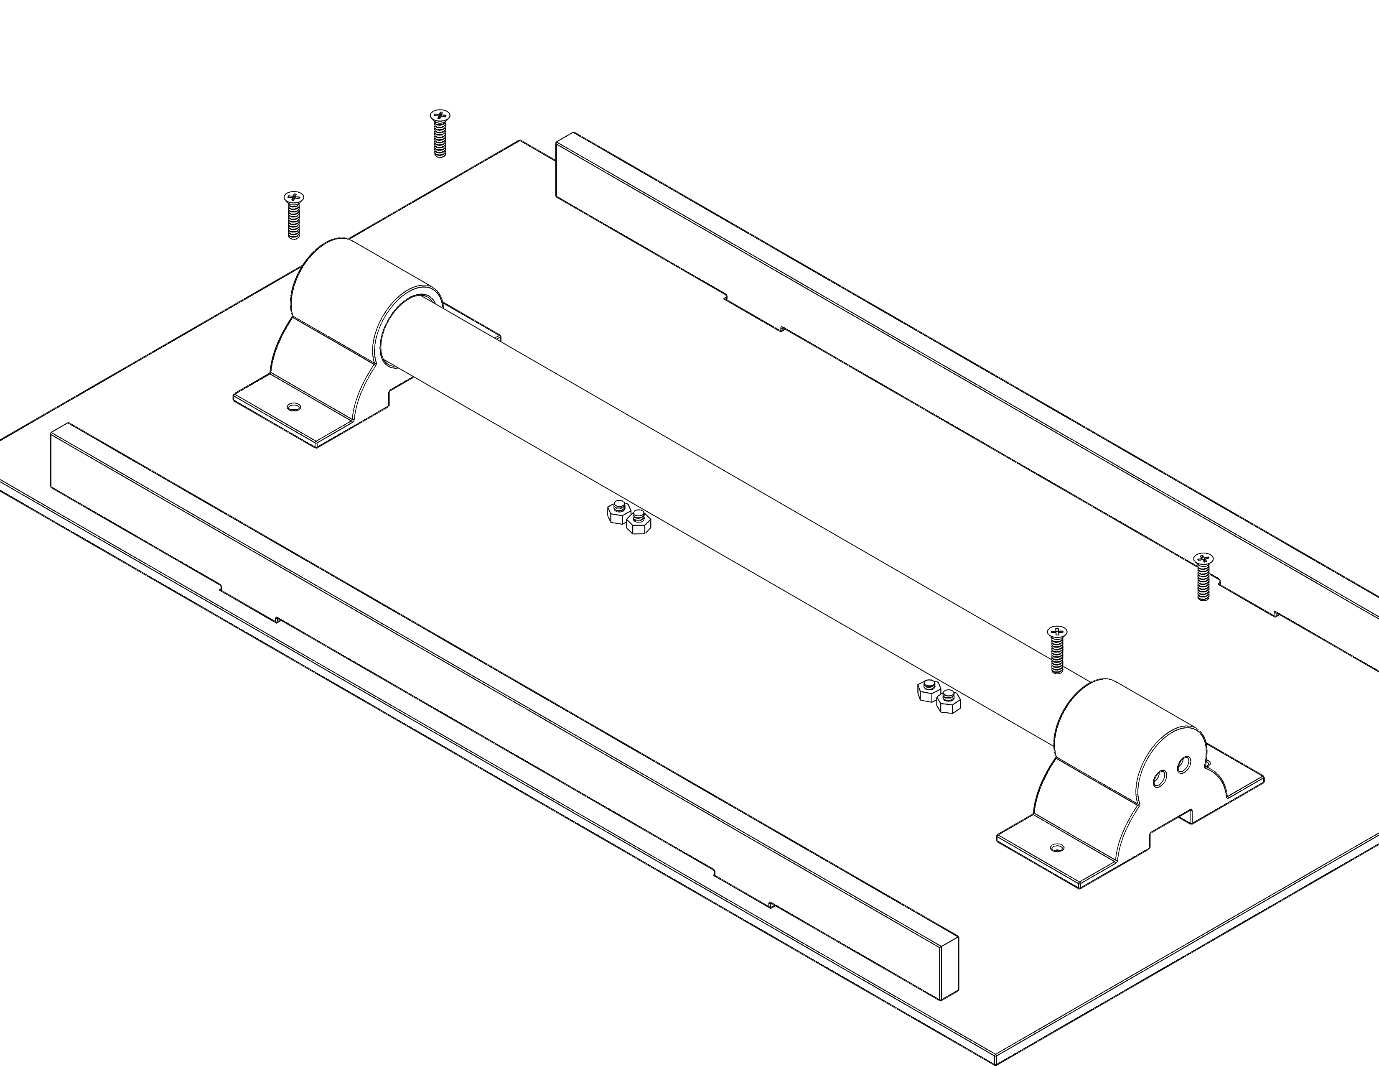
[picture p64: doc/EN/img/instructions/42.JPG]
  
  
### Place the lid over the previously assembled base 
<p float="left">
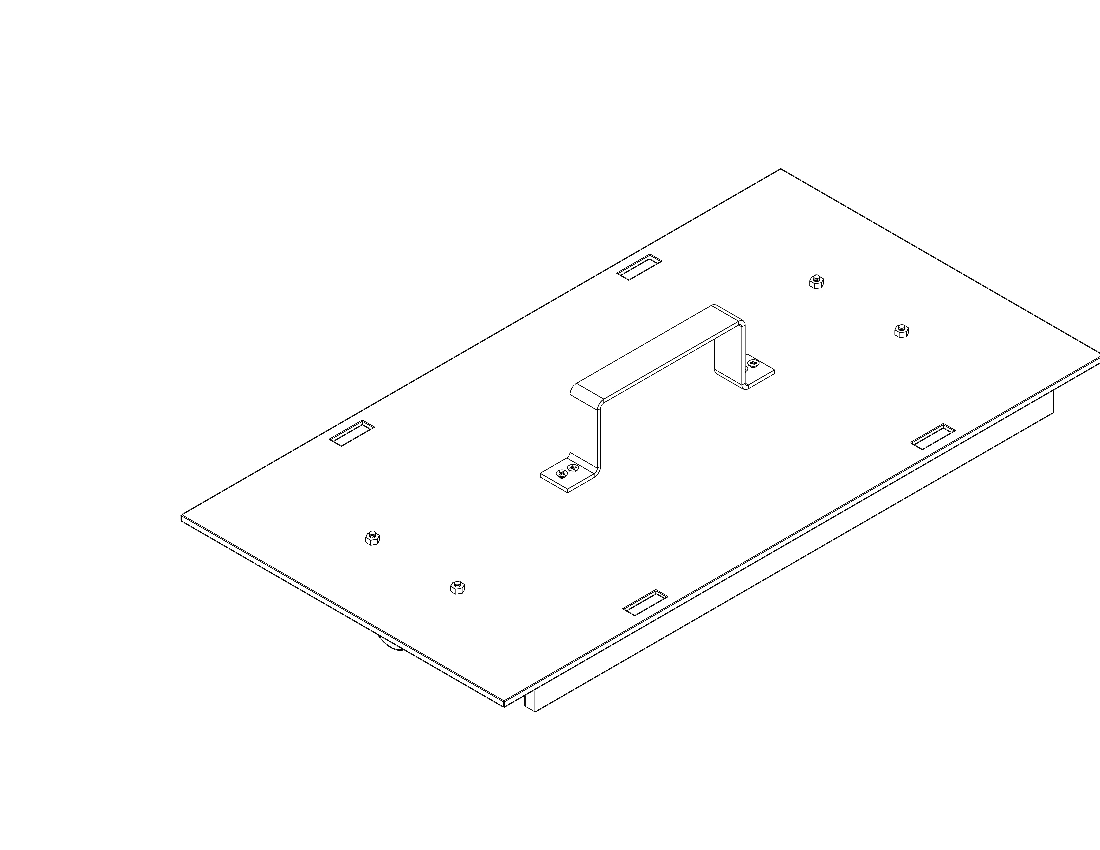
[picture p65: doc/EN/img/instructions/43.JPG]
    
  
  
</p>

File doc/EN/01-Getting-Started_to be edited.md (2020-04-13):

## Getting Started

For assembeling the main body of the device sheet metal must be cut with a lasercutter and folded. 

DFX files for cutting can be downloaded [**HERE**](https://www.ohwr.org/project/openbreath/tree/master/CAD/DXF) <!-- Replace with github link -->

The hardware files for electronics can be downloaded [**HERE**](https://www.ohwr.org/project/openbreath/tree/master/Hardware) <!-- Replace with github link -->

The dashboard files can be download [**HERE**](https://www.ohwr.org/project/openbreath/tree/master/Dashboard) <!-- Replace with github link -->

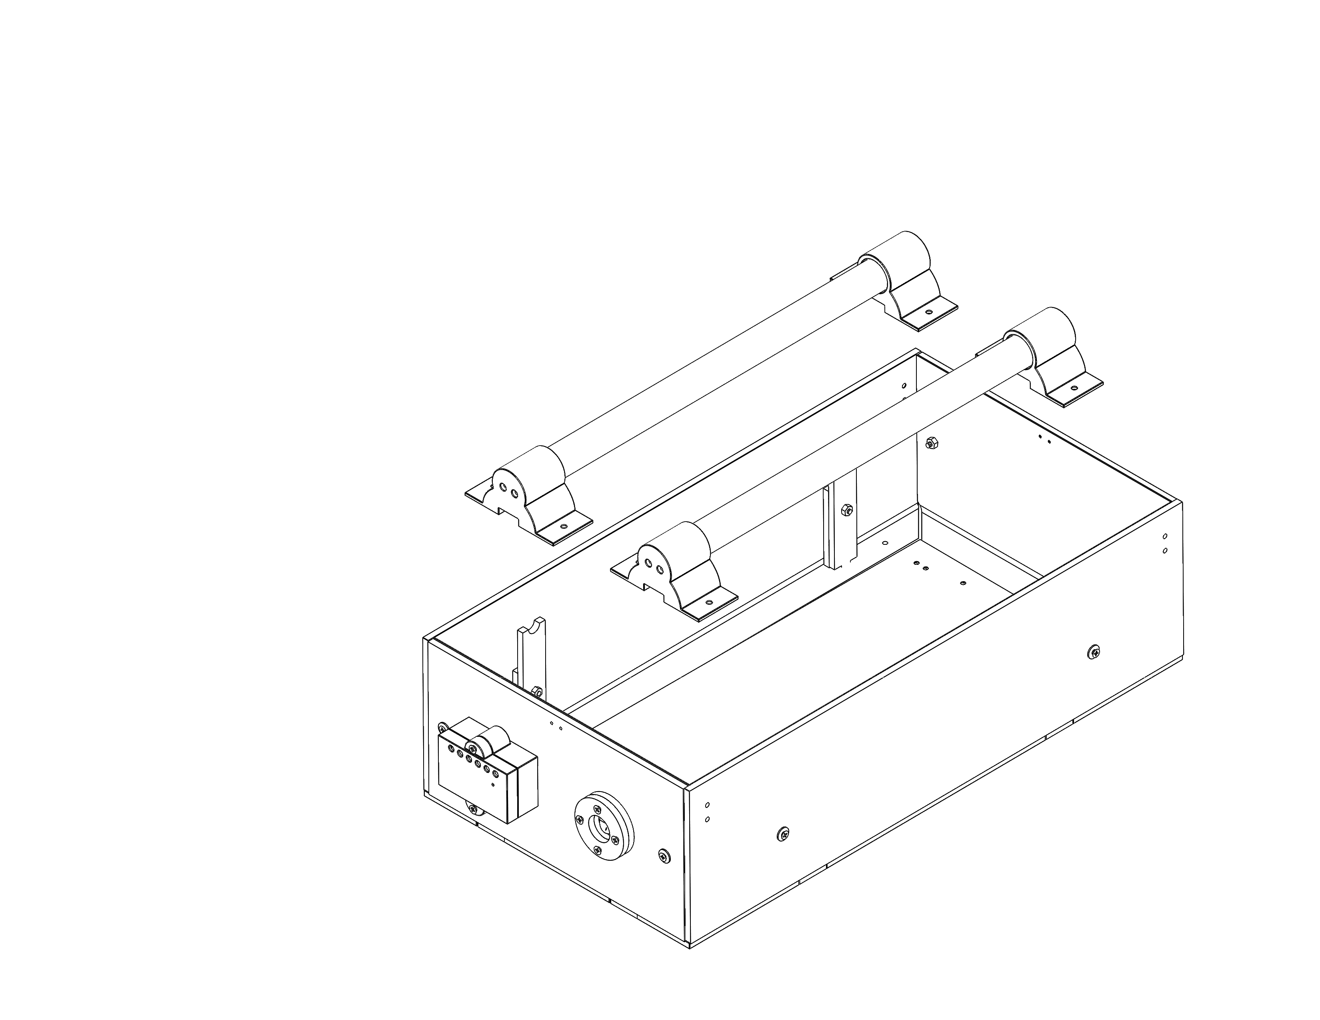
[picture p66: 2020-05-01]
doc/EN/img/instructions/31_1.JPG

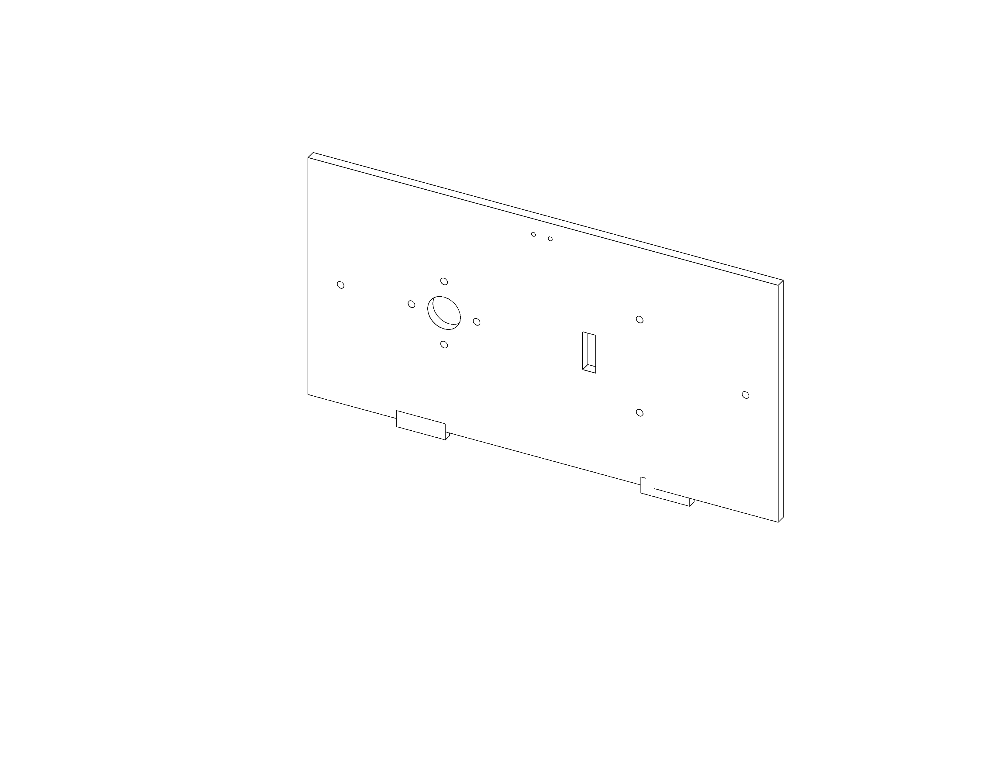
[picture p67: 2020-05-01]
doc/EN/img/instructions/4.JPG

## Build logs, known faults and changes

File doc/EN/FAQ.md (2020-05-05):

# Frequently Asked Questions (FAQs)

<details open>
<summary>What about the fact that hospitals already deep clean walls with tried and tested methods?</summary>
<br>
You can read stuff here [url](https://www.google.com/)
</details>

<hr>

<details open>
<summary>Why hold up 5-10lb wood box with a power cable when a wipe can do a better job, is cheaper, tested, can go everywhere, and disposable?</summary>
<br>
You can read stuff here [url](https://www.google.com/)
</details>

<hr>

<details open>
<summary> It can take 30 minutes for Uvc to work. You gonna hold it there that long?</summary>
<br>
You can read stuff here [url](https://www.google.com/)
</details>

<hr>

<details open>
<summary>While your waiting 30 minutes on one handle being sterilised, Why can't have the whole room cleaned With a good old fashioned disinfectant?</summary>
<br>
You can read stuff here [url](https://www.google.com/)
</details>
                                                                              
<hr>

<details open>
<summary>Disinfecting with current methods seems to meet the need. So one wonders if this is a reason solution for a problem that's not that much of a problem as it stands?</summary>
<br>
You can read stuff here [url](https://www.google.com/)
</details>

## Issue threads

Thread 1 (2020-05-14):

Battery operated steriliser - ideas

amitrajrd, 2020-05-14:
Let us discuss how the device will operate on battery.
- for example points on total power consumption

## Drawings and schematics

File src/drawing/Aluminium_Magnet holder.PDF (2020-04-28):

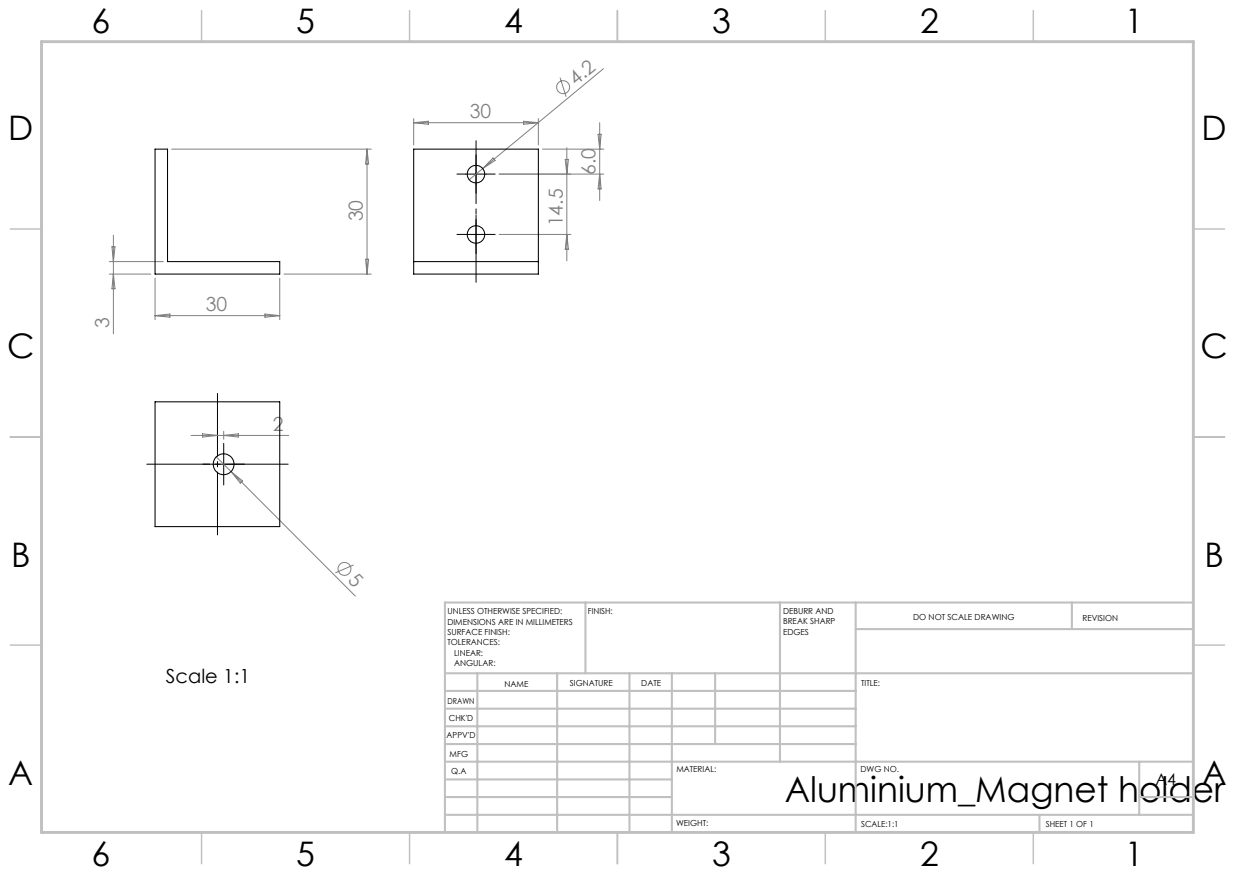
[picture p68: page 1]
Scale 1:1; FINISH:; DEBURR AND; BREAK SHARP; DO NOT SCALE DRAWING; REVISION; SCALE:1:1; SHEET 1 OF 1; Aluminium_Magnet holder

UNLESS OTHERWISE SPECIFIED:
DIMENSIONS ARE IN MILLIMETERS
SURFACE FINISH:
TOLERANCES:
LINEAR:
ANGULAR:

NAME | SIGNATURE | DATE | | | | TITLE:

DRAWN
CHK'D
APPV'D
MFG
Q.A | | | | MATERIAL: | DWG NO. | A4

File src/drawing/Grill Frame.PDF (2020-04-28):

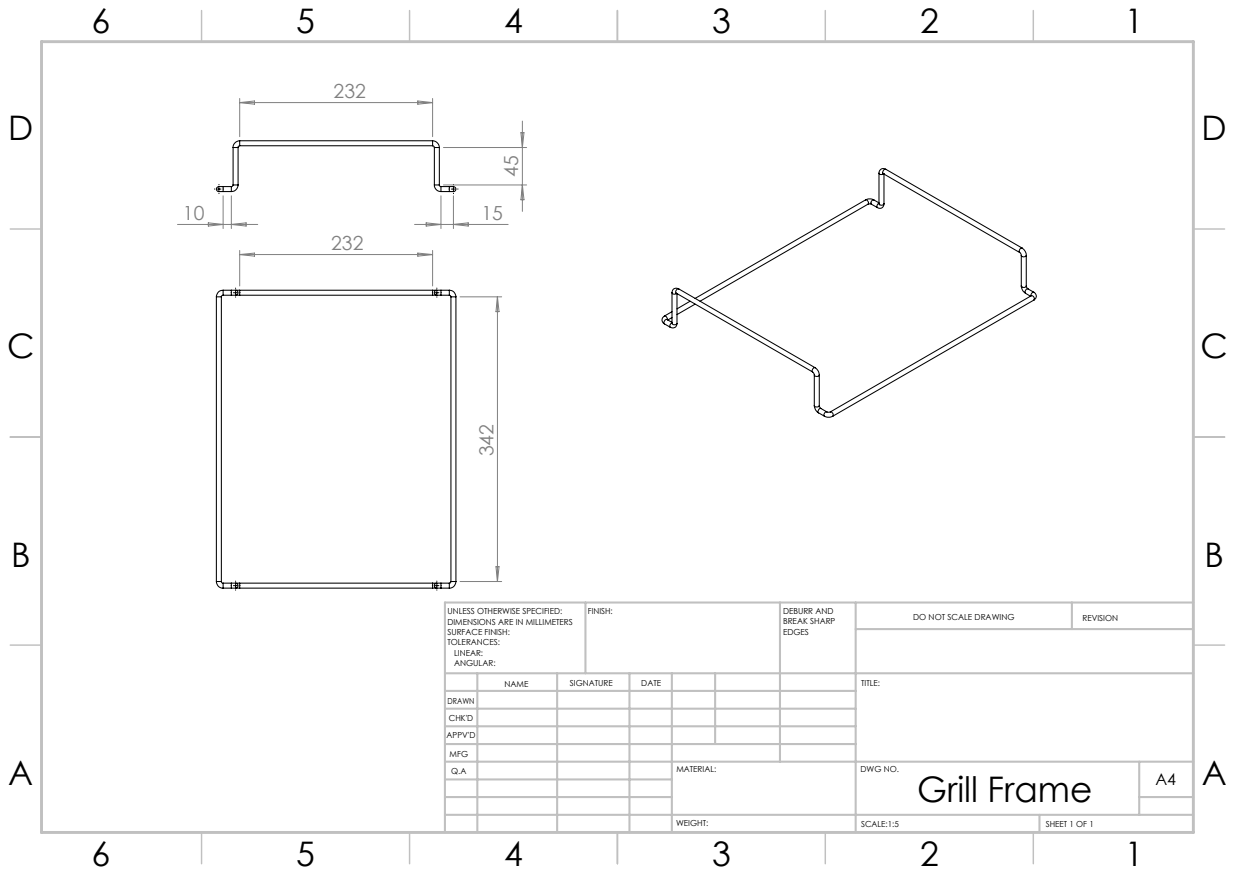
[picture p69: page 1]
FINISH:; DEBURR AND; BREAK SHARP; DO NOT SCALE DRAWING; REVISION; SCALE:1:5; SHEET 1 OF 1

UNLESS OTHERWISE SPECIFIED:
DIMENSIONS ARE IN MILLIMETERS
SURFACE FINISH:
TOLERANCES:
LINEAR:
ANGULAR:

NAME | SIGNATURE | DATE | | | | TITLE:

DRAWN
CHK'D
APPV'D
MFG
Q.A | | | | MATERIAL: | DWG NO. Grill Frame | A4

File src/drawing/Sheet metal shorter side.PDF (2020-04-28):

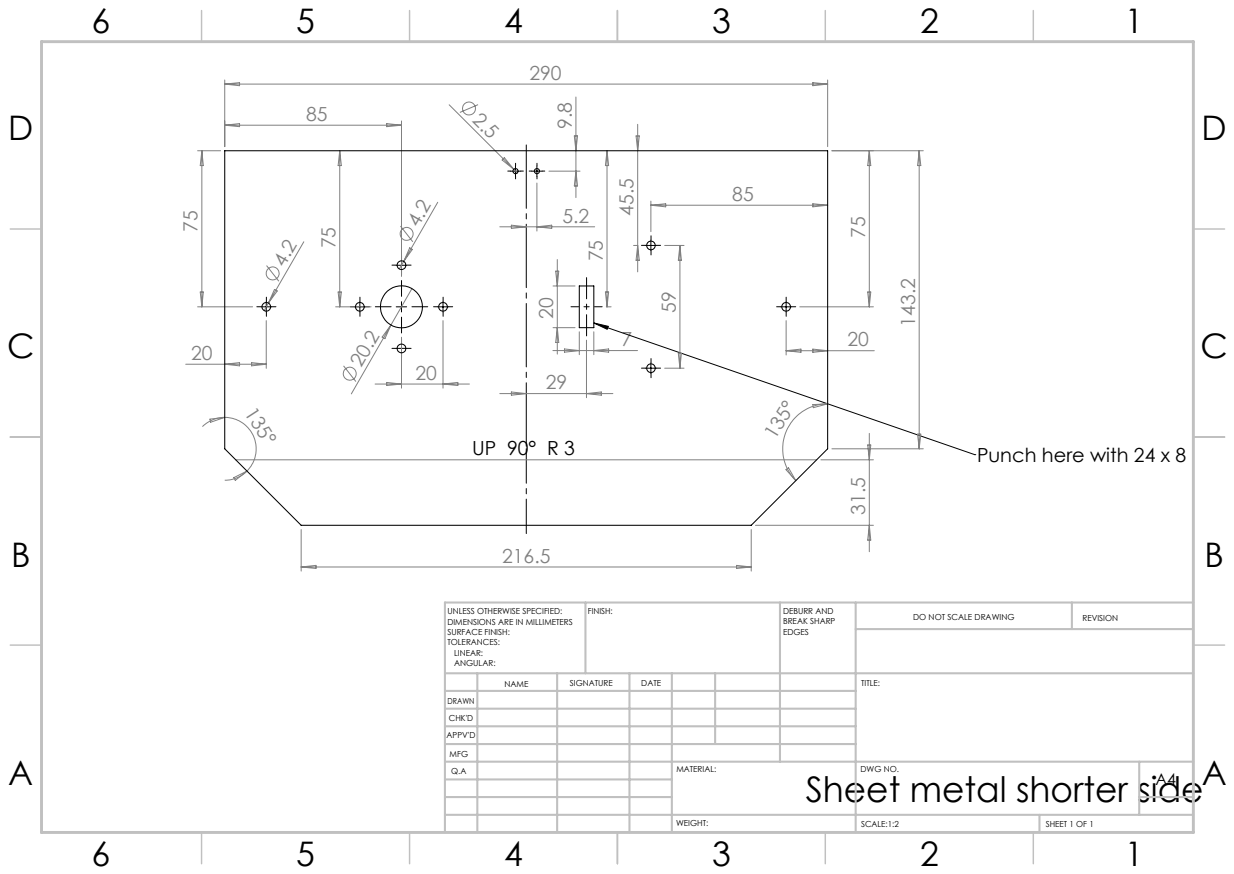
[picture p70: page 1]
Punch here with 24 x 8; FINISH:; DEBURR AND; BREAK SHARP; DO NOT SCALE DRAWING; REVISION; SCALE:1:2; SHEET 1 OF 1

UNLESS OTHERWISE SPECIFIED:
DIMENSIONS ARE IN MILLIMETERS
SURFACE FINISH:
TOLERANCES:
LINEAR:
ANGULAR:

NAME | SIGNATURE | DATE | | | | TITLE:

DRAWN
CHK'D
APPV'D
MFG
Q.A | | | | MATERIAL: | DWG NO. | A4

Sheet metal shorter side

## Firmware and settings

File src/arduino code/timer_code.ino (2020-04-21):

long int count=0;
int M=15;                                          // timer minutes
int on_off_switch=0;                               // assign pin number to main switch
int led1=1;                                        // assign pin number to led
int led2=2;
int led3=3;
int led4=4;
int led5=5;
int led6=6;
int buzzer=7;                                     // assign pin number to buzzer
int relay=9;                                      // assign pin number to uv relay
int reading;                                     // satus of on_off_switch

//long OnTime = 100;                               // milliseconds of on-time
//long OffTime = 100;                              // milliseconds of off-time



void setup() {
  TCCR1A = 0;                                   // intialisng timer registers
  TCCR1B = 0; 
  bitSet(TCCR1B, CS12);                        // 256 prescaler
  bitSet(TIMSK1, TOIE1);                       // timer overflow interrupt enable  

  pinMode(on_off_switch, INPUT);               // initialize digital pin switch as input.
  pinMode(led1, OUTPUT);                       // initialize digital pin LED as an output.
  pinMode(led2, OUTPUT);
  pinMode(led3, OUTPUT);
  pinMode(led4, OUTPUT);
  pinMode(led5, OUTPUT);
  pinMode(led6, OUTPUT);
  pinMode(buzzer,OUTPUT);                     // initialize digital pin buzzer as an output.
  pinMode(relay, OUTPUT);                     // initialize digital pin relay as an output.
}



ISR(TIMER1_OVF_vect) { 
  reading = digitalRead(on_off_switch);
  
  count++;
  if(count==59)
  {
  M--;
  count=0;
  }

  if(reading ==HIGH)
  {
  digitalWrite(led6, HIGH);                  // turn the LED6 on
  digitalWrite(relay, HIGH);                // turn the relay for UV on
  
  if((M<=15)&&(M>12))
  digitalWrite(led1, !digitalRead(led1));

  if((M<=12)&&(M>9))
 {
  digitalWrite(led1, HIGH);                 // turn the LED1 is stable on
  digitalWrite(led2, !digitalRead(led2));
 }

  if((M<=9)&&(M>6))
 {
  digitalWrite(led1, HIGH);                 // turn the LED1 is stable on 
  digitalWrite(led2, HIGH);                 // turn the LED2 is stable on
  digitalWrite(led3, !digitalRead(led3)); 
 }

  if((M<=6)&&(M>3))
 {
  digitalWrite(led1, HIGH);                 // turn the LED1 is stable on 
  digitalWrite(led2, HIGH);                 // turn the LED2 is stable on
  digitalWrite(led3, HIGH);                 // turn the LED3 is stable on
  
  digitalWrite(led4, !digitalRead(led4));  
 }

 if((M<=3)&&(M>0))
 {
  digitalWrite(led1, HIGH);                 // turn the LED1 is stable on 
  digitalWrite(led2, HIGH);                 // turn the LED2 is stable on
  digitalWrite(led3, HIGH);                 // turn the LED3 is stable on
  digitalWrite(led4, HIGH);                 // turn the LED4 is stable on
  
  digitalWrite(led5, !digitalRead(led5));
 }

 if(M<=0)
 {
  digitalWrite(led1, HIGH);                 // turn the LED1 is stable on 
  digitalWrite(led2, HIGH);                 // turn the LED2 is stable on
  digitalWrite(led3, HIGH);                 // turn the LED3 is stable on
  digitalWrite(led4, HIGH);                 // turn the LED4 is stable on 
  digitalWrite(led5, HIGH);                 // turn the LED5 is stable on

  digitalWrite(buzzer, HIGH);               // turn the buzzer on
  digitalWrite(relay, LOW);                // turn the relay off

 }
}
else
  {
  digitalWrite(led1, LOW);                 // turn the LED1 OFF 
  digitalWrite(led2, LOW);                 // turn the LED2 OFF
  digitalWrite(led3, LOW);                 // turn the LED3 OFF
  digitalWrite(led4, LOW);                 // turn the LED4 OFF 
  digitalWrite(led5, LOW);                 // turn the LED5 OFF
  digitalWrite(led6, LOW);                 // turn the LED6 OFF
  digitalWrite(buzzer, LOW);               // turn the buzzer OFF
  digitalWrite(relay, LOW);                // turn the relay off
  M=15;
  count=0;
  }

}



void loop() { 
  

  // any other useful works like monitoring temp when UV is ON could be written here
  
  }
